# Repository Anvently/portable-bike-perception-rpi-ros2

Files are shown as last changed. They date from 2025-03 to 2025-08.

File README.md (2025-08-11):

# Cyclo-safe : a multi-sensor bike perception module (Camera, Dual 360° Lidar, GPS, Raspberry Pi, ROS2)

> The aim of the CycloSafe project is to improve cyclist safety by rigorously quantifying the risks they face, with a particular focus on those occurring when being overtaken by a motor vehicle.
> 
> To do this, we have equipped a bicycle with LIDARs (Light Detection and Ranging), a camera and a GNSS antenna.

This repository contains :
- the firmware intended to run on a **Raspberry Pi** to operate all the sensors and **take measurements**
- Various tools to **export**, **visualize**, and **analyze** the collected data
- Files required for **3D printing the case**
- File needed to manufacture the **dedicated PCB**.  
It was developed as part of an experimental data acquisition system for an academic research study on cyclist safety.

https://github.com/user-attachments/assets/d5b68dda-f3fe-4f50-86e3-c243446fb8e7

## Structure

> [**core/**](core/README.md): Directory intended to be installed on the Raspberry Pi. Contains:
> 	- ROS installation script
> 	- CycloSafe environment setup script
> 	- systemd services setup script
> 	- source code for the different ROS nodes

> [**design/**](design/README.md): Contains files related to the machining of the case and the dedicated PCB.

> [**scripts/**](scripts/README.md): Contains scripts useful for retrieving and exporting data.

> [**viewer/**](viewer/README.md): Directory intended to be installed on the host machine. Contains a set of tools for visualizing and analyzing the data.
> - [**ROS2.md**](viewer/ROS2.md): Documentation related to ROS2 and its use in the project.

> [**network.md**](network.md): Instructions for network configuration on both the host and the Raspberry Pi, enabling interaction between the two machines.

## About the Cyclo-safe project

This project is part of the broader **CycloSafe** research initiative conducted at the **Institut national de l’information géographique et forestière (IGN)**, which aims **to quantify the risks faced by cyclists when being overtaken by motor vehicles**.

This repository is dedicated **exclusively to the design and implementation of the acquisition module** used to collect measurement data for the study, along with a set of **tools for processing, visualizing, and analyzing** the recorded data.

It does **not** present or discuss the **results** of the study itself, and should not be directly associated with its conclusions or interpretations.

For more information on the full **CycloSafe** study, see:  
Emmanuel Cledat, Dirk Lauinger, Aymeric Dutremble, Maeve Blarel, Damien Louis Peller, Tristan Geslain, Alexandre Esteoulle, Elisabeth Giroux, Gabin Bourlon, Nicolas Pirard, Eric Ta — ***Cyclo-Safe: Quantitative study of the risks to which cyclists are exposed during their daily commute***.

## License

This project is licensed under the **CeCILL-B v1** license, a free software license fully compliant with French law, **based on the BSD 2-Clause license** and the principles of open source.

**Scope of the license** — The following materials are covered by the CeCILL-B license:
- Firmware code based on ROS2
- All project installation scripts and data analysis scripts
- Source code of data analysis tools, based on Qt and ROS2
- PCB design files
- 3D models and any corresponding f3d source files
- Assembly and user manuals for the module

You are **free to**:
- Use, modify, and redistribute this project under the terms of the CeCILL-B license
- Use this project for both **academic** and **commercial** purposes, without the strong copyleft constraints of GPL-like licenses
- Incorporate this code into proprietary software, as long as you respect the attribution requirements

You must:
- Include a copy of the CeCILL-B license with any redistributed version
- Retain notices of authorship and copyright
- Clearly indicate any modifications made

Author: [Nicolas Pirard (@Anvently)](https://github.com/Anvently)  
Contact: [pirard.nicolas@hotmail.fr](mailto:pirard.nicolas@hotmail.fr)  
Additional contributors: See [CONTRIBUTORS.md](./CONTRIBUTORS.md)

📄 Full license text: [CeCILL-B v1](http://www.cecill.info/licences/Licence_CeCILL-B_V1-en.html)  

📄 French version: [CeCILL-B v1](https://cecill.info/licences/Licence_CeCILL-B_V1-fr.html)  

---

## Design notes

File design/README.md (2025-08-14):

# Cyclosafe design

Ce dossier contient les fichiers relatifs à la fabrication du boitier destiné à recevoir tous les composants ainsi que les fichiers de fabrication du PCB dédié.

- [Cyclosafe design](#cyclosafe-design)
- [Liste du matériel (BOM)](#liste-du-matériel-bom)
	- [COMPOSANTS](#composants)
	- [Quincaillerie](#quincaillerie)
	- [Inserts](#inserts)
	- [Total](#total)
- [Electronique](#electronique)
	- [Montage complet](#montage-complet)
	- [PCB dédié](#pcb-dédié)
		- [Fonctions](#fonctions)
		- [Schéma](#schéma)
		- [Aperçu](#aperçu)
- [Boitier imprimé en 3D](#boitier-imprimé-en-3d)
	- [Module waveshare UPS hat](#module-waveshare-ups-hat)
		- [Spécifications](#spécifications)
		- [Aperçu](#aperçu-1)
- [Fixation au vélo](#fixation-au-vélo)
- [Module de mesure amovible](#module-de-mesure-amovible)
	- [Partie haute](#partie-haute)
	- [Partie basse](#partie-basse)

---

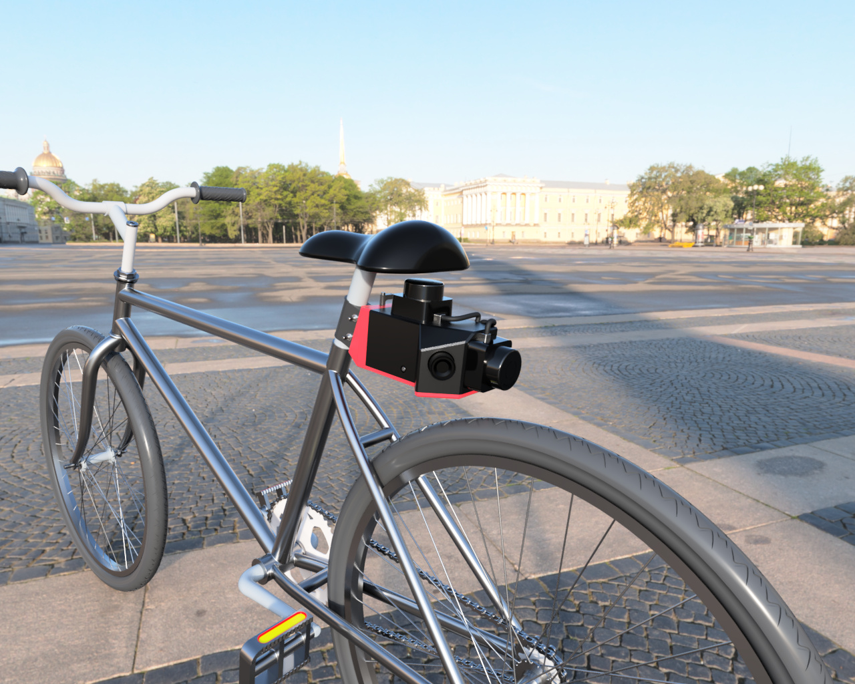
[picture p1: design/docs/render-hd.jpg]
preview-velo-avec-module


https://github.com/user-attachments/assets/05b4201d-2b15-44bb-a8c5-ab20a0cb3d47

# Liste du matériel (BOM)

## COMPOSANTS

| Quantité | Nom de la pièce | Fonction | Masse (g) | Type | Origine | Coût estimé |
|---|---|---|---|---|---|---|
| 1 | Raspberry Pi 4 Model B | Firmware | 75.00 | PCB | Achat | 65.00 |
| 1 | UPS-HAT | Batterie | 120.00 | PCB | Achat | 22.00 |
| 1 | PCB custom | Électronique | 30.00 | PCB | Fabrication par un tiers | 8.75 |
| 1 | Raspberry Pi HQ Camera M12 mount | Capteur | 30.40 | Capteur | Achat | 52.00 |
| 1 | Objectif grand angle M12 | Capteur | 100 | Accessoire | Achat | 25.00 |
| 2 | Slamtec RPLiDAR C1 | Capteur | 110.00 | Capteur | Achat | 84.00 |
| 1 | Assemblage F | Fixation | 90.00 | Structure | Impression | 2.00 |
| 1 | Collier | Fixation | 37.00 | Structure | Impression | 0.5 |
| 1 | L76x GPS Module | Capteur | 5.00 | PCB | Achat | 15.00 |
| 1 | Boîtier bas | Structure | 130.00 | Structure | Impression | 1.89 |
| 1 | Boîtier haut | Structure | 101.00 | Structure | Impression | 2.23 |
| 1 | Carte SD | Firmware | 2.00 | Accessoire | Achat | 25.00 |
| 2 | Accu 18650 - 3400mAh | Batterie | 46.00 | Accessoire | Achat | 18.50 |
| 1 | Couvercle carte SD | Structure | 3.30 | Structure | Impression | 0.07 |
| 1 | Ficelle pour pin de verrouillage (diamètre < 2mm) | Fixation | 1.00 | Accessoire | Achat | 0.05 |
| 1 | Pin de verrouillage | Fixation | 1.65 | Structure | Impression | 0.05 |
| 1 | Câble molex picoblade 510210800 8-pin double-M 20cm | Connection gps-pcb | 2.00 | Accessoire | Achat | 0.50 |

## Quincaillerie

| Quantité | Nom de la pièce | Fonction | Masse (g) | Type | Origine | Coût estimé |
|---|---|---|---|---|---|--|
| 1 | Vis à tête hexagonale M2.5x6 | Trappe carte SD | 0.487 | Quincaillerie | Achat | 0.05
| 4 | Entretoise M/F M2.5x12 | Entretoise Raspberry | 1.999 | Quincaillerie | Achat | 0.50
| 4 | Entretoise M/F M2.5x18 | Entretoise HAT | 2.393 | Quincaillerie | Achat | 0.50
| 8 | Vis à tête hexagonale M2.5x12 | Lidars | 0.702 | Quincaillerie | Achat | 0.05
| 2 | Vis à tête hexagonale M2x8 | GPS | 0.341 | Quincaillerie | Achat | 0.05
| 3 | Vis à tête hexagonale M3x6 | Boîtiers | 0.796 | Quincaillerie | Achat | 0.05
| 8 | Vis à tête hexagonale M2.5x10 | UPS HAT & caméra | 0.630 | Quincaillerie | Achat | 0.05
| 1 | Vis à tête hexagonale M3x0.5x40 | Axe centrale du pin de blocage | 2.569 | Quincaillerie | Achat | 0.10
| 2 | Vis à tête hexagonale M4x0.7x40 | Collier | 4.776 | Quincaillerie | Achat | 0.10

## Inserts

| Quantité | Nom de la pièce | Fonction | Masse (g) | Type | Origine | Coût estimé
|---|---|---|---|---|---|--|
| 2 | Insert M4x8x6 | Collier | 2.00 | Quincaillerie | Achat | 0.08
| 1 | Insert M3x4x4.5 | Emboîtement supérieur | 1.00 | Quincaillerie | Achat | 0.05
| 2 | Insert M3x3x4.5 | Emboîtement latéral | 1.00 | Quincaillerie | Achat | 0.04
| 4 | Insert M2.5x4x3.5 | Raspberry | 1.00 | Quincaillerie | Achat | 0.04
| 2 | Insert M2x5x3.5 | GPS | 1.00 | Quincaillerie | Achat | 0.04
| 5 | Insert M2.5x5x3.5 | Couvercle SD + caméra | 1.00 | Quincaillerie | Achat | 0.04

## Total

| Quantité | Nom de la pièce | Fonction | Masse (g) | Type | Origine |Coût estimé
|---|---|---|---|---|---|--|
|Poids|||1102.25||
|Coût||||||431.17€

# Electronique

Le coeur du boitier comporte un assemblage de 3 circuits imprimés emboités les uns par desus les autres :
- un rapbeerry Pi 4B sur lequel vient se brancher la caméra
- un PCB personnalisé sur lequel vient se brancher les capteurs (2 LiDARS + un module GNSS)
- un module UPS (*Uninterruptible Power Supply*) alimentés par deux accus 18650 permettant de fournir le courant nécessaire (jusqu'à 3A), de protéger le circuit et de gérer la recharge

## Montage complet

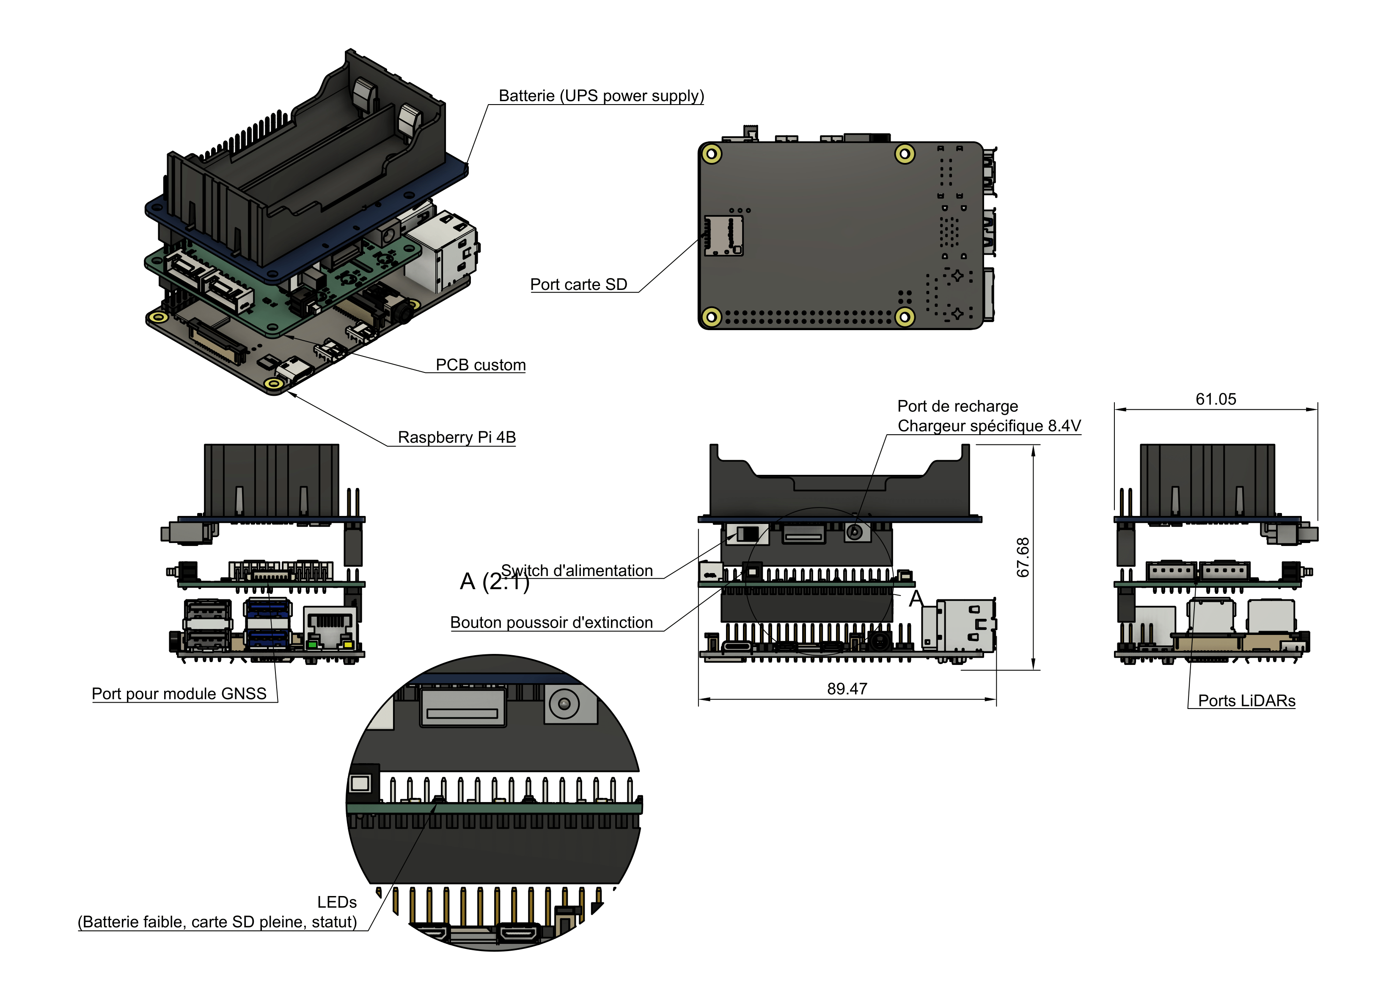
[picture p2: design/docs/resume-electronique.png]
assemblage-hat


## PCB dédié

 ### Fonctions
- permet de connecter les capteurs aux différentes interfaces UARTs du raspberry :
  - UART1 : LiDAR 1 (supérieur)
  - UART2 : LiDAR 2 (arrière)
  - UART5 : module GNSS
- intègre 3 LEDs pour avertir l'utilisateur des situations suivantes :
  - batterie faible (< 20 %) : voyant rouge allumé
  - carte sd pleine : voyant bleu allumé
  - démarrage/arrêt en cours : voyant jaune allumé sans clignotement
  - mesure en cours : voyant jaune clignotant
- intègre un bouton poussoir permettant de déclencher l'arrêt des mesures et d'éteindre en douceur le raspberry

### Schéma

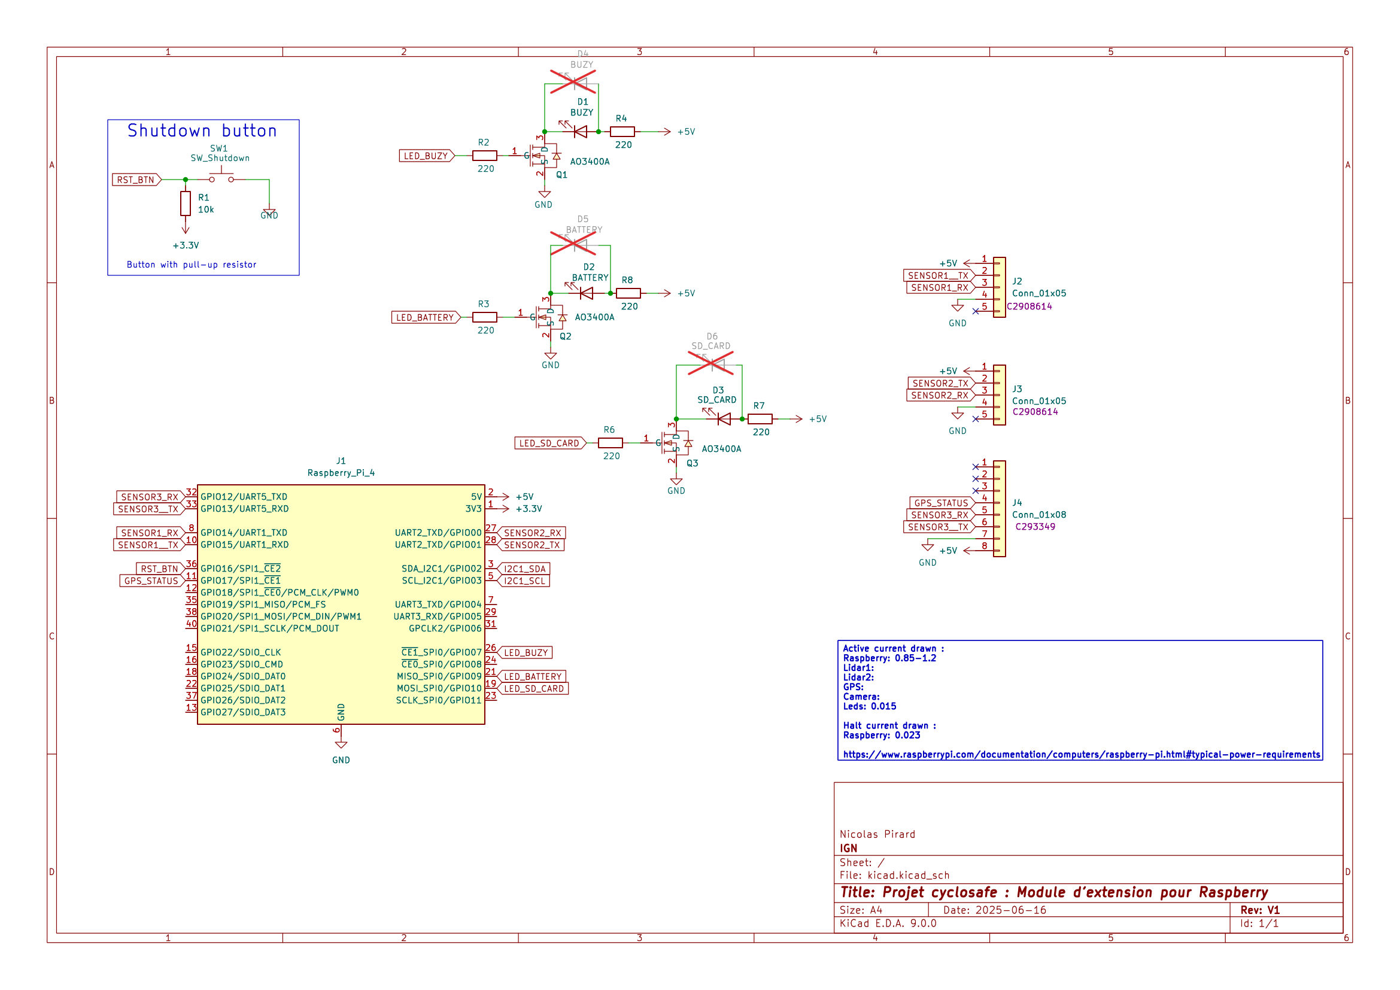
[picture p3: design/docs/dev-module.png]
schéma-circuit


### Aperçu

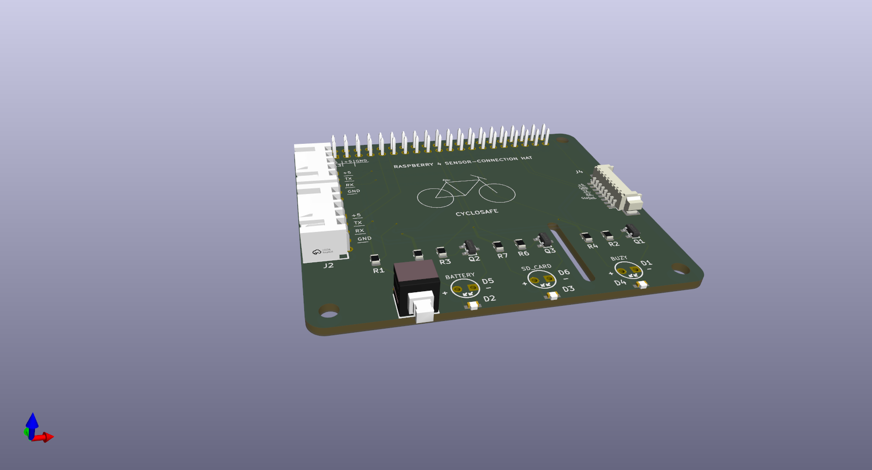
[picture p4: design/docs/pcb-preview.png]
preview-du-pcb


# Boitier imprimé en 3D

Le dossier [`kicad/`](kicad/) contient le projet Kicad 9.0 d'un PCB sur lequel viennent se brancher les différents capteurs et composants actifs (LEDs et bouton d'extinction).

Il prend la forme d'un hat pour raspberry et se connecte via le header de 40 pins.

## Module waveshare UPS hat

Il s'agit d'une alimentation non interruptible commercialisée par Waveshare.

### Spécifications

- alimenté par 2 accus 18650
- permet une utilisation constante du raspberry via batterie ou pendant la recharge sur secteur
- protection contre les court-circuits, polarité inversée, surcharge/décharge des batterie
- jusqu'à 2.5A en 5V
- monitoring de la tension des batteries (permettant de calculer le pourcentage restant) et de la consommation instantanée

### Aperçu

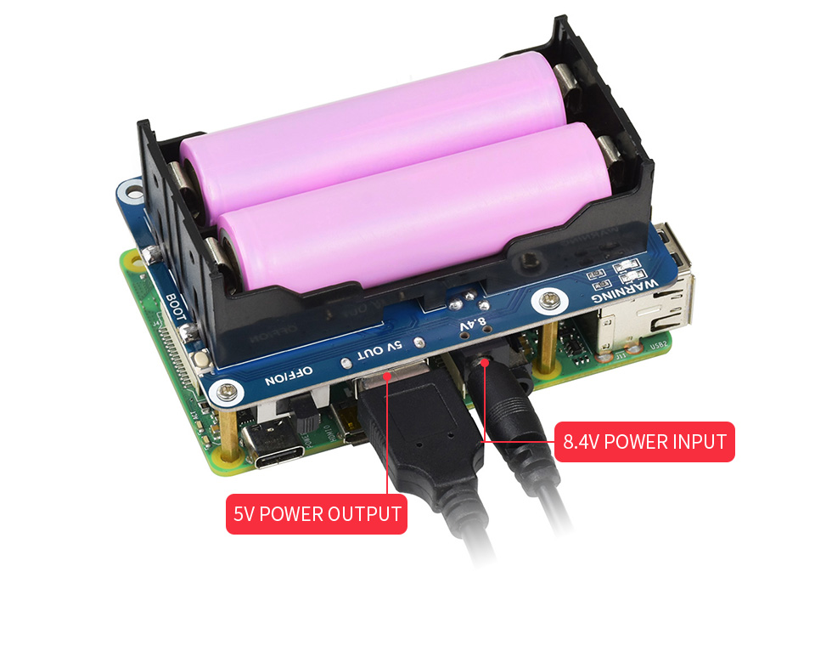
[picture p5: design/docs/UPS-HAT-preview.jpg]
Waveshare-ups-hat-preview


# Fixation au vélo

Cette partie là demeure sur la tige selle.

Un collier facilement déformable est placé autour de la tige selle et vient verrouiller l'assemblage femelle avec deux vis M4.

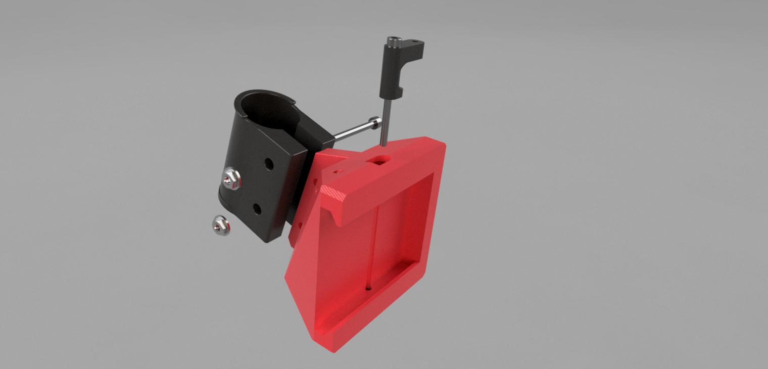
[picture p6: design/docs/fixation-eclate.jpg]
preview-fixation


Le design du  collier est basé sur  par [**<ins>un modèle réalisé par Metamere</ins>**](https://www.printables.com/model/125810-bens-better-dropper-post-seat-bag-adapters-264-22-)  trouvé sur *printables.com* et distribué sous licence Creative Commons.

Il a été allongé, épaissi et simplifié par rapport au modèle original.

Le sytème de fixation est inspiré de celui du projet Open Source [**<ins>Open bike sensor</ins>**](https://github.com/openbikesensor/OpenBikeSensor3dPrintableCase), en particulier le système de glissière entre le support fixe demeurant sur la tige selle et le boitier principal.

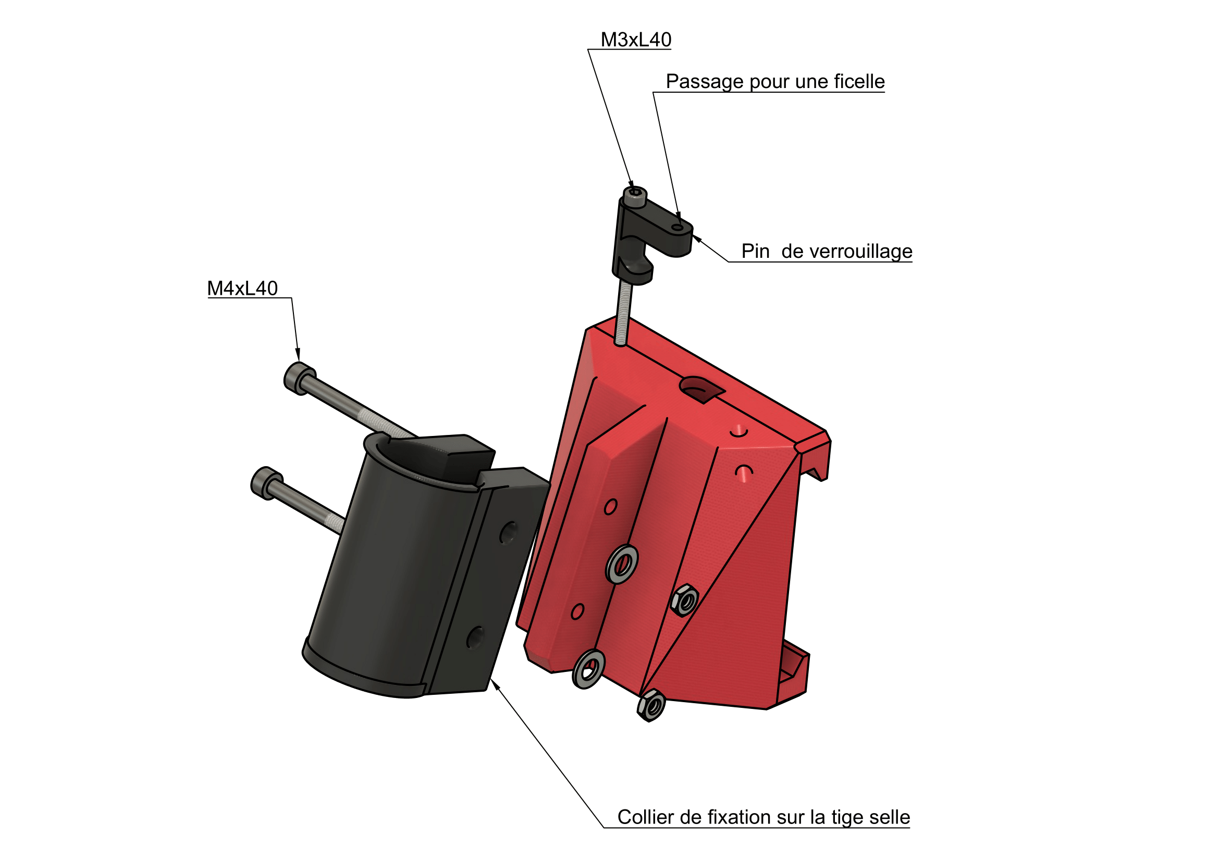
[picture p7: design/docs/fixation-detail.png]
schema-assemblage-tige-selle


# Module de mesure amovible

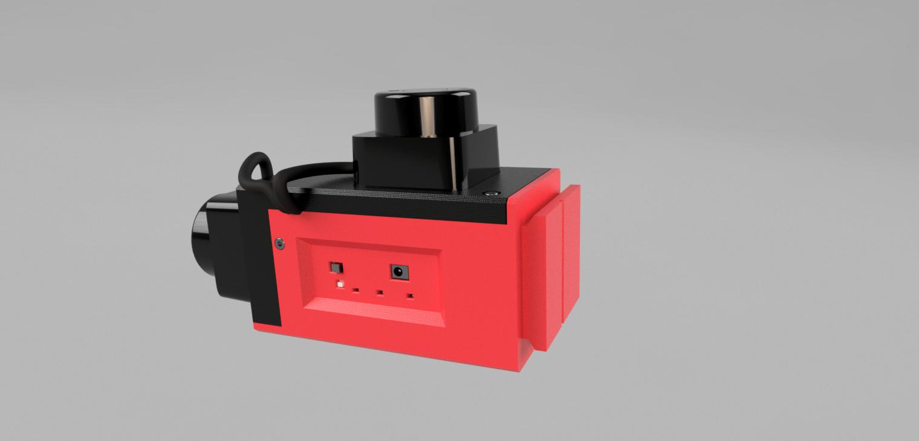
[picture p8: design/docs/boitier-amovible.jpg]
preview-boitier


Il vient se glisseer dans l'assemblage femelle fixé sur la tige selle.

Le pin de verrouillage de la fixation s'insère dans un des trous prévus à cet effet et peut tourner sur lui-même afin de maintenir l'assemblage en place (un de chaque côté selon la place disponible sous ou au dessus du boitier).

Il se compose d'une partie basse et d'une partie haute qui viennent se clipser ensemble. 3 vis M3 permettent de verrouiller l'assemblage des deux boitiers.

## Partie haute

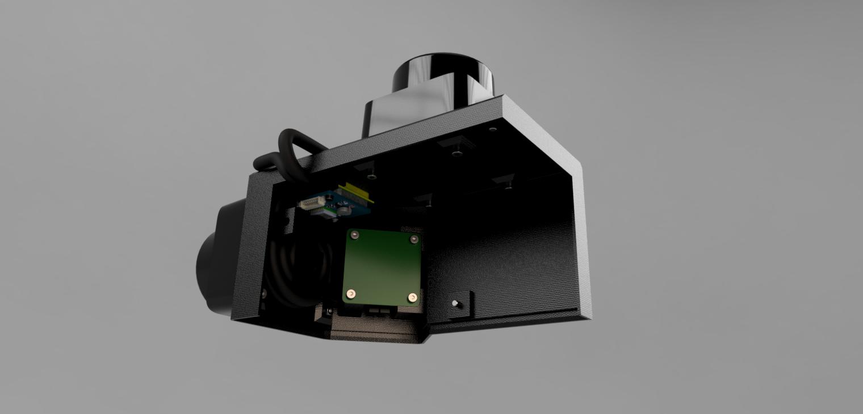
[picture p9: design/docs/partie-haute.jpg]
Partie haute

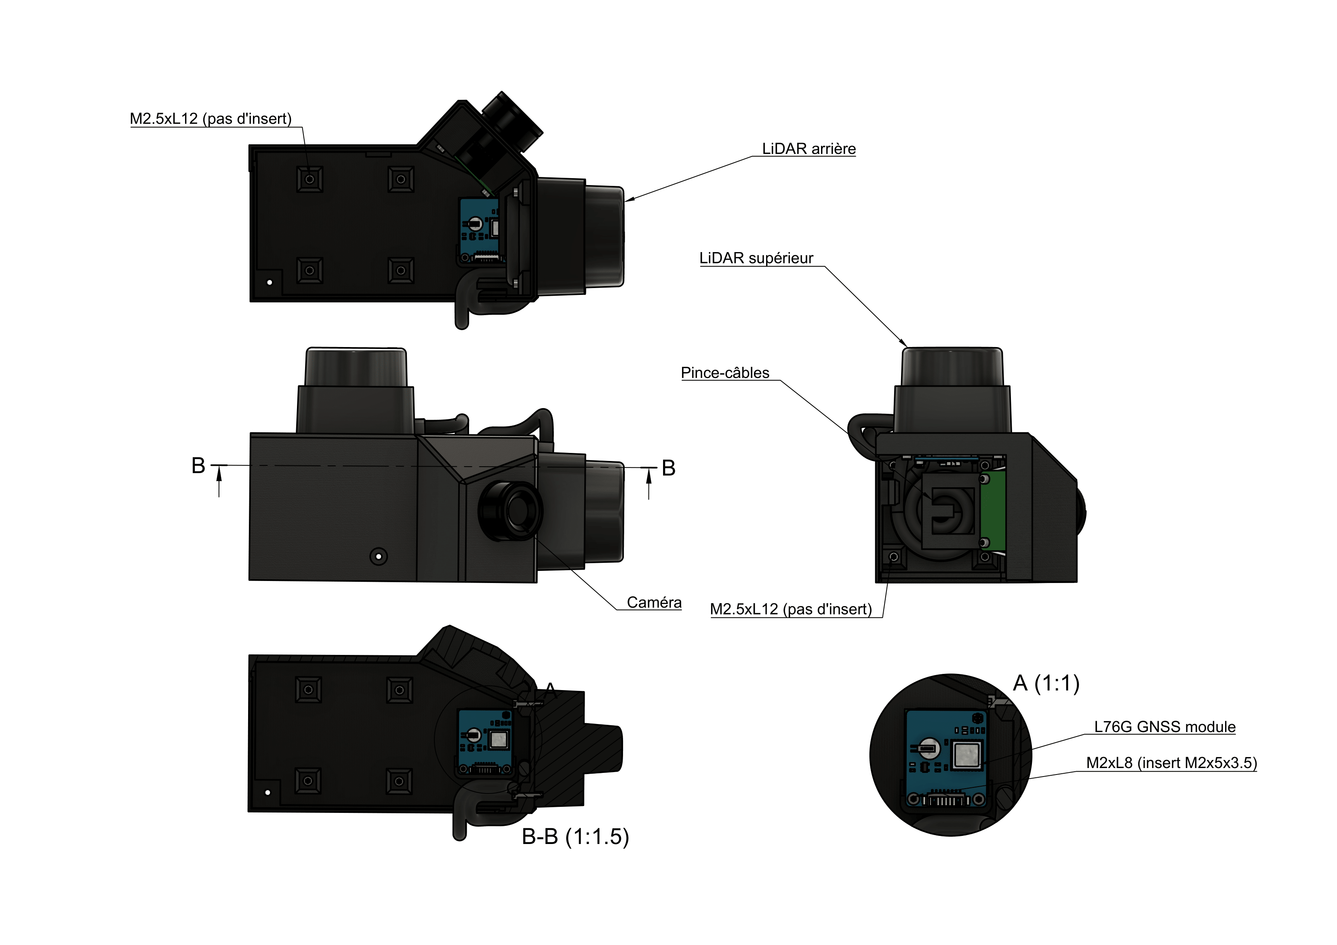
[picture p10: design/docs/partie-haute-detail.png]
schéma partie haute


## Partie basse

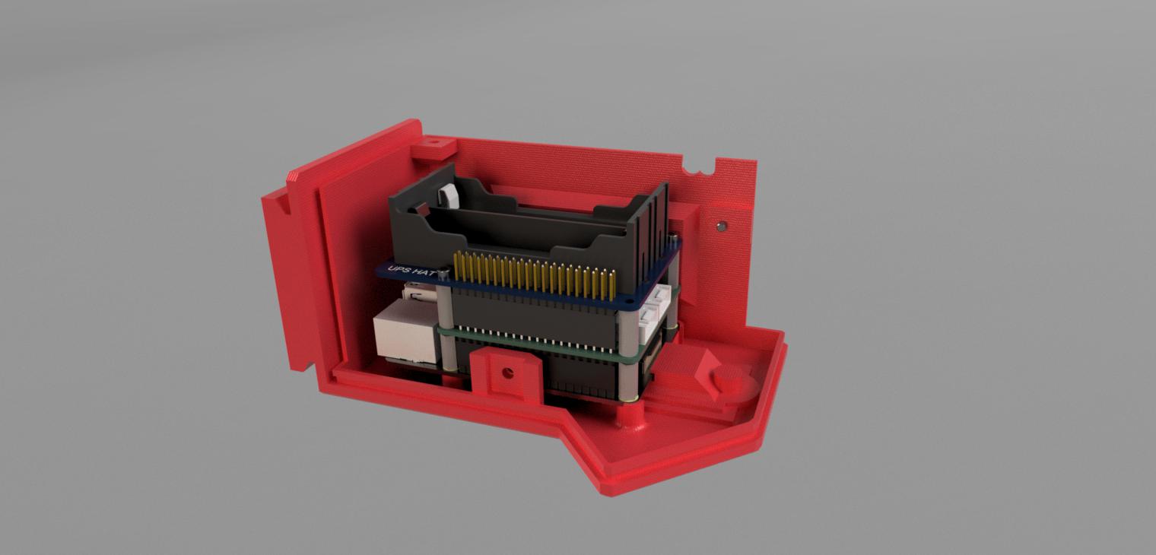
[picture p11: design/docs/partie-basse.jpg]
Partie basse

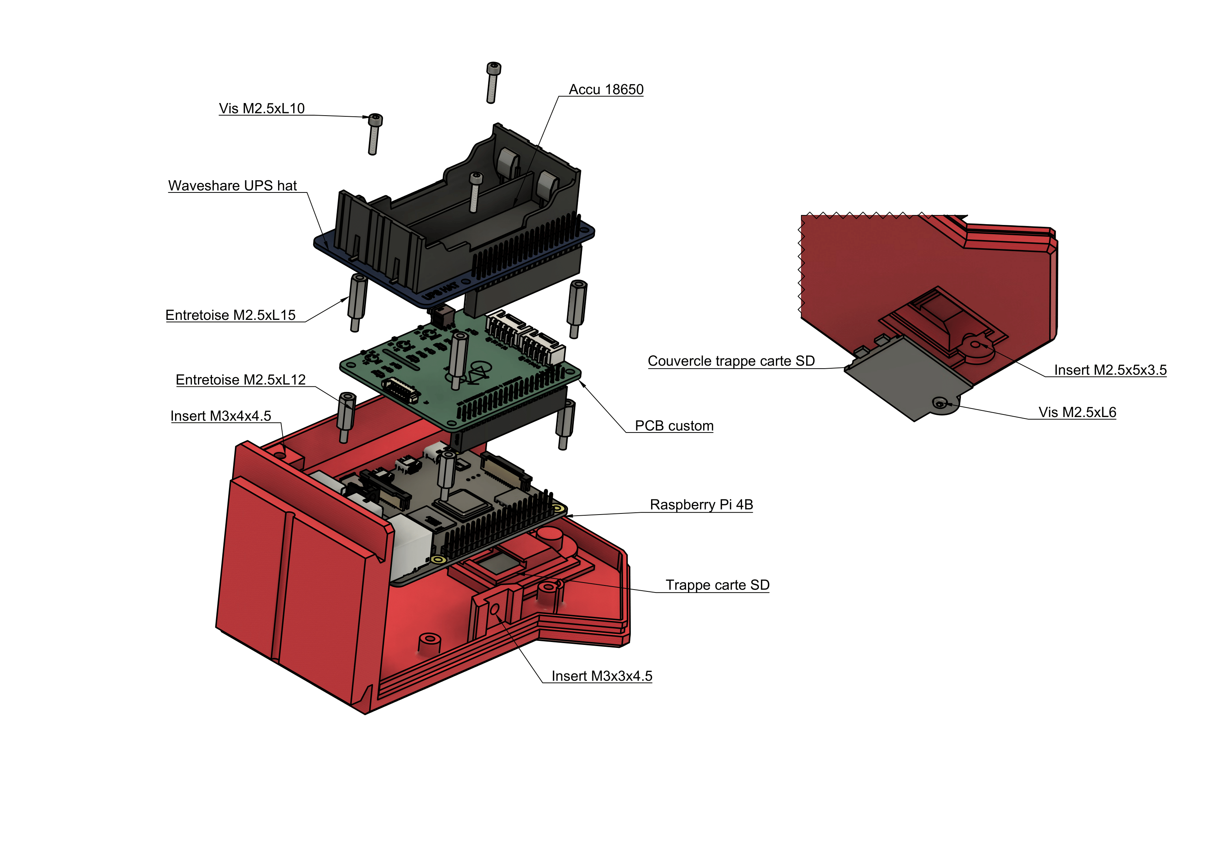
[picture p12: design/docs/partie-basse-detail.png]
partie-basse-detail


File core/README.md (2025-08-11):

# Cyclosafe core 

Ce repo contient tous les packages et utilitaires nécessaires à la prise des mesures. Cela correspond à l'ensemble des noeuds et des scripts qui doivent tourner sur le raspberry.

- [Cyclosafe core](#cyclosafe-core)
	- [Flasher la carte SD](#flasher-la-carte-sd)
	- [Installation (sans l'image du firmware)](#installation-sans-limage-du-firmware)
	- [Usage](#usage)
		- [Sourcer l'environnement](#sourcer-lenvironnement)
		- [Sourcer l'environnement à l'ouverture d'un nouveau terminal](#sourcer-lenvironnement-à-louverture-dun-nouveau-terminal)
		- [Pour compiler l'ensemble des packages](#pour-compiler-lensemble-des-packages)
		- [Démarrer la prise de mesure](#démarrer-la-prise-de-mesure)
		- [Activer/désactiver la prise de mesures avec enregistrement au démarrage du raspberry](#activerdésactiver-la-prise-de-mesures-avec-enregistrement-au-démarrage-du-raspberry)
	- [Documentation](#documentation)
		- [Détails sur les packages et les différents noeuds](#détails-sur-les-packages-et-les-différents-noeuds)
		- [Introduction à ROS2 et glossaire de ses différents concepts](#introduction-à-ros2-et-glossaire-de-ses-différents-concepts)
		- [Détails sur l'installation](#détails-sur-linstallation)
		- [Scripts](#scripts)
		- [Services systemd](#services-systemd)
		- [Documentation ROS 2](#documentation-ros-2)
	- [Installation hors-ligne](#installation-hors-ligne)
		- [Configurer le sous-réseau](#configurer-le-sous-réseau)

## Flasher la carte SD

> Suppose que vous vous êtes procuré l'image `cyclosafe_firmware.img.xz`.

Une fois la carte SD branché dans le PC, exécutez la commande suivante (remplacer `/dev/sdX` par le nom de la carte SD détectée par l'OS (généralement `/dev/sda`)):

~~~
xz -dc cyclosafe_firmware.img.xz | sudo dd of=/dev/sdX bs=4M status=progress && sync && sudo eject /dev/sdX
~~~

- `xz -dc cyclosafe_firmware.img.xz` : décompresse l'image
- `| sudo dd of=/dev/sdX bs=4M` : redirige l'image décompressée vers la carte SD. 
- `&& sync` : vérifie que tout a bien été écrit sur le disque
- `&& sudo eject /dev/sdX` : ejecte la carte SD qui peut désormais être arrachée.

Au premier démarrage de la carte sur un raspberry, la taille de la partition sera étendu automatiquement en fonction de l'espace disponible sur la carte SD et les mesures démarreront aussitôt.

## Installation (sans l'image du firmware)

> Suppose un accès internet sur le raspberry.
> Si le raspberry n'a pas accès à internet, privilégiez [**une installation hors ligne**](#installation-hors-ligne).

> Si vous avez flashé une carte SD avec le firmware de cyclosafe, vous pouvez ignorer cette section car tout y est déjà installé.
> 
> Sinon veillez à flasher une distribution **64 bits de Raspberry OS** (il est recommandé d'utiliser la version **lite** sans interface graphique).
>
> Il est recommandé de nommer l'utilisateur par défaut `cycliste`, par cohérence avec les exemples donnés dans la documentation.

~~~
git clone https://github.com/Anvently/Cyclosafe-firmware ~/cyclosafe
cd ~/cyclosafe/core
~~~

Installation complète
~~~
./setup/install.sh
~~~

Pour configurer les services seulement
~~~
./setup/systemd/setup_services.sh
~~~

## Usage

### Sourcer l'environnement
~~~
source ./setup/.bashrc
~~~

### Sourcer l'environnement à l'ouverture d'un nouveau terminal

~~~
$(cat ./bashrc) >> ~/.bashrc
~~~

### Pour compiler l'ensemble des packages

~~~
source ./setup/.bashrc
cy_core_build
~~~

### Démarrer la prise de mesure

~~~
ros2 launch cyclosafe cyclosafe.launch.py record:=false # (sans enregistrement)
ros2 launch cyclosafe cyclosafe.launch.py record:=true # (avec enregistrement)
~~~

### Activer/désactiver la prise de mesures avec enregistrement au démarrage du raspberry

~~~
sudo systemctl enable cyclosafed.service # Activer
sudo systemctl disable cyclosafed.service # Désactiver
~~~

## Documentation

### Détails sur les packages et les différents noeuds

[**cyclosafe.md**](cyclosafe.md)

### Introduction à ROS2 et glossaire de ses différents concepts

[**ROS2.md**](../viewer/ROS2.md)

### Détails sur l'installation

[**setup/README**](setup/README.md)

### Scripts

[**scripts/README**](scripts/README.md)

### Services systemd

[**setup/systemd/README**](setup/systemd/README.md)

### Documentation ROS 2

**Documentation officielle** :

https://docs.ros.org/en/jazzy/Tutorials.html

La suite de tutoriel basés sur **turtlesim** est une bonne façon d'appréhender les différents concepts de ROS : https://docs.ros.org/en/jazzy/Tutorials/Beginner-CLI-Tools.html

**Excellente source de tutoriels et compléments*** : 

https://roboticsbackend.com/category/ros2/

## Installation hors-ligne

Si vous avez déjà accès au raspberry en ssh ou si le dossier core est déjà sur le raspberry, vous pouvez ignorer cette section et procéder à l'installation du [**core/**](./) sur le raspberry.

Autrement il est possible de procéder à une installation complètement vierge depuis l'hôte vers le raspberry.

### Configurer le sous-réseau

La première étape est de permettre la connexion ssh vers raspberry.

Pour cela suivez les [**instructions de configuration réseau**](../network.md), pour configurer les profils réseaux de l'hôte du raspberry (pour une installation complète il est aussi nécessaire que le raspberry ait accès à Internet).

Une fois le réseau configuré, vous pouvez simplement copier le dossier `core` vers le raspberry à l'aide de la commande suivante (remplacer `user` par l'utilisateur choisi lors de l'installation de raspberry OS) :

Depuis l'hôte :
~~~
scp -r ./core cyclist@192.168.2.2:/home/user/cyclosafe/core
~~~

Connectez-vous ensuite en ssh :

~~~
ssh cycliste@192.168.2.2
~~~

Vous avez désormais accès au raspberry.

Vous pouvez quitter la fenêtre ssh avec CTRL-D ou en fermant le terminal.

Pour poursuivre l'installation :

~~~
cd /home/$USER/cyclosafe/core
cat README.md
~~~

[**Voir les instructions**](#usage)

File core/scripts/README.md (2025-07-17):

# Core scripts

Contient les scripts destinés à tourner sur le raspberry.

Le chemin vers ces scripts doit être indiqué par la variable d'environnement **SCRIPTS_PATH**.

## gpio.py

Script ayant plusieurs fonctions :

- monitoring du bouton d'extinction : Retourne 255 (-1) lors de l'appui du bouton
- contrôle des leds : clignotement des led
- monitoring de la batterie : mesure la tension toutes les 10s. Retourne 254 (-2) si la tension est inférieure à la tension minimale.
- monitoring de l'espace de stockage restant : un espace insuffisant déclenche le voyant de stockage plein mais ne provoque pas l'arrêt de raspberry

### Valeurs par défaut (paramètrables dans gpio.py)

- **BTN_RST_GPIO=16** : gpio pin auquel est connecté le bouton d'arrêt.
- **LED_BATTERY_GPIO=9** : gpio pin de la led batterie faible
- **LED_BUZY_GPIO=7** : gpio pin de la led d'état
- **LED_SD_CARD_GPIO=10** : gpio pin de la led stockage plein
- **BUTTON_SHUTDOWN=255** : valeur de retour (alias code d'erreur) pour un appui sur le bouton. **NE PAS MODIFIER (à moins de corriger le script gpio.sh en conséquence)**
- **BUTTON_SHUTDOWN=254** : valeur de retour (alias code d'erreur) pour une batterie faible (voltage trop faible). **NE PAS MODIFIER (à moins de corriger le script gpio.sh en conséquence)**
- **NBR_CELLS=2** : nombre d'accus dans la batterie
- **CHARGE_VOLTAGE=4.2** : tension de charge d'un accu, cette valeur * le nombre d'accus définit la tension maximale de la batterie (lorsqu'elle est à 100%)
- **MIN_VOLTAGE=3** : tension minimale d'un accu.

**Ex:** Avec nbr_cells=2 et min_voltage=3, la tension de seuil à partir de laquelle le raspberry est éteint est de 2*3=6V

## gpio.sh

Script lancé au démarrage par [**gpiod.service**](../setup/systemd/README#gpiodservice).

Service ayant plusieurs fonctions :

- log des heures de démarrage et d'extinction du raspberry dans *****$CYCLOSAFE_LOGS**/cyclosafe.log*** + cause de l'extinction (batterie ou bouton)
- lance le script python (**gpio.py**)
- teste la valeur de retour du script et déclenche l'arrêt du raspbbery ssi le code d'erreur correspond à un appui sur le bouton ou à un voltage trop faible sur la batterie.
- déclenche l'arrêt du raspberry via ***sudo systemctl stop cyclosafe.service***. Respecte le délai configuré (`$SHUTDOWN_DELAY`), vérifie que le service a bien été arrêté (log de warning le cas échéant) et passe le raspberry en mode halt (extinction du bus d'alimentation, du bus USB, et consommation minimale de 23mA environ).

### Variables d'environnement liées

> **SHUTDOWN_DELAY** : ajuste le temps du sleep  entre la commande d'arrêt du service cyclosafed.service et l'extinction du raspberry. La valeur du sleep étant définie à **SHUTDOWN_DELAY + 1**.

> **CYCLOSAFE_LOGS** : définit le répertoire où on_off.log est enregistré

## battery_monitor.py

Implémente un driver python de la puce INA219 permettant de prendre des mesures de la tension de batterie et de consommation instantanée. Utilisé par **gpio.py**.

Basé sur : https://github.com/DFRobotdl/INA219-Python
Modifs:
- ajout d'une fonction get_battery_pourcent

Peut-être lancé seul pour afficher différentes informations sur la batterie et sur la puissance instantanée : ***python3 ./battery_monitor.py***

## gps_time.sh

Script lancé au démarrage par [**gps_time.service**](../setup/systemd/README#gps_timeservice).

Mets à jour l'heure et la date du système à partir des frames NMEA envoyées par un GPS connecté en serial.

Si le GPS n'a pas de pile ou si celle-ci est défectueuse, l'heure envoyée par le GPS ne sera pas correcte tant qu'il n'aura pas pu fixer la position. Pour pallier à cela, une date est considérée comme "valide" si elle est comprise entre le **17/07/2025** et le **17/07/2055**.

### Variables d'environnement liées

> **CYCLOSAFE_LOGS** : le script log ses tentatives dans ***$CYCLOSAFE_LOGS/gps_time_sync.log***

> **GPS_SERIAL_PORT** : port serial auquel est connecté le GPS.

## launch_wrapper.sh

Script lancé au démarrage par [**cyclosafed.service**](../setup/systemd/README#cyclosafedservice).

Service ayant plusieurs fonctions :

- sourcer l'environnement ROS puis lancer la [**launch  description principale**](../src/cyclosafe/README.md#launch-description)
  - si l'espace restant sur la carte SD est inférieur à `LOW_STORAGE_TRESHOLD`, les données mesurées ne seront pas enregistrées.
- monitoring de la launch description de la [**launch  description principale**] : si un des noeuds ne se lance pas correctement ou s'arrête en cours d'exécution, l'ensemble des noeuds sont relancés.
- log du démarrage/arrêt des mesures dans ***$CYCLOSAFE_LOGS/cyclosafe.log***

### Variables d'environnement liées

> **LOW_STORAGE_TRESHOLD** : espace de stockage (en MO) disponible en dessous duquel s'allume le voyant de stockage plein.

> **CYCLOSAFE_LOGS** : définit le répertoire où on_off.log est enregistré

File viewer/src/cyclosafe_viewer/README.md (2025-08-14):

# cyclosafe_viewer

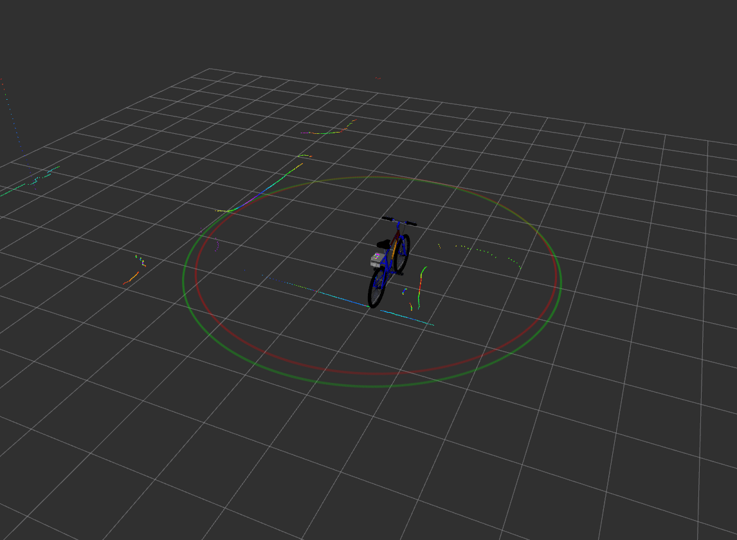
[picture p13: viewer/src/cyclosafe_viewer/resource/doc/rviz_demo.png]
rviz_visualisation_demo


Package python implémentant plusieurs choses

- la launch description [**viewer.launch.py**](#) permettant de lancer simultanément tous les outils de visualisation à partir de données en directes ou d'un [`rosbag`](../../ROS2.md#bag-ou-rosbag) à revisionner.
- des noeuds ROS destinés à tourner pendant la visualisation des données :
  - [**gps_converter.py**](#) : noeud permettant la conversion de `cyclosafe_interfaces/msg/NavSatInfo` en `sensor_msgs/msg/NavSatFix`.
  - [**range_circle_transform.py**](#) : génère des cercles à partir de `geometry_msgs/msg/Point` pour représenter les `sensor_msgs/msg/Range` publiées.
- une description [`URDF`](../../ROS2.md#urdf---unified-robot-description-format) incluant les modèles 3D du vélo et des capteurs et permettant de définir les transformations à effectuer entre les différentes [`frames`](../../ROS2.md#frame---repère).

# viewer.launch.py

## Usage

Pour visualiser un bag :

~~~
ros2 launch cyclosafe_viewer viewer.launch.py bag:=~/data/import/20250522-093910/out/_0.mcap
~~~

Pour visualier les données en directe :

~~~
ros2 launch cyclosafe_viewer viewer.launch.py
~~~
Suppose que le raspberry est allumé et connecté via un cable ethernet.

> Aucune configuration réseau particulière n'est nécessaire. ROS2 publie par défaut ses messages sur le réseau.

## Fonctionnement

Cette launch description peut-être considérée comme le pendant pour la visualisation de la launch description [**cyclosafe.launch.py**](../../../core/src/cyclosafe/README.md#launch-description).

Voir la documentation associée aux launch descriptions sur ROS2 :

https://docs.ros.org/en/foxy/Tutorials/Intermediate/Launch/Creating-Launch-Files.html

Ou : https://roboticsbackend.com/ros2-launch-file-example/

Cette launch description :
- ouvre une fenêtre `Rviz`
- lit la configuration [**config.py**](launch/config.py) (ou celle donnée par le paramètre `config`) pour en extraire `sensors_list`. C'est une liste de [**Sensor**](../../../core/src/cyclosafe_config/README.md#classe-sensor) déclarant les propriétés de chacun des capteurs à représenter
- lance un noeud [**range_circle_transform**](#) pour représenter les distances envoyées par les sonars ou les lidars de la config. La couleur des [**Sensor**](../../../core/src/cyclosafe_config/README.md#classe-sensor) définit dans [**config.py**](launch/config.py) sont transmises au noeud.
- pour chaque [**Sensor**](../../../core/src/cyclosafe_config/README.md#classe-sensor) de la config qui nécessite une transformation : lance un [`static_transform_publisher`](../../ROS2.md#tf2)
- lance un [`static_transform_publisher`](../../ROS2.md#tf2) pour effectuer une transformation de la frame racine URDF `bicycle_link` vers la frame `world`
- lance un [`static_transform_publisher`](../../ROS2.md#tf2) pour effectuer une transformation de la frame `world` vers la frame `world_on_x` afin de permettre la visualisation la scène dans une vue orthogonale sur l'axe X (la seule vue orthogonale disponible sur Rviz étant sur l'axe Z).
- lance un [`robot_state_publisher`](../../ROS2.md#urdf---unified-robot-description-format) à partir de la description URDF pour générer l'arbre de transformation pour les différentes capteurs et modèles 3D.

Et en fonction des paramètres :

- si le paramètre `bag` est renseigné : lance une fenêtre `cyclosafe_player`
- si le paramètre `bag` n'est pas renseigné : ouvre une fenêtre `rqt_image_view` pour visualiser les images en direct
- si le paramètre `map` est activé : lance [**rviz_satellite**](../rviz_satellite/README.md), [**gps_converter.py**](#) pour convertir les messages gps dans le format attendu par rviz_satellite et un [`static_transform_publisher`](../../ROS2.md#tf2) pour transformer la frame world vers la frame map.

## Paramètres

> **config** : str
> - défaut: **""**
> - précise un chemin vers une config personnalisée à lancer
> - par défaut, utilise le fichier **config.py** situé dans le même dossier que la launch description.

> **bag** : str
> - défaut: **""**
> - précise le chemin vers un rosbag à partir duquel les données seront jouables via une fenêtre de `cyclosafe_player`.
>
> 	Accepte les bag au format **.mcap** ou compressé au format **.mcap.zstd** (le bag sera décompressé à l'ouverture).

> **map** : boolean
> - défaut: **"false"**
> - si `true`, un noeud [**rviz_satellite**](../rviz_satellite/README.md) sera lancé et une tuile d'une vue satellite *openstreeview* sera mappée à partir des positions GPS publiées.

> **invert_lidar** : boolean
> - défaut: **"false"**
> - si `true`, intervertit les transformations appliquées sur les frames des lidars (`robot_state_publisher` utilisera le fichier `urdf.model.inverted.xml`)

## Spécificités

La structure de [**viewer.launch.py**](launch/viewer.launch.py) n'est pas tout à fait standard dans la mesure où :
- Elle repose lourdement sur la déclaration préalable d'une liste globale de [**Sensor**](../cyclosafe_config/README.md#classe-sensor) importée depuis un fichier extérieur ([**config.py**](launch/config.py)).
  
  L'avantage est de centraliser tout ce qui peut varier d'un test à l'autre sur un seul fichier. On peut par exemple avoir un fichier **config1.py** et **config2.py** qui correspond à un certain prototype avec des capteurs spécifiques ou des paramètres différents.
  
  Si on veut ensuite visualiser les données prises par la **config1** et celle par la **config2**, on peut le faire simplement en précisant à **cyclosafe_viewer** la config adéquate.

- Elle utilise une **fonction opaque** pour résoudre la description au runtime.

  En effet l'essentiel de la description dépend des paramètres donnés ou du contenu du fichier [**config.py**](launch/config.py). Or une launch description correspondant en quelque sorte à une recette de lancement qui n'est pas paramètrable directement.

  L'utilisation de **OpaqueFunction()** permet de déclarer une fonction qui sera executé avec le contexte du runtime avant de de renvoyer la description définitive.

### Résumé des étapes de lancement

1. **Execution de la fonction opaque launch_setup()** avec le contexte (cad. les arguments transmis avec la commande **ros2 launch cyclosafe_viewer viewer.launch.py [...args])**
2. **Résolution des arguments**
3. **Ajout des différents noeuds selon les options activées** (voir [**fonctionnement**](#fonctionnement))
4. La description finale est renvoyée pour être lancée

# Noeuds

## gps_converter.py

Les outils cartographiques comme [**rviz_satellite**](../rviz_satellite/README.md) ou [**mapviz**](../mapviz/README.md) attendent de recevoir des `sensor_msgs/msg/NavSatFix`

Les messages publiés par le [**noeud gps**](../../../core/src/cyclosafe/README.md#gpspy) étant de type `cyclosafe_interfaces/msg/NavSatInfo`, il est donc nécessaire de les convertir.

Peut également permettre de générer un fichier gpx à la sortie, mais cette fonction a été supplantée par le script [**gpx_exporter**](../../../scripts/README.md#gpx_exporterpy), plus efficace et adapté dans la meesure ou gps_converter.py écrit les traces au fur et à mesure de la lecture dans un fichier.

### Usage

~~~
ros2 run cyclosafe_viewer gps_converter --ros-args -p topic_src:=/gps -p topic:=/nav_fix
~~~

Reçoit les messages publiés sur le topic `/gps`, les convertit en `sensor_msgs/msg/NavSatFix` et les publie sur le topic `/nav_fix`.

### Paramètres

> **topic_src** : str
> - défaut: **"/gps"**
> - topic sur lequel des `cyclosafe_interfaces/msg/NavSatInfo` sont publiés auquel souscrire

> **topic** : str
> - défaut: **"/nav_fix"**
> - topic sur lequel publier des `sensor_msgs/msg/NavSatFix` 

> **gpx_enabled** : boolean
> - défaut: **False**
> - Active/désactive l'enregistrement en direct des traces gpx dans un fichier

> **gpx_file_path** : str
> - défaut: **""**
> - détermine le chemin de sortie pour la trace gpx si l'option d'enregistrement est activée

> **gpx_track_name** : str
> - défaut: **"ROS2 GPS Track"**
> - Détermine comment nommer la trace dans le fichier GPX.

# Modèle URDF

Format XML standardisé pour décrire la structure physique d'un robot, incluant ses liens (links), articulations (joints), propriétés visuelles et de collision.

**viewer.launch.py** utilise un modèle URDF pour positionner dans l'espace les modèles 3D du vélo et des capteurs, et pour définir les transformations à effectuer pour replacer les données dans l'espace.

Fonctionne avec le [package](#package) `robot_state_publisher` qui prend en entrée une description [URDF](#urdf---unified-robot-description-format) et génère automatiquement l'arbre de transformation [`tf2`](#tf2) associé.

## Arbre de transformation des frames
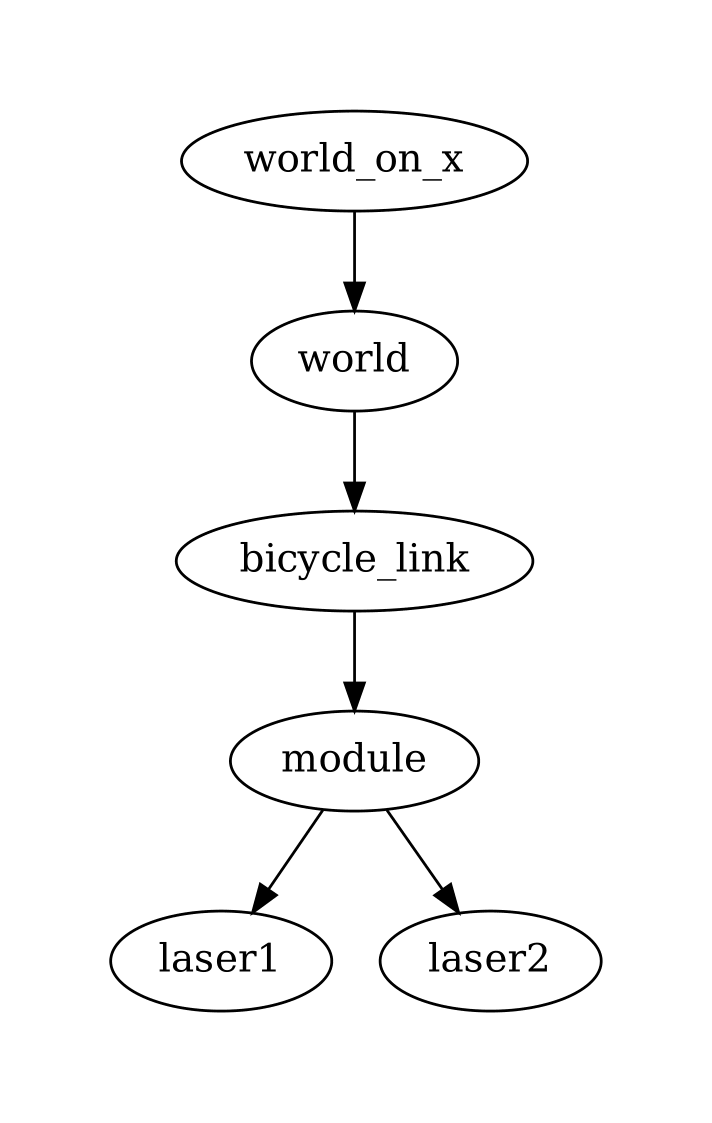
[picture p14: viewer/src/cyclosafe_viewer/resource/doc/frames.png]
tf2-tree-graph
 

La frame racine du modèle URDF est le `bicycle_link`.

Toutes les transformations vers les frames enfants à partir de `bicycle_link` sont gérées par `robot_state_publisher`.

Les transformations de `bicycle_link` vers `world` et `world_link` sont gérées par un `static_transform_publisher`.

Les dernières frames enfants (**ex**: `lidar1_tof/range` ou `laser1`) sont les frames dans lesquelles les données sont publiées par les noeuds-capteurs.

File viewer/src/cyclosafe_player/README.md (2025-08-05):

# cyclosafe_player

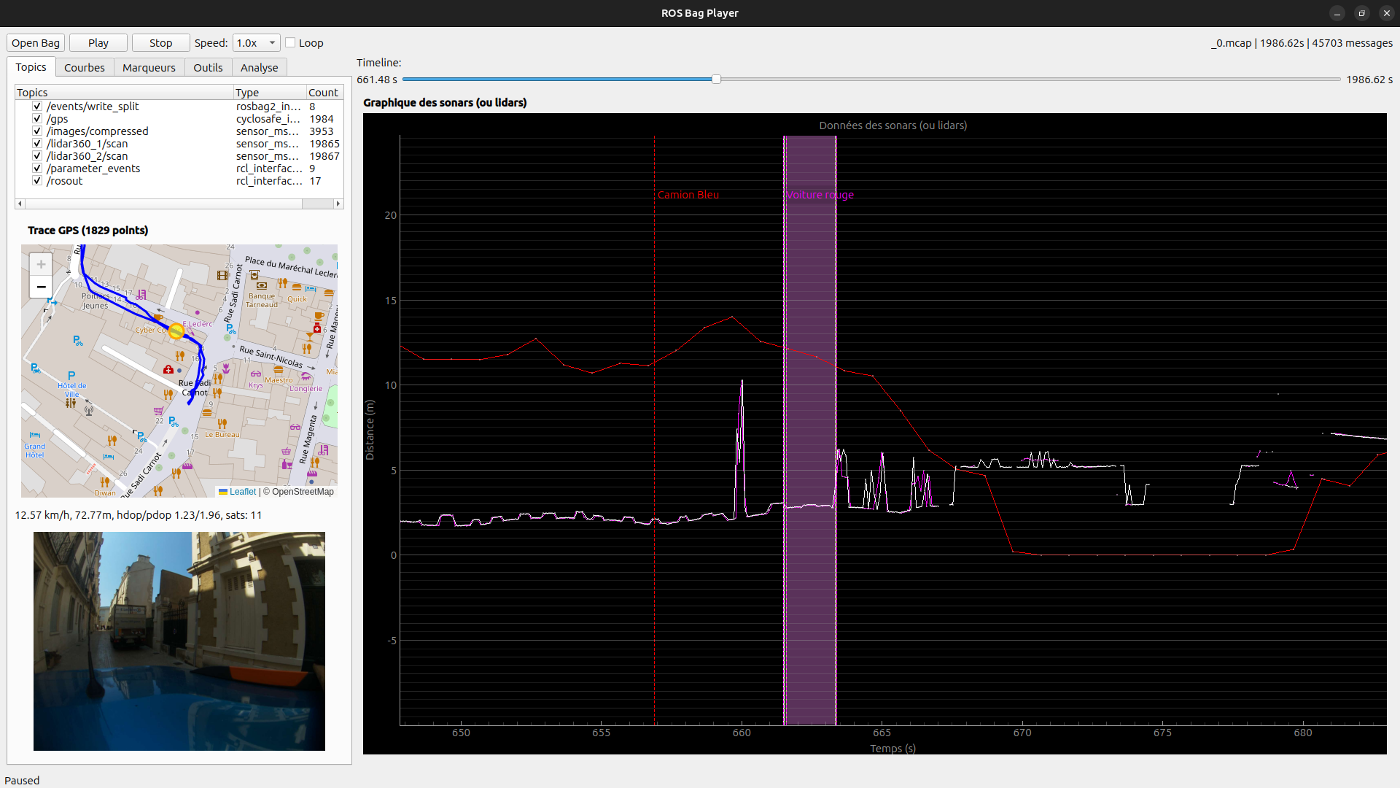
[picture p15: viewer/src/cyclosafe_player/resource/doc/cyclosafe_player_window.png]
player window demo


- [cyclosafe\_player](#cyclosafe_player)
	- [Fonctionnalités](#fonctionnalités)
- [Usage](#usage)
	- [Raccourcis claviers](#raccourcis-claviers)
- [Fonctionnement](#fonctionnement)
	- [Remarques](#remarques)
	- [Ouverture des rosbag](#ouverture-des-rosbag)
	- [Lecture et publication des données](#lecture-et-publication-des-données)
	- [Courbes](#courbes)
	- [Courbes pour les LiDARS](#courbes-pour-les-lidars)
	- [Marqueurs](#marqueurs)
		- [Dépassement et croisement](#dépassement-et-croisement)
		- [Pics de détection](#pics-de-détection)
	- [Détection des pics](#détection-des-pics)
		- [Visualisation des pics](#visualisation-des-pics)
	- [Import/export en CSV](#importexport-en-csv)
		- [Import depuis un CSV](#import-depuis-un-csv)
		- [Export vers un CSV](#export-vers-un-csv)
		- [Format](#format)
	- [Onglet analyses](#onglet-analyses)
	- [Pourquoi ne pas avoir utilisé `ros2 bag play` ou `rqt_bag` ?](#pourquoi-ne-pas-avoir-utilisé-ros2-bag-play-ou-rqt_bag-)
		- [`ros2 bag play`](#ros2-bag-play)
		- [`rqt_bag`](#rqt_bag)

## Fonctionnalités

Ce package python implémente une interface basée sur `Qt` permettant :
- d'ouvrir et de lire des [`rosbag`](../../ROS2.md#bag-ou-rosbag) avec `rosbag2_py`
- de contrôler la vitesse de lecture des données et d'avancer ou reculer dans le temps
- de visualiser les messages `sensor_msgs/msg/range` sur un graphique avec `pyqtgraph`
- de visualiser la moyenne des points d'un `sensor_msgs/msg/LaserScan` détectés dans un cône paramètrable
- fournit un outil pour annoter des **dépassements/croisements** (ou tout autre type d'évènement) dans les enregistrements via un système de **marqueurs** par **catégorie**.
  
  Ces marqueurs sont exportables/importables au format **json**.
- fournit un algorithme (très rudimentaire) de détection des "pics" sensés correspondre aux dépassements par un véhicule.
  
  Ces pics sont mis en évidence au fur et à mesure de la lecture.
- permet l'export ou l'import des données de type `sensor_msgs/msg/range` en **CSV** avec un format personnalisable.
- affiche en direct les images publiées sur `std_msgs/msg/CompressedImage`

# Usage

~~~
ros2 run cyclosafe_player player ~/data/import/20250522-091523/out/_0.mcap
~~~

> **Remarque** : Contrairement aux noeuds ROS classiques, `player` ne prend pas l'argument **ros-args** mais seulement un seul et unique argument `bag`.
>
> Ce bag peut-être compressé au format **.zstd**, auquel cas il sera décompressé de façon transparente à son ouverture.

## Raccourcis claviers

- → Avancer d'1s
- ← Reculer d'1s
- ↑ Augmenter la vitesse de lecture
- ↓ Diminuer la vitessee de lecture
- Espace : pause/reprendre

# Fonctionnement

## Remarques

Cet outil a été l'objet d'une multitude de modifications à mesure que les besoins ont évolué.

Il est très utile à l'analyse mais son architecture n'a pas été bien pensée dès le début, les outils étant trop imbriqués les uns dans les autres.

Ce document a pour but de présenter les différentes fonctionnalités et fera peu état des choix d'implémentations.

Ayant été développée au moment de nombreux tests basés sur les sonars, la section du code concernant l'analyse des pics mentionne **"sonar"** plutôt que **"range_sensor"**. Dans les faits les analyses effectuées s'appliquent également aux lidars, ou à tout noeud-capteur  publiant des messages de type `sensor_msgs/msg/Range`.

## Ouverture des rosbag

Le bag à ouvrir doit être au format **.mcap**.

S'il est compressé, il sera décompressé à l'ouverture de façon transparente dans le dossier `/tmp`.

A son ouverture, l'ensemble des topics qu'il contient sont récupérés et affichés dans l'onglet `Topics`.

Chaque topic coché sera republié en temps réel sur un topic du même nom.

A l'ouverture, si le bag contient des topics `sensor_msgs/msg/Range`, l'ensemble de ces messages vont être lus afin d'identifier les pics.

Les pics sont enregistrés dans des marqueurs d'une catégorie dédiée `/sensor/topic_name_peaks`.

L'algorithme peut-être relancé avec des paramètres personnalisés dans l'onglet `Outils`.

## Lecture et publication des données

Lorsque la lecture est activée, un nouveau temps virtuel (fonction de la vitesse de lecture) est calculé à un interval de 50ms. Tous les messages se trouvant sur le bag entre le dernier temps et le nouveau temps sont désérialisés et publiés.

La barre de temps peut-être ajustée manuellement avec la souris, ou les raccourcis claviers peuvet être utilisés pour se déplacer.

> Le délai de 50ms (ajustable) peut paraître élevé mais n'est pas réellement perceptible sur Rviz.
> 
> Pour la visualisation sur le graphique, les points sont placés en utilisant leur timestamp réel, donc il n'y a de perte de résolution.
> 
> En revanche, si par la suite des analyses sont faites à partir des messages publiés par `cyclosafe_player` et non lus directement dans le bag, ce délai devra être ajusté pour rendre compte d'une meilleure résolution temporelle. Cependant il est nettement préférable de lire les données directement dans le bag.

## Courbes

Via l'onglet `Courbes` peuvent afficher/masquer les courbes des distances publiées par les sonars et/ou les lidars.

Ces courbes peuvent être interrompues si le capteurs envoie des `NaN`, correspondant à une absence de mesure ou à une mesure incertaine.

Le facteur d'échelle de l'axe X et Y peut-être modifié en maintenant le clic droit de la souris enfoncé.

## Courbes pour les LiDARS

Etant donné que le prototype final n'inclue pas de sonars mais 2 lidars à 360° publiant des `sensor_msgs/msg/LaserScan`, il a été ajouté une fonction `emulateRange()` (dans [GraphWiget.py](./cyclosafe_player/src/GraphWidget.py)) permettant d'isoler certains points du LaserScan et de calculer pour ces points une distance moyenne permettant "d'émuler" le comportement d'un sonar orienté dans une certaine direction. 

Cela permet de mettre à profit les différents outils de `cyclosafe_player` sur les données envoyées par les lidars.

La plage de points à utiliser pour cette moyenne est définissable par topic au début du fichier [GraphWiget.py](./cyclosafe_player/src/GraphWidget.py):
~~~
# Update these values to configure which lidar points (all point between min and max radian) are
# averaged to simulate a Range sensor.
laser_scan_angles = {
	"/lidar360_1/scan" : {'min': -1.6, 'max': -1.55},
	"/lidar360_2/scan" : {'min': 1.55, 'max': 1.60},
}
~~~

## Marqueurs

Les marqueurs permettent d'annoter la timeline pour mettre en évidence des évènements particuliers.

Les marqueurs appartiennent à une **catégorie** à laquelle est associée une couleur.

A chaque marqueur est associé au moins :
- un timestamp unique : moment de l'évènement
- une description

Deux marqueurs d'une même catégorie ne peuvent avoir un timestamp strictement identique.

Les marqueurs sont exportables (et importables) au format **json**. A l'ouverture d'un bag, si le dossier contenant le bag (généralement `out/`) contient également un fichier `marker_export.json`, celui-ci sera automatiquement chargé. Il est donc conseillé d'enregistrer l'export dans le même dossier que le bag.

Il existe 3 catégories de marqueurs spéciales ayant des propriétés en plus :

### Dépassement et croisement

Catégories de marqueurs existantes par défaut et ayant des propriétés supplémentaires :
- distance de dépassement
- couleur du véhicule
- type de véhicule (voiture, camion, moto, vélo, ...)
- forme du nuage de points sur rviz (choix multiple qualitatif)

Ces marqueurs peuvent-être utilisés en compléments de l'outil d'[**import/export CSV**](#importexport-en-csv), afin d'identifier et quantifier pour chaque croisement/dépassement la présence (ou l'absence) de pics de détection sur les différents capteurs.

### Pics de détection

Produits par l'[**algorithme de détection des pics**](#détection-des-pics). Permettents de mettre en évidence et de repérer les différents pics.

Contient des propriétés supplémentaires sur la nature du pic :
- sa durée
- sa distance moyenne
- l'écart-type de la distance
- la distance min
- la distance max
- le nombre d'échantillons (de points/mesures) qu'il contient

## Détection des pics

Algorithme très rudimentaire permettant de détecter les moments où les distances publiées sur un topic de type `sensor_msgs/msg/Range` passent en dessous d'un certain seuil.

L'algorithme prend les paramètres suivants :

> `treshold_drop` : float
> - **Défaut** : 3.0
> - **Unit** : m
> - seuil en dessous duquel une distance est considérée comme un pic valide

> `min_duration_sec` : float
> - **Défaut** : 0.3
> - **Unit** : s
> - durée minimal d'un pic pour qu'il soit valide (c'est à dire la durée pendant laquelle `distance < treshold_drop`)

> `recovery_tolerance` : float
> - **Défaut** : 0.3
> - **Unit** : s
> - durée pendant laquelle la distance peut brièvement repasser au dessus de la valeur seuil pendant un pic, sans que celui-ci soit considéré comme interrompu. Destiné à limiter l'influence du bruit sur un pic.

L'algorithme est lancé automatiquement avec les paramètres par défaut à l'ouverture d'un bag.

Il peut être relancé avec des paramètres personnalisés dans l'onglet `Outils`.

Des marqueurs sont créés pour chaque pic détecté dans une catégorie dédiée.

### Visualisation des pics

Par défaut, les pics sont automatiquement mis en évidence au fur et à mesure de la lecture, afin de tout de suite identifier les vrais positifs lors d'un dépassement. 

Cette option est désactivable par topic dans l'onglet `Analyses`.

## Import/export en CSV

Outil permettant l'export ou l'import des données au format CSV, et la mise en corrélation des croisements/dépassements avec les pics détectés.

### Import depuis un CSV

Dans le cadre d'un import, le but est surtout de générer automatiquement les marqueurs dépassements/croisements à partir de timestamp et des informations liées au véhicule dans un CSV.

### Export vers un CSV

Chaque croisement et dépassement est considéré comme un évènement d'intérêt et exporter sous forme ligne.

Pour chaque croisement/dépassement (pour chaque ligne) sont identifiées et ajoutées des informations sur la présence/absence de pics pour chacun des topics `sensor_msgs/msg/Range`.

Les données à exporter et leur format sont personnalisables.

> **Remarque** : En l'état le nom des catégories de marqueurs à exporter est figé à `sonarN_peaks`. Pour l'utiliser avec des lidars il faudrait revoir la façon dont ces catégories sont créées.

### Format

Le champ format définit la structure et les champs du CSV à importer ou exporter.

<ins>**Exemple**</ins> :

`0$bag=bag,
1$time=temps,
3$vehicle=type de véhicule,
4$color=couleur,
5$type=direction,
7$shape=forme,
8$distance=distance,
28$sonar1.mean=sonar1 mean distance,
29$sonar1.std_dev=sonar1 std dev,
30$sonar1.min=sonar1 min,
31$sonar1.sample_count=sonar1 sample count,
32$sonar1.duration=sonar1 duration,
33$sonar1.delta=sonar1 delta`
- `0` : facultatif, précise l'indice de la colonne correspondante. Peut-être omis, auquel cas l'index est défini au précédent index + 1.
- `$bag` : donnée à laquelle correspond la colonne. Les types valides sont :
  - `$bag` : nom du bag
  - `$time` : timestamp de l'évènement (relatif au début de l'enregistrement)
  - `$vehicle` : type de de véhicule (voiture, moto, bus, etc...)
  - `$color` : couleur du véhicule
  - `$type` : direction de l'évènement ("Dépassement" ou "Croisement")
  - `$shape` : forme du nuages de points sur le lidar 360°
  - `$distance` : distance de dépassement
  - `$[sensor_name].mean` : si présence d'un pic, distance moyenne du pic
  - `$[sensor_name].std_dev` : si présence d'un pic, écart-type du pic
  - `$[sensor_name].min` : si présence d'un pic, distance minimale du pic
  - `$[sensor_name].max` : si présence d'un pic, distance maximale du pic
  - `$[sensor_name].duration` : si présence d'un pic, durée du pic
  - `$[sensor_name].sample_count` : si présence d'un pic, nombre d'échantillons (de mesures) que contient le pic.
  - `$[sensor_name].delta` : si présence d'un pic, différence entre la distance de l'évènement avec la distance moyenne mesurée par le pic.
- `=bag` : facultatif, entête de la colonne dans le fichier de sortie. Si omise, sera égale au nom de la donnée correspondante.
- `,` : séparateur entre deux colonnes
- Le format est insensible aux sauts de ligne et aux espaces.

Deux champs (colonnes) sont séparés par une virgule (`,`).

## Onglet analyses

Permet d'activer/désactiver la mise en évidence des pics pour chacun des topics `sensor_msgs/msg/Range`.

Affiche également des détails sur les pics présents à l'instant T de la lecture.

## Pourquoi ne pas avoir utilisé `ros2 bag play` ou `rqt_bag` ?

**ROS2** fournit déjà deux outils permettant de lire des rosbag :

### `ros2 bag play`

Il s'agit d'un outil sur terminal permettant de lire des rosbag tout en contrôlant la vitesse de lecture.

Etant sur terminal, il est peu interactif.

Par ailleurs il ne permet pas de revenir en ou de naviguer d'un moment à l'autre dans le bag.

### `rqt_bag`

Interface graphique permettant de lire des **rosbag** et de visualiser les images le long d'une timeline.

Malheureusement le package ne semble pas avoir été mis à jour pour fonctionner correctement avec `Jazzy` et génère de nombreusees erreurs liées à des `QoS` (Quality of Service) incompatibles.

Egalement il ne gère pas bien l'affichage des images compressées.

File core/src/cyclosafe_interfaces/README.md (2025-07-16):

# cyclosafe_interfaces

Définit les interfaces ROS 2 propres au projet Cyclosafe, à savoir :
- ***cyclosafe_interfaces/msg/NavSatinfo***
- ***cyclosafe_interfaces/srv/SaveImages***

# msg/NavSatInfo

Reprend le contenu de `sensor_msgs/msg/NavSatFix` en y intégrant des données supplémentaires comme l'altitude, la vitesse, le nombre de satellites utilisées et la dop (hdop et vdop).

~~~
$ ros2 interface show cyclosafe_interfaces/msg/NavSatInfo
~~~
<ins>**Résultat</ins>** :
~~~
# Navigation Satellite fix for any Global Navigation Satellite System
#
# Specified using the WGS 84 reference ellipsoid

# header.stamp specifies the ROS time for this measurement (the
#        corresponding satellite time may be reported using the
#        sensor_msgs/TimeReference message).
#
# header.frame_id is the frame of reference reported by the satellite
#        receiver, usually the location of the antenna.  This is a
#        Euclidean frame relative to the vehicle, not a reference
#        ellipsoid.
std_msgs/Header header
	builtin_interfaces/Time stamp
		int32 sec
		uint32 nanosec
	string frame_id

# Satellite fix status information.
sensor_msgs/NavSatStatus status
	#
	int8 STATUS_UNKNOWN = -2        #
	int8 STATUS_NO_FIX =  -1        #
	int8 STATUS_FIX =      0        #
	int8 STATUS_SBAS_FIX = 1        #
	int8 STATUS_GBAS_FIX = 2        #
	int8 status -2 #
	uint16 SERVICE_UNKNOWN = 0  #
	uint16 SERVICE_GPS =     1
	uint16 SERVICE_GLONASS = 2
	uint16 SERVICE_COMPASS = 4      #
	uint16 SERVICE_GALILEO = 8
	uint16 service

# Latitude [decimal degrees]. Positive is north of equator; negative is south.
float64 latitude

# Longitude [decimal degrees]. Positive is east of prime meridian; negative is west.
float64 longitude

# Altitude [m]. Positive is above the WGS 84 ellipsoid
# (quiet NaN if no altitude is available).
float64 altitude

# Horizontal dilution of precision
float32 hdop

# Position dilution of precision
float32 pdop

# Ground speed in kphrs
float32 ground_speed

# Number of active satellites
int32 actives_sat
~~~

# srv/SaveImages

Service permettant l'interaction entre un précédent noeud hub (devenu obsolete avec l'utilisation de ROS bag) et le [**noeud caméra**](../cyclosafe/README.md#acamera). Demande au noeud caméra d'enregistrer les images prises sur les X dernières millisecondes (`time`) au `path` .demandé

 ~~~
 $ ros2 interface show cyclosafe_interfaces/srv/SaveImages
 ~~~~

<ins>**Résultat</ins>** :

 ~~~
 uint32 time # milliseconds
string path # folder where to save images
---

uint8 SUCCESS = 0 # time constraint were respected
uint8 PARTIAL_SUCCESS = 1 # time constraint partially respected (some images were missing)
uint8 FAILURE = 2 # an error occured or invalid argument

uint8 result
~~~

Voir le [**noeud caméra**](../cyclosafe/README.md#acamera) pour un exemple d'utilisation.

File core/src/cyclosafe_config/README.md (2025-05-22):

# cyclosafe_config

Package python dont la seule fonction est d'exporter les classes `Sensor` et `SensorTypeEnum`, utiles à l'intégration d'un node dans une launch description, en permettant d'uniformiser la déclaration des paramètres à travers plusieurs launch description.

Ces classes sont également utilisées par l'environnement [**viewer/**](../../../viewer/README.md), raison pour laquelle elles sont isolées dans un package.

## Classe Sensor

Classe helper qui a pour but d'uniformiser la déclaration d'un capteur (et de ses différentes propriétés) à travers différentes launch descriptions (principalement celle du package cyclosafe et celle du viewer).

Essentiellement elle permet de wrapper l'instanciation d'un **Node()** dans les launch description en automatisant la résolution des ports et des couleurs associées aux capteurs pour leur future visualisation dans Rviz.

Cette classe étant aussi utilisée par [**viewer/**](../../../viewer/README.md), elle permet de faire correspondre à une certaine config d'enregistrement la visualisation qui lui est associée.

Voir [**config.py**](../cyclosafe/launch/config.py) pour un exemple d'utilisation.

Les paramètres sont donnés sous forme de *kwargs* lors de l'instanciation.

## Paramètres

> **package** : string
> - nom du package auquel appartient le noeud
> - **requis**

> **executable** : string
> - nom de l'executablee du noeud
> - **requis**

> **namespace** : string
> - namespace utilisé par le noeud
> - **requis**, peut être vide

> **port** : string
> - nom du package auquel appartient le noeud
> - **requis**, peut être **None** ou vide
> - Si **None**: **port_hint** sera utilisé pour essayer de résoudre le port définitif

> **type** : SensorTypeEnum
> - type de capteur
> - **requis**
> - Valeurs possibles : 
> 	- SensorTypeEnum.RangeSensor (=0)
> 	- SensorTypeEnum.Lidar360Sensor (=1)
> 	- SensorTypeEnum.GPSSensor (=2)
> 	- SensorTypeEnum.CameraSensor (=3)

> **enable** : bool
> - défaut: **True**
> - permet de prendre en compte ou non le capteur dans la config

> **parameters** : [dict[str, Any]]
> - défaut: **""**
> - contient une list d'un seul dictionnaire de paramètres qui seront transmis à ROS.
> - si le **port** est dynamiquement résolu grâce à **port_hint**, les paramètres ayant pour nom **port**, **serial_port** ou **port_name** seront mis à jour.
> - défaut: **[]**

> **description** : str
> - purement indicatif

> **transform** : [str]
> - défaut: **None**
> - lorsque défini, correspond à la liste des arguments qui seront transmis à l'execution d'un **static_transform** lors de la visualisation
> **Obsolete** : préférer l'utilisation d'un modèle URDF pour la visualisation.
> - <ins>**Exemple**</ins> :
> 	- ["--x", "5.0", "--y", "0.0", "--z", "0.0", "--roll", "-1.57", "--pitch", "1.57", "--yaw", "0", "--frame-id", "world", "--child-frame-id", "my_sensor_frame"],
> 	- Transpose la frame (*référentiel*) du capteur dans la frame world

> **description** : str
> - défaut: **""**
> - purement indicatif

> **topic** : str
> - défaut: **"range"**
> - topic sur lequel seront publiés les données
> - surtout utilisé par les outils de visualisation afin d'identifier les capteurs dans les rosbag

> **color** : str | std_msgs.msg.ColorRGBA
> - défaut : **None**
> - si **"auto"**, la couleur est automatiquement attribuée en fonction de l'ordre de déclaration du capteur
> - accepte les objets ColorRGBA ou des valeurs littérales comme **red, green, magenta, ...**
> - sera utilisé pour colorier certaines données dans les outils de visualisation.

> **port_hint** : str
> - défaut: **None**
> - A utiliser en conjonction avec **port = None**
> - Contient une partie de l'id vendeur d'une interface sériale (trouvable dans */dev/serial/by-id/...*) à partir duquel le port final va tenter d'être résolu.
> - <ins>**Exemple**</ins> :
> 	- le pattern **"if00-port0"** peut renvoyer **/dev/serial/by-id/e40dc7ec375aee118e528bdc8ffcc75d-if00-port0**
> 	- il s'agit symlink qui point vers **../../ttyUSB1**
> 	- le port définitif sera donc : **/dev/serial/by-id/../../ttyUSB1**

> **delay** : float
> - défaut: **None**
> - **unité** : secondes
> - indique un délai au lancement du noeud
> - peut-être utiliser pour inciter les noeuds à se lancer dans un certain ordre
> - **Attention** : il n'y aucune garantie que cet ordre sera respecté

> **log_level** : str
> - défaut: **"info""**
> - permet d'indiquer pour un noeud un niveau de log potentiellement différent du reste de la config 
> - prend la priorité sur l'argument **log_level** de la launch description

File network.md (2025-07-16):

# Configuration réseau pour ssh et ip-forwarding

Afin de faciliter les opérations, que ce soit pour exporter les données ou modifier l'environnement sur le raspberry, il est fortement recommandé d'accéder au raspberry via ssh.

Ce document donne des instructions sur :
- les commandes et outils permettant d'interagir avec le raspberry en ssh (une fois les configurations effectuées)
- les paramètres réseaux à configurer sur le raspberry et sur l'hôte pour permettre une connection ssh
- les paramètres réseaux à configurer sur l'hôte pour activer l'ip-forwarding sur l'hôte et permettre au raspberry d'utiliser l'accès internet de celui-ci.

## Scripts de configuration automatique

### Sur le raspberry :

~~~
~/cyclosafe/core/setup/ip_config.sh
~~~

### Sur l'hôte

[Voir les instructions dédiées à l'hôte](#mise-en-place-sur-lhôte)

## Sommaire
- [Configuration réseau pour ssh et ip-forwarding](#configuration-réseau-pour-ssh-et-ip-forwarding)
  - [Scripts de configuration automatique](#scripts-de-configuration-automatique)
    - [Sur le raspberry :](#sur-le-raspberry-)
    - [Sur l'hôte](#sur-lhôte)
  - [Sommaire](#sommaire)
  - [Structure réseau](#structure-réseau)
  - [Utilisation](#utilisation)
    - [Se connecter en ssh](#se-connecter-en-ssh)
    - [Copier des fichiers depuis l'hôte vers le raspberry](#copier-des-fichiers-depuis-lhôte-vers-le-raspberry)
    - [Copier des fichiers depuis le raspberry vers l'hôte](#copier-des-fichiers-depuis-le-raspberry-vers-lhôte)
    - [Outils utiles](#outils-utiles)
  - [Mise en place sur le raspberry](#mise-en-place-sur-le-raspberry)
    - [Configurer le profil sur le raspberry](#configurer-le-profil-sur-le-raspberry)
    - [Activer le serveur ssh](#activer-le-serveur-ssh)
  - [Mise en place sur l'hôte](#mise-en-place-sur-lhôte)
    - [Profil réseau](#profil-réseau)
    - [ip-forwarding (sur l'hôte)](#ip-forwarding-sur-lhôte)
      - [Pour activer l'ip forwarding](#pour-activer-lip-forwarding)
      - [L'accès internet de l'hôte et la connexion au raspberry sont sur le même interface.](#laccès-internet-de-lhôte-et-la-connexion-au-raspberry-sont-sur-le-même-interface)
      - [L'accès internet de l'hôte est obtenu via une autre interface (**ex**: wifi) que celle sur laquelle est connectée le raspberry.](#laccès-internet-de-lhôte-est-obtenu-via-une-autre-interface-ex-wifi-que-celle-sur-laquelle-est-connectée-le-raspberry)
    - [Activer le serveur ssh sur l'hôte](#activer-le-serveur-ssh-sur-lhôte)

## Structure réseau

Le sous-réseau qui va être configuré a pour addresse `192.168.2.1/24`, c'est à dire est l'ensemble des adresses commencant par `192.168.2.XXX`.

L'adresse du sous-réseau est un choix arbitraire, destiné à éviter les conflits avec les adresses du réseau local, qui sont traditionnellement `192.168.1.1/24`.

Dans ce sous-réseau, il y a deux appareils :
- l'hôte qui a pour adresse `192.168.2.1` et qui fait office de routeur vers internet (puisqu'il a la première addresse du sous-réseau)
- le raspberry qui a pour addresse `192.168.2.2`

## Utilisation

Suppose que la configuration réseau est déjà active **[sur le raspberry](#mise-en-place-sur-le-raspberry) ET [sur l'hôte](#mise-en-place-sur-lhôte)**.

### Se connecter en ssh

~~~
ssh user@192.168.2.2
~~~

`user` est le nom d'utilisateur choisi lors de l'installation du raspberry.

### Copier des fichiers depuis l'hôte vers le raspberry

~~~
scp file_to_copy cycliste@192.168.2.2:/home/cycliste/out_path_on_raspberry

# Pour copier un dossier
scp -r folder_to_copy/ cycliste@192.168.2.2:/home/cycliste/out_path_on_raspberry
~~~

### Copier des fichiers depuis le raspberry vers l'hôte

~~~
scp cycliste@192.168.2.2:/home/cycliste/file_to_copy out_path_on_host

# Pour copier un dossier
scp -r cycliste@192.168.2.2:/home/cycliste/folder_to_copy out_path_on_host
~~~

### Outils utiles

<ins>**Extension VSCode Remote-SSH**</ins> :

L'extension Remote-SSH sur VS-Code permet d'ouvrir un répertoire et éditer sur l'hôte un dossier situé sur le guest. Très utile pour effectuer et tester des modifications en direct sur le raspberry sans avoir à `git commit` tous les changements.

<ins>**nmap**</ins> :

En cas de doute sur l'ip du raspberry ou de conflit avec d'autre addresses, le réseau local peut-être scanné avec la commande `nmap` pour déterminer l'adresse des appareils s'y trouvant.

Exemple :

~~~
sudo nmap -sn 192.168.2.1/24
~~~

Détecte toutes les adresses commencant par `192.168.2.XXX` sur le réseau.

## Mise en place sur le raspberry

### Configurer le profil sur le raspberry

1. Mettre en place le profil réseau
   ~~~
   sudo nmcli connection add Internet-DHCP ifname eth0 ipv4.method manual ipv4.addresses 192.168.2.2/24 ipv4.gateway 192.168.2.1 ipv4.dns "8.8.8.8,8.8.4.4"
   ~~~
2. Activer le profil réseau
   ~~~
   sudo nmcli con up Internet-DHCP
   ~~~

### Activer le serveur ssh

1. Vérifier dans raspi-config que le ssh est activé :
   1. Executer la commande `sudo raspi-config`
   2. Interface Options->SSH Enable/disable ....
   3. Fermer raspi-config
2. Activer le serveur ssh dans les services systemd
   1. Executer la commande `sudo systemctl enable ssh` : le serveur sera désormais lancé au démarrage du raspberry
   2. Démarrer le serveur ssh (sans avoir à redémarrer) : `sudo systemctl start ssh`
   3. Vérifier le statut du service : `sudo systemctl status ssh`

## Mise en place sur l'hôte

### Profil réseau

1. Identifier le nom de l'interface ethernet à laquelle sera branché le raspberry.
   ~~~
   ifconfig
   ~~~
   L'interface en question ressemble généralement à `eth0`, `eno1`, `enp0s3` ou similaire.

   <ins>**Note**</ins> : Si le port ethernet de l'hôte est déjà utilisé pour l'accès internet, vous pouvez connecter le raspberry au switch par lequel celui-ci est connecté au réseau internet. L'interface à identifier reste la même.
2. Mettre en place le profil réseau en substituant par le nom de l'interface identifiée
   ~~~
   sudo nmcli connection add "Static-raspi" ifname INTERFACE_NAME ipv4.method manual ipv4.addresses 192.168.2.1/24
   ~~~
3. Activer le profil réseau
   ~~~
   sudo nmcli con up Static-raspi
   ~~~

A partir de là, il est possible de brancher le raspberry en ethernet et de s'y connecter en ssh.

### ip-forwarding (sur l'hôte)

L'ip-forwarding permet à l'hôte de comporter comme un routeur et de faire les requêtes du raspberry vers internet en son nom.

Le prérequis est que le raspberry ait comme gateway ipv4 l'adresse de l'hôte (ce qui est normalement le cas si la procédure de configuration a été suivie).

#### Pour activer l'ip forwarding
   ~~~
   sudo sysctl -w net.ipv4.ip_forward=1
   ~~~
   Pour rendre le changement permanent :
   ~~~
   sudo nano /etc/sysctl.conf
   ~~~
   Et ajouter cette ligne :
   ~~~
   net.ipv4.ip_forward=1
   ~~~

<ins>**A partir de là, deux scénarios possibles</ins> :**

#### L'accès internet de l'hôte et la connexion au raspberry sont sur le même interface.

<ins>**Ex</ins>** : internet est obtenu sur l'hôte via internet et le raspberry est connecté sur le même réseau local via un switch.

Le raspberry devrait avoir accès à internet.

#### L'accès internet de l'hôte est obtenu via une autre interface (**ex**: wifi) que celle sur laquelle est connectée le raspberry.

Dans ce cas il est nécessaire de configurer les ip-tables afin de rediriger le traffic entre les deux interfaces.
1. Identifier le nom de l'interface wifi sur laquelle est obtenue internet.
   ~~~
   ifconfig
   ~~~
   L'interface en question ressemble généralement à `wlan0`, `wlp2s0` ou similaire.
   
   Une fois l'interface identifiée, vous pouvez enregistrer le nom des différentes interfaces dans des variables.
   ~~~
   ETHERNET_INTERFACE=enx34298f731b2e
   WIFI_INTERFACE=wlp2s0
   ~~~
2. Configurer le NAT et l'ip-forwarding avec iptables :
   ~~~
   sudo iptables -t nat -A POSTROUTING -o $WIFI_INTERFACE -j MASQUERADE
   sudo iptables -A FORWARD -i $ETHERNET_INTERFACE -o $WIFI_INTERFACE -j ACCEPT
   sudo iptables -A FORWARD -i $WIFI_INTERFACE -o $ETHERNET_INTERFACE -m state --state RELATED,ESTABLISHED -j ACCEPT
   ~~~
3. Pour rendre ces changements persistents, vous pouvez installer `iptables-persistent`.
   ~~~
   sudo apt install iptables-persistent
   ~~~
   Cela suppose un accès internet, mais à ce stade vous devriez y avoir accès.

   Pendant l'installation, il vous sera demandé si vous sera proposé d'enregistrer les règles actuelles.

   Les règles seront enregistrées dans `/etc/iptables/rules.v4`
   > Pour restaurer les règles, vous pouvez executer les commandes suivantes :
   > ~~~
   > # Supprimer les règles de NAT
   >sudo iptables -t nat -D POSTROUTING -o wlp2s0 -j MASQUERADE
   >
   ># Supprimer les règles de forwarding
   >sudo iptables -D FORWARD -i enx34298f731b2e -o wlp2s0 -j ACCEPT
   >sudo iptables -D FORWARD -i wlp2s0 -o enx34298f731b2e -m state --state RELATED ESTABLISHED -j ACCEPT
   > 
   > # Sauvegarder les changements
   > sudo iptables-save | sudo tee /etc/iptables/rules.v4
   > ~~~

### Activer le serveur ssh sur l'hôte

Cet étape n'est pas indispensable.

L'idée est de permettre au raspberry d'effectuer des requêtes ssh (ou scp) vers l'hôte.

Par exemple cela peut être utile pour indiquer comme remote git l'adresse du repo sur l'hôte (exemple `ssh://host-user@192.168.2.1:/home/host-user/cyclosafe_repo`).

Dans cette configuration là, l'hôte n'a qu'à ```git commit``` les changements et ils peuvent récupéré sur le raspberry via ```git pull```.

1. Installer le serveur ssh :
   1. Executer la commande `sudo apt install openssh-server`
2. Activer le serveur ssh dans les services systemd
   1. Executer la commande `sudo systemctl enable ssh` : le serveur sera désormais lancé au démarrage du raspberry
   2. Démarrer le serveur ssh (sans avoir à redémarrer) : `sudo systemctl start ssh`
   3. Vérifier le statut du service : `sudo systemctl status ssh`

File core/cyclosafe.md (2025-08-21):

# Résumé

A chaque capteur est associé un noeud ROS qui implémente éventuellement un driver et publie les mesures sur des topics dédiés.

Chaque noeud peut-être lancé indépendemment ou l'ensemble des noeuds sont lancés ensembles via la launch description [**cyclosafe.launch.py**](src/cyclosafe/README.md#launch-description)

- [Résumé](#résumé)
- [Schémas](#schémas)
	- [Schéma simplifié](#schéma-simplifié)
	- [Modèle UML complet](#modèle-uml-complet)
- [Structure](#structure)
	- [cyclosafe](#cyclosafe)
	- [cyclosafe\_config](#cyclosafe_config)
	- [cyclosafe\_interfaces](#cyclosafe_interfaces)
	- [cyclosafe\_lidar](#cyclosafe_lidar)
	- [rplidar\_ros2](#rplidar_ros2)

# Schémas

## Schéma simplifié

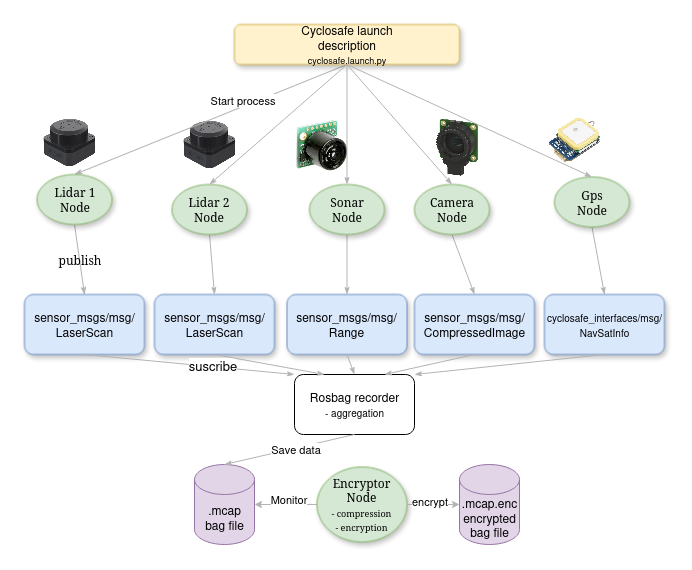
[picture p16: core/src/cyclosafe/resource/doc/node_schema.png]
simple-node-diagram


## Modèle UML complet

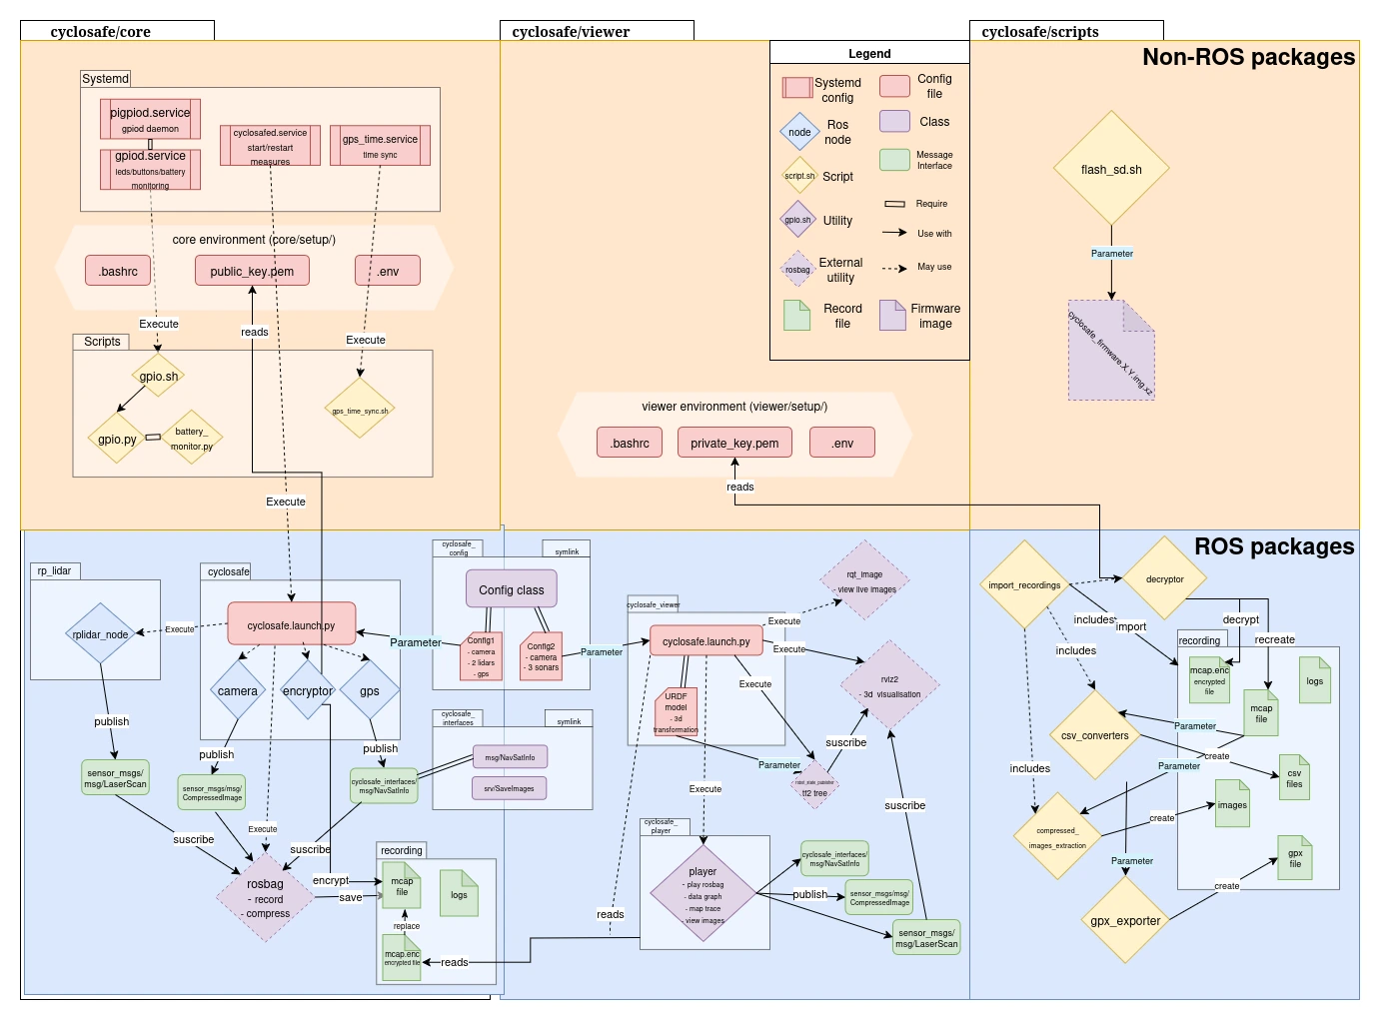
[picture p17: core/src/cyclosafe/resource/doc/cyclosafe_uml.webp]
uml diagram of cyclosafe project


# Structure

## cyclosafe

[**src/cyclosafe/README.md**](src/cyclosafe/README.md)

Noeud central du projet.

Contient :
- l'ensemble des noeuds de capteur écrits en python, à savoir :
	- [**noeud gps**](src/cyclosafe/README.md#gpspy) publiant des *cyclosafe_interfaces/msg/NavSatInfo*
	- [**noeud caméra**](src/cyclosafe/README.md#camera_pipy) publiant des *sensor_msgs/msg/CompressedImage* sur le topic ***
	- [**noeud d'encryption**](src/cyclosafe/README.md#encryptorpy) : surveille les rosbag créés dans un dossier donné, les compresse et les encrypte au fur et à mesure qu'ils sont créés.
- l'implémentation de classes utilisées par des noeuds ou d'autres packages :
	- [**ASerialSensor**](src/cyclosafe/README.md#aserialsensor) : modèle de noeud générique parsant des données envoyées via serial
	- [**ACamera**](src/cyclosafe/README.md#acamera) : modèle de noeud caméra0
- la [**launch description**](src/cyclosafe/README.md#launch-description) permettant de lancer l'ensemble des noeuds ensembles.

## cyclosafe_config

[**src/cyclosafe_config/README.md**](src/cyclosafe_config/README.md)

Package python dont la seule fonction est d'exporter les classes `Sensor` et `SensorTypeEnum`, utiles à l'intégration d'un node dans une launch description, en permettant d'uniformiser la déclaration des paramètres à travers plusieurs launch description.

Ces classes sont également utilisées par l'environnement [**viewer/**](../viewer/README.md), raison pour laquelle elles sont isolées dans un package.

## cyclosafe_interfaces

Définit les interfaces ROS 2 propres au projet, à savoir :
- ***cyclosafe_interfaces/msg/NavSatinfo*** : extension de sensor_msgs/msg/NavSatFix intégrant des données supplémentaires comme l'altitude, la vitesse, le nombre de satellites utilisées et la dop.
- ***cyclosafe_interfaces/srv/SaveImages (obsolete)*** : service permettant l'interaction entre le noeud hub (supprimé) et le noeud caméra. Demande au noeud caméra d'enregistrer les images prises sur les X dernières secondes.

[**src/cyclosafe_interfaces/README.md**](src/cyclosafe_interfaces/README.md)

## cyclosafe_lidar

[**src/cyclosafe_lidar/README.md**](src/cyclosafe_lidar/README.md)

Package cpp qui permet d'intégrer les lidars de la gamme Benewake à ROS2. Implémente un driver via l'interface sériale et un noeud pour publier les données sous forme de sensor_msgs/msg/Range.

## rplidar_ros2

[**src/rplidar_ros2/README.md**](src/rplidar_ros2/README.md)

Clone de https://github.com/CreedyNZ/rplidar_ros2

Implémente le driver du lidar rplidar-c1 et l'intègre à ROS2.

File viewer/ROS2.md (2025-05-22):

# ROS2

Le projet cyclosafe repose sur **ROS2** pour la prise et l'enregistrement des mesures.

> ***ROS (Robot Operating System)*** provides libraries and tools to help software developers create robot applications.
> 
> It provides hardware abstraction, device drivers, libraries, visualizers, message-passing, package management, and more.
> 
> ROS is licensed under an open source, BSD license.

Source: https://wiki.ros.org/ 

> Pour résumer ROS2 est une surcouche logicielle permettant de formaliser les échanges entre processeurs.
> 
> Des outils et des bibliothèques sont fournis afin de faciliter le développement d'applications robotiques.

Source : https://web.enib.fr/~kerhoas/automatique-robotique/robot-mobile-rpi-ros2/presentation-ros2/

ROS est basé sur une architecture de noeuds exécutables pouvant publier et/ou souscrire à des [topics](#topic).

- [ROS2](#ros2)
- [Pourquoi utiliser ROS 2 dans ce projet ?](#pourquoi-utiliser-ros-2-dans-ce-projet-)
  - [Représentation des données](#représentation-des-données)
  - [Visualisation des données](#visualisation-des-données)
  - [Orchestration](#orchestration)
  - [Sérialisation et enregistrement des données](#sérialisation-et-enregistrement-des-données)
  - [Paramètrisation des tests](#paramètrisation-des-tests)
  - [Modularité](#modularité)
  - [Open source](#open-source)
- [Glossaire ROS2](#glossaire-ros2)
  - [Action](#action)
  - [Bag (ou rosbag)](#bag-ou-rosbag)
  - [Build](#build)
  - [Colcon - *Colcon*](#colcon---colcon)
  - [Discovery](#discovery)
  - [Frame - *Repère*](#frame---repère)
  - [Installation](#installation)
  - [Interface](#interface)
  - [Launch description - *Ou launch file*](#launch-description---ou-launch-file)
  - [Client librairie](#client-librairie)
  - [Message](#message)
  - [Node - *Noeud*](#node---noeud)
  - [Package](#package)
  - [Parameter - *Paramètres*](#parameter---paramètres)
  - [Rclcpp - *ROS Client Library C++*](#rclcpp---ros-client-library-c)
  - [Rclpy - *ROS Client Library Python*](#rclpy---ros-client-library-python)
  - [Rosdep - *ROS Dependency*](#rosdep---ros-dependency)
  - [Rviz - *ROS Visualization*](#rviz---ros-visualization)
  - [Service](#service)
  - [tf2](#tf2)
  - [Topic](#topic)
  - [URDF - *Unified Robot Description Format*](#urdf---unified-robot-description-format)
  - [Workspace - *Environnement de travail*](#workspace---environnement-de-travail)

# Pourquoi utiliser ROS 2 dans ce projet ?

## Représentation des données

Les données manipulées par le projet inclue des données numériques et spatiales de différentes nature, cela nécessite une capacité à représenter et à visualiser ces données.

**ROS2**, notamment grace aux [interfaces](#interface) définies dans `sensor_msgs` permet la représentation :
- de nuages de points via `sensor_msgs/msg/LaserScan`
- de distances via `sensor_msgs/msg/Range`
- d'images compressées via `std_msgs/msg/CompressedImage`
- de coordonnéées GPS via `sensor_msgs/msg/NavSatFix`

Ces [messages](#message) sont compatibles et s'intègrent parfaitement aux outils de visualisation comme [`Rviz`](#rviz---ros-visualization) ou `Mapviz`.

## Visualisation des données

L'usage de capteurs, et notamment de capteurs complexe (comme les les lidars 360°), impose, en dehors de l'analyse, de pouvoir visualiser correctement les données.

Il faut également pouvoir transformer les systèmes de coordonnées vers un système global, les capteurs ayant chacun leur propre référence.

- [`Rviz`](#rviz---ros-visualization), [package](#package) installé avec ROS2 est un excellent outil pour visualiser les données dans un espace 3D.
- [`tf2`](#tf2) et [`urdf`](#urdf---unified-robot-description-format) qui s'intègrent parfaitement à [Rviz](#rviz---ros-visualization), permettent de simplifier et d'automatiser toutes les transformations nécessaires.

## Orchestration

La multitude de capteur à utiliser impose de faire tourner en simultanné plusieurs programmes prenant des mesures. ROS2 permet :
   - **via les [launch description](#launch-description---ou-launch-file)** : gestion du lancement de plusieurs [noeuds](#node---noeud) simultannés avec une possibilité de définir et mutualiser des [paramètres](#parameter---paramètres)
   - via les [**topics**](#topic) et les [**services**](#service) : communication entre plusieurs [noeuds](#node---noeud), permettant une potentielle analyse en directe à partir de données mesurées par des capteurs différents

## Sérialisation et enregistrement des données

Il est nécessaire de sérialiser et d'enregistrer dans un dossier les données prises. Il est donc essentiel d'optimiser l'espace de stockage que celle-ci occuperont :

   - ROS2 fournit avec les [`rosbag`](#bag-ou-rosbag) un outil extremement pour sérialiser et compresser les données sans perte.
  
## Paramètrisation des tests

Le besoin de prototyper et tester rapidement différentes configurations et différents capteurs impose des lancements paramètriques :
   - ROS2 implémente un système de [paramètres](#parameter---paramètres) pouvant être transmis de multiples façons différentes, et notamment modifier au runtime
   - Ce système de [paramètre](#parameter---paramètres) s'intègre parfaitement avec les [**launch description**](#launch-description---ou-launch-file)
  
## Modularité

Les différents [noeud](#node---noeud) et scripts étant codés dans des langages différents (c++, python, bash) et en partie fournis par les fabricants, il est nécessaire de les assembler ensemble et de résoudre un certain nombre de dépendances.

- La structure en [package](#package) de ROS pallie très bien à cette contrainte
- [**rosdep**](#rosdep---ros-dependency) permet de résoudre les dépendances
- [**colcon**](#colcon---colcon) permet d'automatiser et de déléguer le [build](#build) et l'[installation](#installation) des différents [packages](#package)

## Open source

Les outils fournis par ROS sont en développement constant et très bien documenté.

De nombreuses APIs ([rclpy](#rclpy---ros-client-library-python), [rclcpp](#rclcpp---ros-client-library-c), rosbag2_py) sont disponibles pour créer et déployer des outils personnalisés.

[`cyclosafe_player`](src/cyclosafe_player/README.md) utilise notamment `rosbag2_py` pour manipuler la lecture de [rosbag](#bag-ou-rosbag).

Par ailleurs les fabricants de capteurs fournissent généralement des **SDK** (Software Kit Development) pour **ROS2** permettant d'intégrer leur capteur au système ROS.

# Glossaire ROS2

## Action

Non utilisé par Cyclosafe.

Système de communication synchrone entre deux noeuds apparenté au [**service**](#service), permettant une **réponse** à une **requête**, à la différence qu'il permet en plus de fournir un **feedback** en temps réel sur l'avancement de la **requête**.

## Bag (ou rosbag)
Fichier ou ensemble de fichiers contenant l'enregistrement de [**messages**](#message) publiés sur un ou plusieurs [**topics**](#topic). Un [**bag**](#bag-ou-rosbag) peut être rejoué ultérieurement de façon à simuler et à reproduire l'ensemble des [messages](#message) qui ont été publiés au moment de l'enregistrement.

## Build
Processus de compilation et de transformation du code source des [**packages**](#package) en exécutables et bibliothèques utilisables. Cette étape est réalisée par [**colcon**](#colcon---colcon) dans le répertoire `build/` du [**workspace**](#workspace---environnement-de-travail).

## Colcon - *Colcon*
Outil permettant de [build](#build) et d'[installer](#installation) un ou l'ensemble des [**packages**](#package) sur le [**workspace**](#workspace---environnement-de-travail). Il gère les dépendances entre [packages](#package) et automatise le processus de compilation.

## Discovery
Processus automatique par lequel un [noeud](#node---noeud) prend connaissance d'un autre et détermine la façon d'échanger avec lui. Ce mécanisme permet aux [noeuds](#node---noeud) de se connecter dynamiquement sans configuration manuelle préalable.

## Frame - *Repère*

Système de coordonnées 3D de référence (ou repère) dans lequel sont publiés des [messages](#message) contenant des données spatiales. Les [messages](#message) publiés par les [noeuds](#node---noeud) ont une propriété `frame` indiquant à quel [frame](#frame---repère) ils sont référencés.

**Ex**: les [messages](#message) publiés sur la [frame](#frame---repère) `lidar1_frame` contiennent des données spatiales référencées par rapport au `lidar1`.

Les [frames](#frame---repère) et les transformations de l'une à l'autre sont gérées par [`tf2`](#tf2), qui maintient un arbre de transformations entre les différents repères.

## Installation
Processus qui suit le [**build**](#build) et qui consiste à placer les exécutables, bibliothèques et les ressources partagées dans le répertoire `install/` du [**workspace**](#workspace---environnement-de-travail), les rendant ainsi utilisables par l'utilisateur.

## Interface
Métaclasse pouvant définir de nouveaux types de [messages](#message), [services](#service) et actions utilisables dans différents langages de programmation (via les librairies [rclcpp](#rclcpp---ros-client-library-c) et [rclpy](#rclpy---ros-client-library-python)).

## Launch description - *Ou launch file*

Fichier dans lequel est décrit une configuration de lancement simultanné de plusieurs [noeuds](#node---noeud) ROS (ou autres executables).

## Client librairie
Librairie spécifique à un langage de programmation permettant à un [noeud](#node---noeud) de communiquer avec un autre [noeud](#node---noeud) utilisant un autre langage de programmation. Les deux principales étant [**rclpy**](#rclpy---ros-client-library-python) (Python) et [**rclcpp**](#rclcpp---ros-client-library-c) (C++).

## Message
Type de donnée spécifique à ROS échangée entre plusieurs [noeuds](#node---noeud) via un [**topic**](#topic). Les [messages](#message) définissent la structure des données transmises et peuvent contenir des types primitifs ou des structures complexes.

## Node - *Noeud*
Entité utilisant ROS pour communiquer avec d'autres [noeuds](#node---noeud). Un [noeud](#node---noeud) est un processus qui peut publier et/ou souscrire à des [**topics**](#topic), offrir ou utiliser des [services](#service), et participer au système de communication ROS.

## Package
Module de base de ROS2. Un [package](#package) peut contenir des [noeuds](#node---noeud), des [interfaces](#interface) personnalisées, des ressources, des fichiers de configuration, des scripts, des librairires, du code source, etc...

On distingue :
- les **core [package](#package)**, qui constituent les outils du système **ROS2** (trouvables dans `/opt/ros/jazzy/` et sourcés par `/opt/ros/jazzy/setup.bash`).
  - **Ex** : [rviz](#rviz---ros-visualization), [tf2](#tf2), sensor_msgs, [rclcpp](#rclcpp---ros-client-library-c), ...
- les [**packages**](#package) **utilisateurs**, contenus dans le répertoire [`src/`](./src/) du [workspace](#workspace---environnement-de-travail) et qui correspondent aux [packages](#package) installés par l'utilisateur. 

## Parameter - *Paramètres*
Variables de configuration des [noeuds](#node---noeud) pouvant être transmis de multiples façons différentes (via terminal ou des [launch description](#launch-description---ou-launch-file)), et notamment modifiées au runtime (via des [services](#service)).

## Rclcpp - *ROS Client Library C++*
[**Librairie client**](#librairie-clien) pour le langage C++ permettant de développer des [noeuds](#node---noeud) ROS. Elle fournit les API nécessaires pour créer des [noeuds](#node---noeud), publier/souscrire à des [topics](#topic), et utiliser les [services](#service) ROS.

## Rclpy - *ROS Client Library Python*
[**Librairie client**](#librairie-clien) pour le langage Python permettant de développer des [noeuds](#node---noeud) ROS. Elle offre une [interface](#interface) Python pour toutes les fonctionnalités de base de ROS2.

## Rosdep - *ROS Dependency*
Outil permettant de résoudre et d'automatiser l'installation des dépendances des [**packages**](#package). Il analyse les fichiers de configuration des [packages](#package) et installe automatiquement les dépendances système requises.

## Rviz - *ROS Visualization*
Outil de visualisation 3D pour ROS permettant d'afficher des données de capteurs, des modèles de robots, des cartes, des trajectoires et d'autres informations spatiales.

C'est sur cet outil que repose la visualisation des données dans l'espace via **viewer.launch.py**.

## Service

Système de communication synchrone entre deux [noeuds](#node---noeud), offrant la possibilité de réponse à une demande.

<ins>**Ex**</ins> : le [**noeud**](#node---noeud) **caméra** de **cyclosafe_core** offre un [service](#service) ```cyclosafe_interfaces/srv/SaveImages``` permettant de demander l'enregistrement dans des fichiers des dernières images prises.

## tf2

Système de transformation de coordonnées entre les différentes [`frames`](#frame---repère).

Le [package](#package) `tf2_ros` permet notamment de diagnostiquer l'ensemble des [frames](#frame---repère) et de publier des transformations statiques via `static_transform_publisher` (c'est à dire une transformation constante d'une [frame](#frame---repère) parente vers une [frame](#frame---repère) enfant).

## Topic
Thème sur lequel sont publiés des [**messages**](#message) et auquel un [**noeud**](#node---noeud) peut souscrire. Les [topics](#topic) permettent une communication asynchrone de type publish/subscribe entre les [noeuds](#node---noeud).

## URDF - *Unified Robot Description Format*
Format XML standardisé pour décrire la structure physique d'un robot, incluant ses liens (links), articulations (joints), propriétés visuelles et de collision.

**viewer.launch.py** utilise un modèle [URDF](#urdf---unified-robot-description-format) pour positionner dans l'espace les modèles 3D du vélo et des capteurs, et pour définir les transformations à effectuer pour replacer les données dans l'espace.

Fonctionne avec le [package](#package) `robot_state_publisher` qui prend en entrée une description [URDF](#urdf---unified-robot-description-format) et génère automatiquement l'arbre de transformation [`tf2`](#tf2) associé.

## Workspace - *Environnement de travail*
L'environnement de travail contenant l'ensemble du code source des [**packages**](#package) et les répertoires dans lesquels ils sont [build](#build) et [installés](#installation).

Il est nécessaire de sourcer le [**workspace**](#workspace---environnement-de-travail) afin d'utiliser les [packages](#package) qui y sont installés.

On distingue :
- le [**workspace**](#workspace---environnement-de-travail) principal où ROS2 et l'ensemble des [**packages**](#package) core sont installés (ex: `/opt/ros/jazzy` pour Jazzy)
- le [**workspace**](#workspace---environnement-de-travail) utilisateur dans lequel on peut installer ses propres [packages](#package) (ex: `~/cyclosafe/viewer`).

Le [**workspace**](#workspace---environnement-de-travail) utilisateur contient généralement 4 dossiers :
- **src/** : contient le code source des [packages](#package) à installer
- **build/** : répertoire dans lequel les [packages](#package) sont [buildés](#build) par [**colcon**](#colcon---colcon)
- **install/** : répertoire dans lequel les [packages](#package) sont [installés](#installation) par [**colcon**](#colcon---colcon) et où se trouvent les éventuelles ressources partagées
- **log/** : contient toutes les logs concernant le [build](#build) et l'[installation](#installation)

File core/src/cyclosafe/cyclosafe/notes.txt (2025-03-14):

Pour simuler des ports virtuels :
sudo socat  -d -d PTY,link=/dev/ttyV0,raw,echo=0,b115200 PTY,link=/dev/ttyV1,raw,echo=0,b115200
sudo chmod 666 /dev/ttyV*
Lancer un noeud écoutant sur un des ports, ex:

ros2 run cyclosafe sensor --ros-args -p port:='/dev/ttyV0' -p baud:=115200
cat > /dev/ttyV1

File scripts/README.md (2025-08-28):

Contient des scripts et utilitaires destinés à faciliter la récupération des données.

- [sd\_flash.sh](#sd_flashsh)
  - [Usage](#usage)
  - [Personnaliser l'environnement et les paramètres de mesure](#personnaliser-lenvironnement-et-les-paramètres-de-mesure)
- [import\_recordings.py](#import_recordingspy)
  - [Dépendance](#dépendance)
  - [Usage](#usage-1)
  - [Exemple](#exemple)
    - [Exporter en lisant directement la carte SD](#exporter-en-lisant-directement-la-carte-sd)
    - [Exporter en SSH](#exporter-en-ssh)
    - [Pour convertir/réparer seulement les données (avec des données déjà importées)](#pour-convertirréparer-seulement-les-données-avec-des-données-déjà-importées)
  - [Paramètres](#paramètres)
  - [Procédure normale](#procédure-normale)
  - [Paramètres](#paramètres-1)
- [gpx\_exporter.py](#gpx_exporterpy)
  - [Usage](#usage-2)
  - [Exemple](#exemple-1)
  - [Paramètres](#paramètres-2)
- [bag\_converter.py](#bag_converterpy)
  - [Usage](#usage-3)
  - [Exemple](#exemple-2)
  - [Paramètres](#paramètres-3)
- [decryptor.py](#decryptorpy)
  - [Usage](#usage-4)
  - [Exemple](#exemple-3)
  - [Paramètres](#paramètres-4)
- [Diagramme UML du projet (section cyclosafe/scripts)](#diagramme-uml-du-projet-section-cyclosafescripts)

# sd_flash.sh

Script interactif automatisant le flash du firmware cyclosafe vers une carte SD.
- Décompresse l'image tout en la flashant
- Calcul de la taille restante disponible sur la carte SD et estime le nombre d'heure d'enregistrement correspondant
- Ejecte la carte SD

## Usage

~~~
# Remplacer /dev/sdX par le device auquel correspond la carte SD
sudo ./sd_flash.sh ./cyclosafe_firmware.img.xz /dev/sdX
~~~

## Personnaliser l'environnement et les paramètres de mesure

Une fois la carte SD flashée et montée (généralement `/media/$HOME/rootfs`), le fichier `/media/$HOME/rootfs/home/cycliste/cyclosafe/core/setup/.env` peut être modifié pour configuré [les différentes variables d'environnement](../core/setup/README.md#env).

Les [paramètres des noeuds ROS](../core/src/cyclosafe/README.md#cyclosafe-package) tels que la fréquence de la caméra et sa résolution peuvent être configurés dans `/media/$HOME/rootfs/home/cycliste/cyclosafe/core/src/cyclosafe/launch/config.py`.

# import_recordings.py

Utilitaire permettant :
- d'exporter l'ensemble des enregistrement d'un raspberry via ssh
- de décompresser les bags et de les convertir en fichiers uniques
- de réparer les éventuels enregistrements corrompus

Il est nécessaire de préciser l'une des deux options d'import (**-u** en ssh ou **-c** pour une copie).

## Dépendance

Ce script a besoin pour fonctionner d'être lancé dans un environnement ou ROS2 est installé et sourcé.
Il est donc fortement recommandé de suivre les instructions d'installation [de ROS2 et de l'environnement cyclosafe](../viewer/README.md#installation).

## Usage

~~~
$ ./import_recordings.py --help
usage: import_recordings.py [-h] [-u HOSTNAME] [-c COPY] [-s SKIP_IMPORT] [-o OUTPUT] [-x]

Import, decompress and merge rosbag files from a remote host to single bag file. Attemmpt to repair corrupted bags.

options:
  -h, --help            show this help message and exit
  -u HOSTNAME, --hostname HOSTNAME
                        Hostname for SSH connection (user@host-ip)
  -c COPY, --copy COPY  Path to a local source directory (e.g., mounted SD card) to copy from
  -s SKIP_IMPORT, --skip_import SKIP_IMPORT
                        Skip import step and use specified local path for conversion
  -o OUTPUT, --output OUTPUT
                        Output directory for imported bags
  -x, --clean           Delete bag/ directories locally after successful import and conversion

~~~

## Exemple

### Exporter en lisant directement la carte SD

~~~
./import_recordings.py -x -c /dev/media/sda1/home/cycliste/data/ -o ~/data/test/
~~~

- `-x` : nettoie les fichiers de transition après la fin de chaque conversion afin de minimiser l'espace occupé sur l'hôte
- `-c /dev/media/sda1/home/cycliste/data/` : importer les bags depuis le chemin donné sur la carte SD.
- `-o ~/data/test/` : exporte les enregistrements vers le dossier de sortie `~/data/test/` 

### Exporter en SSH

~~~
./import_recordings.py -x -u cycliste@192.168.2.2 -o ~/data/test/
~~~

- `-x` : nettoie les fichiers de transition après la fin de chaque conversion afin de minimiser l'espace occupé sur l'hôte
- `-u cycliste@192.168.2.2` : importer les bags depuis un raspberry connecté sur le réseau avec comme profil utilisateur `cycliste` et ayant pour ip `192.168.2.2`. Le mot de passe utilisateur sera demandé (`galileo`)
- `-o ~/data/test/` : exporte les enregistrements vers le dossier de sortie `~/data/test/` 

**Résultat** :
~~~
           INFO     Output directory: /home/cycliste/data/test                 
Enter SSH password: 
           INFO     Retrieving record list from cycliste@192.168.2.2...         
           INFO     Found 9 record directories.                                
           INFO     [1/9] Importing 20250515-125430 to /home/user/data/test...
           INFO     Running: sshpass -p XXXX scp -r                        
                    cycliste@192.168.2.2:/home/cycliste/data/20250515-125430                                            
                    /home/user/data/test/        
...
INFO     [2/8] Converting bags in 20250515-125326...                       
           WARNING  /home/cycliste/data/user/20250515-125326 is missing a metadata.yaml
Attempting to repair /home/cycliste/data/user/20250515-125326/bag
           INFO     Running: unzstd
                    /home/cycliste/data/user/20250515-125326/bag/bag_0.mcap.zstd
           INFO     Successfully uncompressed bag
           INFO     Running: ros2 bag reindex .
...
           INFO     All operations completed successfully! 
~~~

### Pour convertir/réparer seulement les données (avec des données déjà importées)

Suppose que les données ont déjà été importées sur l'hôte (manuellement) mais que la conversion/décompression n'a pas été faite.

~~~
./import_recordings.py -s ~/data/test/
~~~

- `-s ~/data/test/` : spécifie le chemin où sont stockées les enregistrements.

**Résultat :**

~~~
INFO     Output directory: /home/cycliste/data/pouet                                import_recordi:246
           INFO     Found 8 record directories in /home/user/data/test
           INFO     [1/8] Converting bags in 20250516-175032...
           INFO     Converted bag already exist in /home/user/data/test/20250516-175032,
                    skipping...                                
...
           INFO     All operations completed successfully!
~~~

## Paramètres

> **-u (--hostname)**
> 	- **optionnel**
> 	- adresse ssh au format **user@ip** du raspberry à joindre
> 	- le répertoire à partir duquel importer les enregistrement sera **user@ip:/home/user/data/**

> **-c (--copy)**
> 	- **optionnel**
> 	- chemin local à partir duquel les enregistrements
> 	- **Ex:** /media/sdcard0/home/user/data

> **-o (--output-path)**
> 	- **optionnel**
> 	- **par défaut** : ~/data/import
> 	- chemin auquel importer les données sur l'host

> **-s (--skip-import)**
> 	- **optionnel**
> 	- Ignore la phase d'import
> 	- Convertit seulement les données en réparant les éventuelles corruptions

> **-c (--clean)**
> 	- **optionnel**
> 	- **par défaut** : false
> 	- Supprime le dossier bag/ des enregistrements importés afin de réduire l'espace occupés sur l'hôte

## Procédure normale

1. les enregistrements sont importés tels quel (en gardant leur strucutre) dans le dossier précisé par l'option **-o** (ou **~/data/import** si non précisé).

	Cela peut-être fait via ssh avec l'option **-u** ou par copie depuis une carte sd avec l'option **-c**.
	
	La structure d'un enregistrement importé est la suivante :
	~~~
	$ tree ~/data/
	/home/user/data/
	└── 20250515-125326 # Date de l'enregistrement
		├── bag # Dossier contenant les fichiers créés par rosbag
		│   ├── bag_0.mcap.zstd
		│   ├── bag_1.mcap.zstd
		│   └── metadata.yaml
		└── logs # Un fichier log pour chaque noeud
		    ├── ldlidar_stl_ros2_node_1008_1747313607000.log
		    ├── node_lidar_1087_1747313611560.log
		    ├── python3_1002_1747313608450.log
		    ├── python3_1004_1747313613884.log
		    ├── python3_1006_1747313608700.log
		    └── rplidar_node_1010_1747313607000.log
	~~~
2. pour chaque enregistrement, les bags morcelés en plusieurs fichiers sont réunis en un seul fichier non compressé au format **.mcap** dans un nouveau sous-dossier **out/**.

   Les bags compressés sont décompressés au passage.

   Cela est fait via la commande suivante :
   ~~~
   ros2 bag convert -i /home/user/data/20250515-125326/bag -o /home/user/data/20250515-125326/out/out_options
   ~~~

   Le fichier **out_options** dont il est question défini les paramètres de sortie de la conversion, notamment le nom de sortie du bag converti.

   Voici son contenu :
   ~~~
   output_bags:
   - uri: ./out/  # required
     storage_id: ""  # will use the default storage plugin, if unspecified
     max_bagfile_size: 0
     max_bagfile_duration: 0
     storage_preset_profile: ""
     storage_config_uri: ""
     # optional filter for msg time t [nsec since epoch]:  start_time_ns <= t <= end_time_ns
     # start_time_ns: 1744227144744197147
     # end_time_ns: 1744227145734665546
     all_topics: true # may be used as a filter
     topics: []
     topic_types: []
     all_services: true
     services: []
     all_actions: true
     actions: []
     rmw_serialization_format: ""  # defaults to using the format of the input topic
     regex: ""
     exclude_regex: ""
     exclude_topics: []
     exclude_topic_types: []
     exclude_services: []
     exclude_actions: []
     compression_mode: ""
     compression_format: ""
     compression_queue_size: 1
     compression_threads: 0
     include_hidden_topics: false
     include_unpublished_topics: false
     ~~~

3. On doit obtenir à la fin la structure suivante :
	~~~
	$ tree ~/data/
	/home/user/data/
	└── 20250515-125326 # Date de l'enregistrement
		├── bag # Dossier contenant les fichiers créés par rosbag
		│   ├── bag_0.mcap.zstd
		│   ├── bag_0.mcap
		│   ├── bag_1.mcap.zstd
		│   ├── bag_1.mcap
		│   └── metadata.yaml
		├── logs
		│   ├── ldlidar_stl_ros2_node_1008_1747314778850.log
		│   ├── node_lidar_1087_1747314783363.log
		│   ├── python3_1002_1747314780257.log
		│   ├── python3_1004_1747314785384.log
		│   ├── python3_1006_1747314780497.log
		│   └── rplidar_node_1010_1747314778850.log
		├── out # Dossier de sortie du bag converti
		│   ├── _0.mcap # Contient l'intégralité de l'enregistrement
		│   └── metadata.yaml # Information sur l'enregistrement
		└── out_options
	~~~

Techniquement, un fichier **.mcap** contient déjà une bonne partie des informations de **metadata.yaml** et peut-être utilisé indépendant du fichier metadata associé.

Par exemple, [**cyclosafe_player**](../viewer/cyclosafe_player/README.md) prend seulement un fichier **.mcap** (compressé ou non) en entrée.

Cependant de nombreux outils de ROS2 (notamment la suite **rqt**) prennent en paramètre le dossier contenant le bag et s'attendent donc à ce que ce dossier contienne également un fichier **metadata.yaml**.

## Réparation des corruptions

Lorsque le raspberry s'éteint brutalement ou que [**cyclosafed.service**](../core/setup/systemd/README.md#cyclosafedservice) n'a pas le temps de se fermer correctement, les enregistrements peuvent être corrompus. Dans ce cas il faut s'attendre à la situation suivante :

- le dernier fichier .mcap (celui en cours d'écritureau moment de l'arrêt) n'est pas compressé (.mcap au lieu .mcap.zstd)
- une corruption possible du fichier .mcap en cours d'écriture (vérifiable avec **ros2 bag info ***chemin_du_dossier_bag*****)
- une absence du fichier **metadata.yaml** qui contient les métadonnées sur le bag et qui référence l'ensemble des différents fichiers .mcap (compressés ou non).

<ins>**Exemple**</ins> :
~~~
$ tree ~/data/20250515-125326
/home/user/data/20250515-125326
├── bag # Absence du fichier metadata.yaml
│   ├── bag_0.mcap.zstd
│   └── bag_1.mcap # Le dernier bag n'est pas compressé
└── logs
    ├── ldlidar_stl_ros2_node_1008_1747313607000.log
    ├── node_lidar_1087_1747313611560.log
    ├── python3_1002_1747313608450.log
    ├── python3_1004_1747313613884.log
    ├── python3_1006_1747313608700.log
    └── rplidar_node_1010_1747313607000.log
~~~

Le script détecte les corruptions par l'absence du fichier metadata.yaml et entreprend alors de les réparer automatiquement.

La procédure est la suivante :

1. Décompresse les bags qui sont compressés
   ~~~
   unzstd ~/data/20250515-125326/bag/*.zstd
   ~~~
2. Reconstruit le fichier metadata (certains warning peuvent apparaître)
   ~~~
   ros2 bag reindex ~/data/20250515-125326/bag
   ~~~
3. A partir de de là, on peut suivre l'étape normale de la conversion

## Documentation et suppléments sur rosbag

https://github.com/ros2/rosbag2?tab=readme-ov-file#rosbag2

# gpx_exporter.py

Permet d'exporter les données GPS contenues dans un rosbag vers un format gpx.

## Usage

~~~
$ python3 ./gpx_exporter.py --help
usage: gpx_exporter.py [-h] -b BAG [-o OUTPUT_PATH] [-n NAME]

Extrait les données GPS d'un bag ROS2 et les exporte au format GPX

options:
  -h, --help            show this help message and exit
  -b BAG, --bag BAG     Chemin vers le fichier bag ROS2 (.mcap)
  -o OUTPUT_PATH, --output-path OUTPUT_PATH
                        Chemin du fichier GPX de sortie
  -n NAME, --name NAME  Nom personnalisé pour la trace GPS
~~~

## Exemple

~~~
$ python3 ./gpx_exporter.py -b ~/data/20250513-064355/out/_0.mcap
[16:49:01] INFO     Traitement terminé. 24 points GPS extraits et enregistrés dans                 gpx_exporter.py:173
                    /home/user/data/20250513-064355/out/trace.gpx   
~~~

## Paramètres

> **-b (--bag)**
> 	- **obligatoire**
> 	- chemin vers le bag à partir duquel extraire les données gps

> **-o (--output-path)**
> 	- **optionnel**
> 	- chemin de sortie pour la trace gpx
> 	- si non indiqué, elle sera enregistrée dans le même répertoire que le bag

> **-n (--name)**
> 	- **optionnel**
> 	- nom de la trace gpx (il ne s'agit pas du nom du fichier mais bien de la trace)

# bag_converter.py

Utilitaire permettant d'exporter les données d'un rosbag vers des fichiers CSV et d'extraire les images. Supporte les types de messages LaserScan, CompressedImage, Image et NavSatInfo.

## Usage

~~~
$ python3 ./bag_converter.py --help
usage: bag_converter.py [-h] [-o OUTPUT] [-v] bag_path

Export ROS bag data to CSV files and extract images

positional arguments:
  bag_path              Path to the directory containing ROS bag files

options:
  -h, --help            show this help message and exit
  -o OUTPUT, --output OUTPUT
                        Output directory (default: bag_path/export)
  -v, --verbose         Enable verbose logging
~~~

## Exemple

~~~
$ python3 ./bag_converter.py ~/data/20250515-125326/out/
Processing bag from: /home/user/data/20250515-125326/out
Found 4 topics and 2847 messages
Processing messages... ━━━━━━━━━━━━━━━━━━━━━━━━━━━━━━━━━━━━━━━━ 100% 0:00:12
Export completed
LaserScan messages: 1205
GPS messages: 87
Images exported: 1555
Errors: 0
Output directory: /home/user/data/20250515-125326/out/export
~~~

La structure de sortie générée est la suivante :
~~~
$ tree ~/data/20250515-125326/out/export/
/home/user/data/20250515-125326/out/export/
├── images/                           # Images extraites
│   ├── 20250515-125430_123.jpeg
│   ├── 20250515-125431_456.jpeg
│   └── ...
├── images_metadata.csv              # Métadonnées des images
├── lidar_scan_LaserScan.csv        # Données LiDAR
└── gps_NavSatInfo.csv              # Données GPS
~~~

## Paramètres

> **bag_path**
> 	- **obligatoire**
> 	- chemin vers le dossier contenant les fichiers bag ROS2

> **-o (--output)**
> 	- **optionnel**
> 	- **par défaut** : bag_path/export
> 	- répertoire de sortie pour les fichiers exportés

> **-v (--verbose)**
> 	- **optionnel**
> 	- **par défaut** : false
> 	- active les logs détaillés pour le débogage

Le script traite les types de messages suivants :
- **LaserScan** : exporte les données LiDAR avec les ranges, intensités et métadonnées de scan
- **NavSatInfo** : exporte les données GPS avec latitude, longitude, altitude et statut
- **CompressedImage/Image** : extrait les images et génère un fichier de métadonnées associé

Les images sont sauvegardées de manière asynchrone pour optimiser les performances, et le script gère automatiquement les différents formats d'encodage d'images.

# decryptor.py

Utilitaire de déchiffrement et décompression pour les fichiers de bags ROS chiffrés. Compatible avec le chiffrement hybride RSA+AES et la compression zstd.

## Usage

~~~
$ python3 ./decryptor.py --help
usage: decryptor.py [-h] --private-key PRIVATE_KEY [--file FILE] [--directory DIRECTORY] 
                    [--output-dir OUTPUT_DIR] [--verify] [--info] [--verbose]

ROS bag file decryptor

options:
  -h, --help            show this help message and exit
  --private-key PRIVATE_KEY
                        Path to private key
  --file FILE           Encrypted file to decrypt
  --directory DIRECTORY
                        Directory containing encrypted files
  --output-dir OUTPUT_DIR
                        Output directory for decrypted files
  --verify              Verify file integrity only
  --info                Show info of encrypted files
  --verbose, -v         Verbose mode
~~~

## Exemple

~~~
$ python3 ./decryptor.py --private-key private_key.pem --file ~/data/encrypted/bag_0.mcap.enc
2025-08-19 14:32:15,123 - INFO - Private key successfully loaded
2025-08-19 14:32:15,247 - INFO - Decrypted file saved: /home/user/data/encrypted/bag_0.mcap
Decrypted file: /home/user/data/encrypted/bag_0.mcap

$ python3 ./decryptor.py --private-key private_key.pem --directory ~/data/encrypted/ --output-dir ~/data/decrypted/
2025-08-19 14:33:02,456 - INFO - Private key successfully loaded
2025-08-19 14:33:02,789 - INFO - Decrypted file saved: /home/user/data/decrypted/bag_0.mcap
2025-08-19 14:33:03,012 - INFO - Decrypted file saved: /home/user/data/decrypted/bag_1.mcap
2025-08-19 14:33:03,234 - INFO - Decryption finished: 2/2 files
Decryption finished: 2 files processed
  - /home/user/data/decrypted/bag_0.mcap
  - /home/user/data/decrypted/bag_1.mcap
~~~

**Vérification d'intégrité :**
~~~
$ python3 ./decryptor.py --private-key private_key.pem --file bag_0.mcap.enc --verify
Verification of bag_0.mcap.enc: Valid file

$ python3 ./decryptor.py --private-key private_key.pem --directory ~/data/encrypted/ --verify
Verification of bag_0.mcap.enc: Valid file
Verification of bag_1.mcap.enc: Valid file
~~~

**Information sur les fichiers chiffrés :**
~~~
$ python3 ./decryptor.py --private-key private_key.pem --file bag_0.mcap.enc --info
Encrypted file info: bag_0.mcap.enc
  Original name: bag_0.mcap
  Encryption method: RSA-OAEP + AES-256-CBC
  Compression method: zstd
  Timestamp: 2025-08-19T14:30:12.456789
  Encrypted key size: 256 bytes
  IV size: 16 bytes
  Encrypted data size: 15728640 bytes
~~~

## Paramètres

> **--private-key**
> 	- **obligatoire**
> 	- chemin vers la clé privée RSA au format PEM pour le déchiffrement

> **--file**
> 	- **optionnel**
> 	- chemin vers un fichier .enc à déchiffrer
> 	- mutuellement exclusif avec --directory

> **--directory**
> 	- **optionnel**
> 	- répertoire contenant les fichiers .enc à déchiffrer
> 	- mutuellement exclusif avec --file

> **--output-dir**
> 	- **optionnel**
> 	- **par défaut** : même répertoire que les fichiers chiffrés
> 	- répertoire de sortie pour les fichiers déchiffrés

> **--verify**
> 	- **optionnel**
> 	- vérifie uniquement l'intégrité des fichiers chiffrés sans les déchiffrer

> **--info**
> 	- **optionnel**
> 	- affiche les métadonnées des fichiers chiffrés sans les déchiffrer

> **--verbose**
> 	- **optionnel**
> 	- **par défaut** : false
> 	- active les logs détaillés pour le débogage

Le script supporte le déchiffrement de fichiers utilisant :
- **Chiffrement hybride** : RSA-OAEP pour la clé AES + AES-256-CBC pour les données
- **Compression** : décompression automatique zstd
- **Intégrité** : vérification des métadonnées et de la structure des fichiers chiffrés

Le processus de déchiffrement supprime automatiquement les métadonnées de chiffrement et restaure le fichier original dans son format natif.

# Diagramme UML du projet (section cyclosafe/scripts)

uml diagram of cyclosafe project

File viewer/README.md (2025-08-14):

# Cyclosafe viewer

Ce dossier contient l'ensemble des packages et utilitaires permettant de visualiser les données du projet cyclosafe.

- [Cyclosafe viewer](#cyclosafe-viewer)
  - [Structure](#structure)
  - [Installation](#installation)
    - [ROS2](#ros2)
    - [Installation de ROS2](#installation-de-ros2)
  - [Usage](#usage)
    - [Sourcer le workspace](#sourcer-le-workspace)
    - [Résoudre les dépendances avec rosdep](#résoudre-les-dépendances-avec-rosdep)
    - [Build et installation des packages](#build-et-installation-des-packages)
    - [Alias fournis par le script .bashrc](#alias-fournis-par-le-script-bashrc)
      - [cy\_viewer\_build](#cy_viewer_build)
      - [cy\_viewer\_clean](#cy_viewer_clean)
    - [Visualiser les données à partir d'un bag](#visualiser-les-données-à-partir-dun-bag)
    - [Visualiser les données en direct](#visualiser-les-données-en-direct)
  - [Activer mapviz et rviz\_satellite (facultatif)](#activer-mapviz-et-rviz_satellite-facultatif)

uml diagram of cyclosafe project

## Structure

> [**./**](core/README.md) : répertoire courant, correspond aussi au workspace  utilisé par **ROS2** dans lequel les packages sont installés.
> 
> [**src/**](core/README.md) : répertoire contenant le code source des outils de visualisation et d'analyse, c'est àdire:
>   - [**cyclosafe_config**](../core/src/cyclosafe_config/README.md) : symlink vers le package python cyclosafe_config du [**core/**](../core/), nécessaire  sur l'hôte car utilisé par `cyclosafe_viewer`.
>   - [**cyclosafe_interfaces**](../core/src/cyclosafe_interfaces/README.md) : symlink vers le package python cyclosafe_interfaces du [**core/**](../core/), nécessaire  sur l'hôte car utilisé par le script [`gpx_exporter`](../scripts/README.md#gpx_exporterpy).
>   - [**cyclosafe_player**](src/cyclosafe_player/README.md) : package python permettant de jouer et de contrôler la lecture de rosbag et de visualiser graphiquement des distances
>   - [**cyclosafe_viewer**](src/cyclosafe_viewer/README.md) : package python permettant de visualiser les données sur Rviz
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

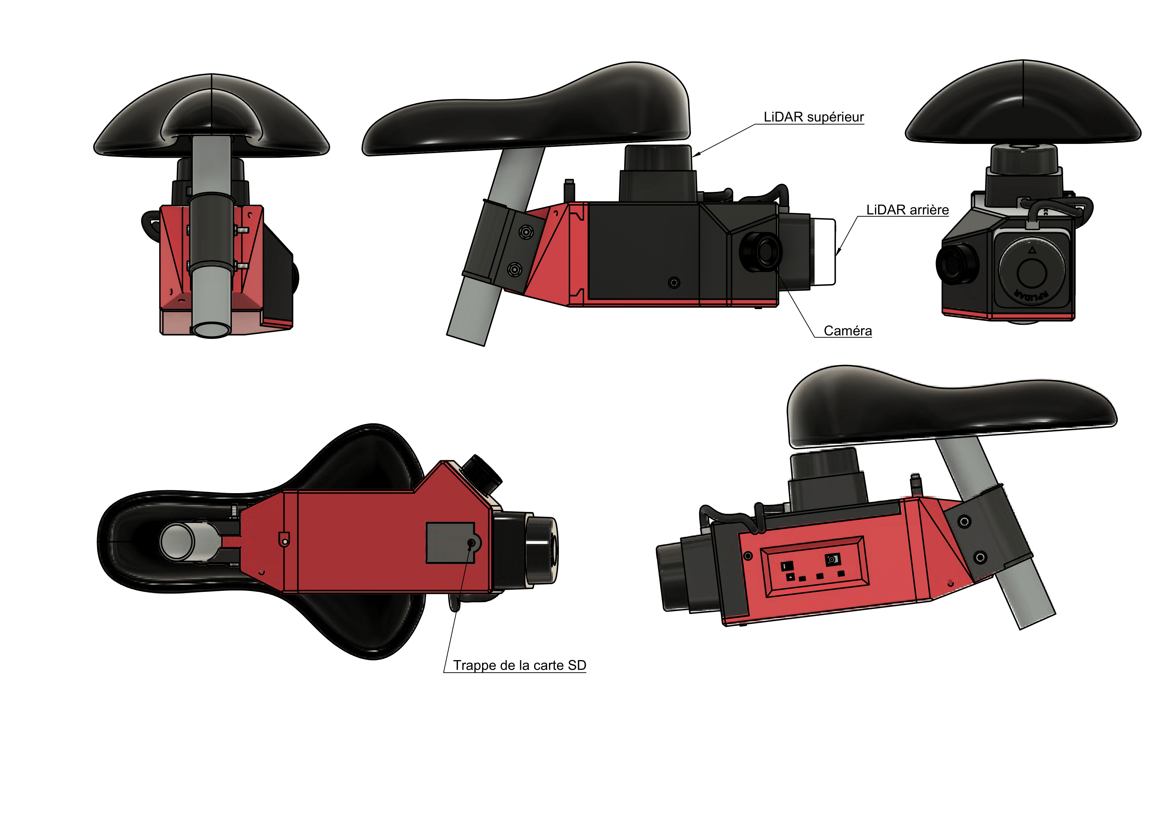
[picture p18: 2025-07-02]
design/docs/vue-globale-detail.png

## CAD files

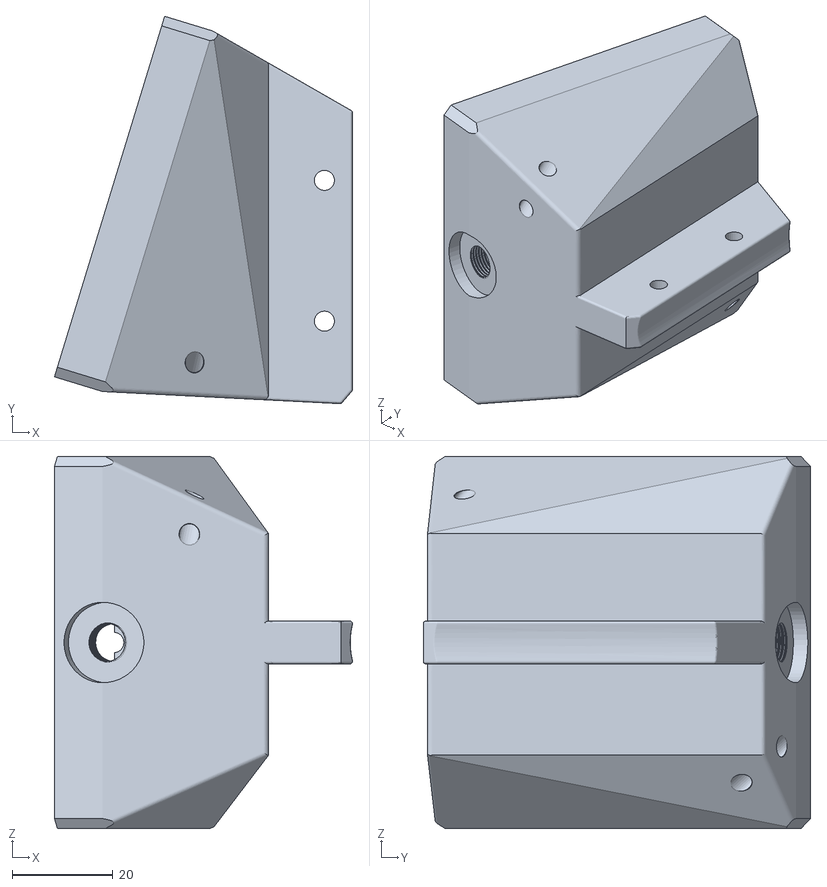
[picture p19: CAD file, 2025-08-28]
design/docs/3D-print/assemblage-femelle.stl
59.3 x 77.1 x 74.0

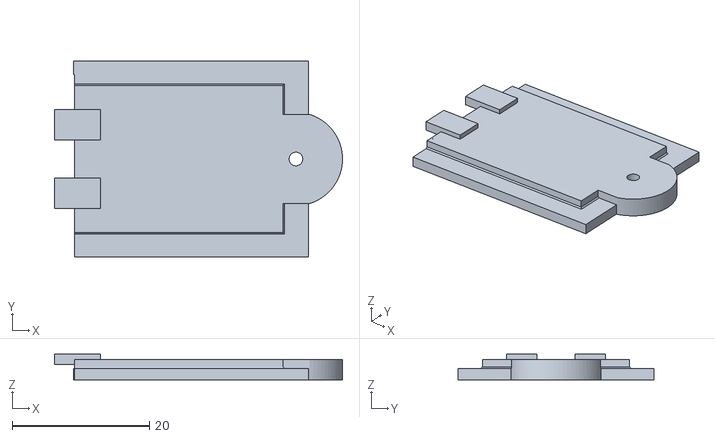
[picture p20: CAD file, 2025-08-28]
design/docs/3D-print/couvercle-sd.stl
42.0 x 28.6 x 3.75

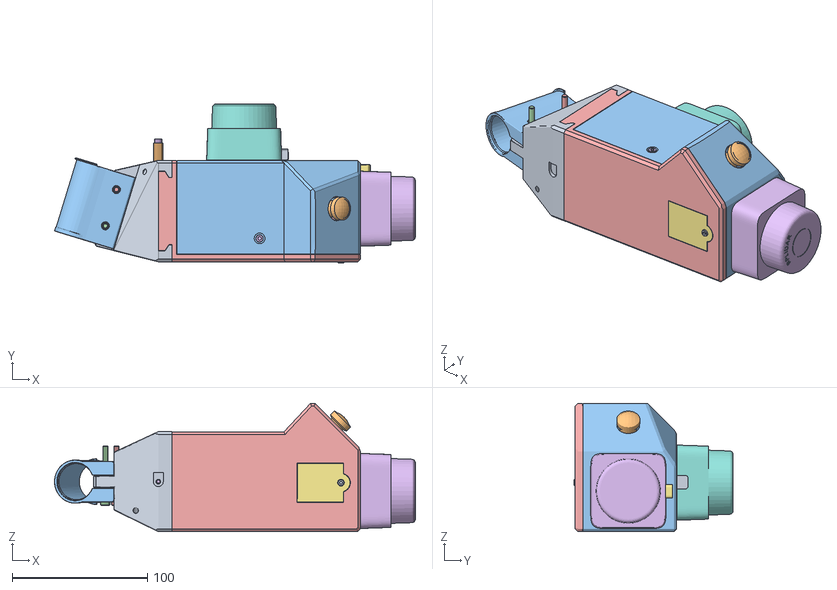
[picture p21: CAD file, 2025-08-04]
viewer/src/cyclosafe_viewer/urdf/model/module.obj
267.0 x 117.8 x 94.9
Corps1
Corps2
seatpost clamp
Corps1:1
Corps1:2
Corps1:3
Corps1:4
Corps1:5
Corps1:6
Corps1:7
Corps2:1
Corps3
Corps4
Corps5
Corps6
Corps7
Corps8
Corps9
Corps10
Corps11
Corps12
Corps13
Corps14
Corps15
Corps16
Corps17
Corps1:8
Corps1:9
boitier haut
Corps1:10
Corps2:2
Corps1:11
Corps2:3
Corps1:12
boitier haut (1)
Corps1:13
Corps1:14
Corps1:15

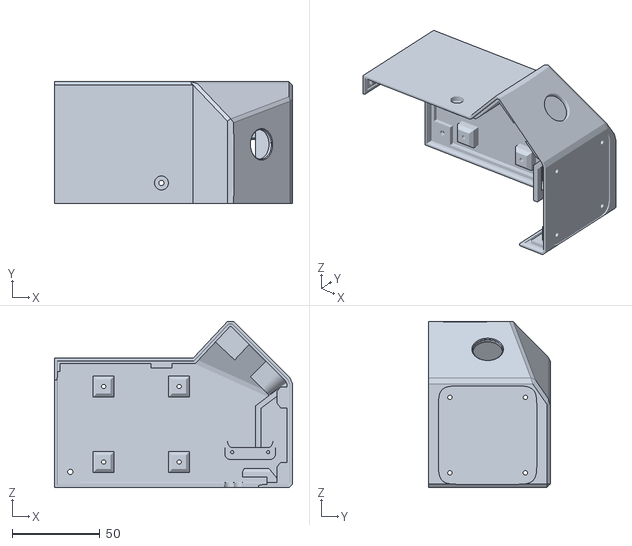
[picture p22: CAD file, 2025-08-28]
design/docs/3D-print/boitier-haut.stl
135.6 x 69.3 x 94.7

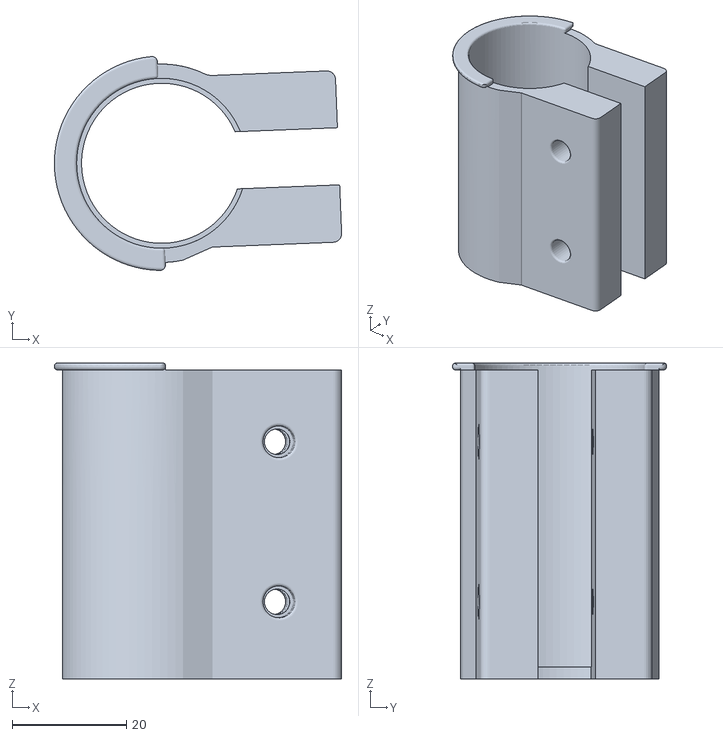
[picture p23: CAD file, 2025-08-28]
design/docs/3D-print/collier.stl
50.3 x 37.4 x 55.3

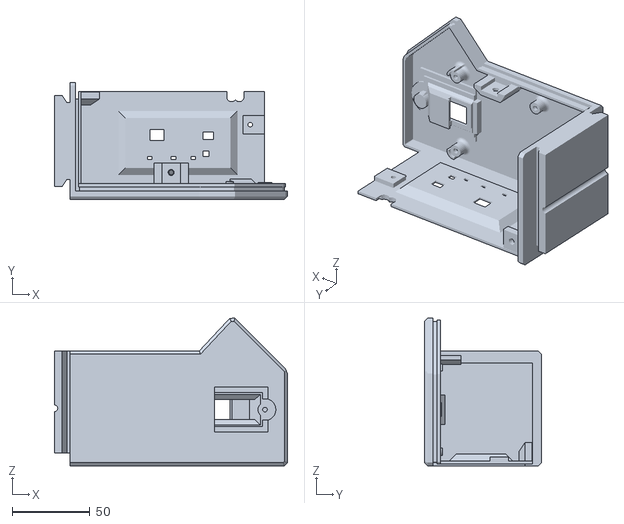
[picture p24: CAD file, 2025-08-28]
design/docs/3D-print/boitier-bas.stl
149.6 x 75.0 x 94.7

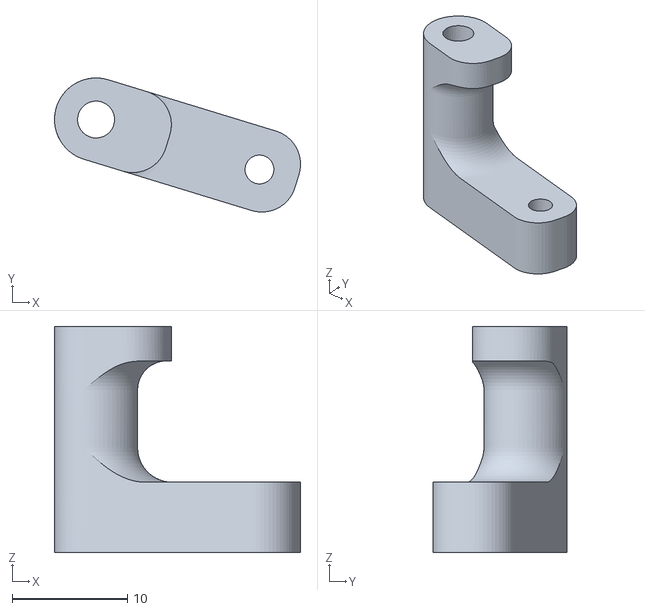
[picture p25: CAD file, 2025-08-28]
design/docs/3D-print/locking-pin.stl
21.3 x 11.6 x 19.6

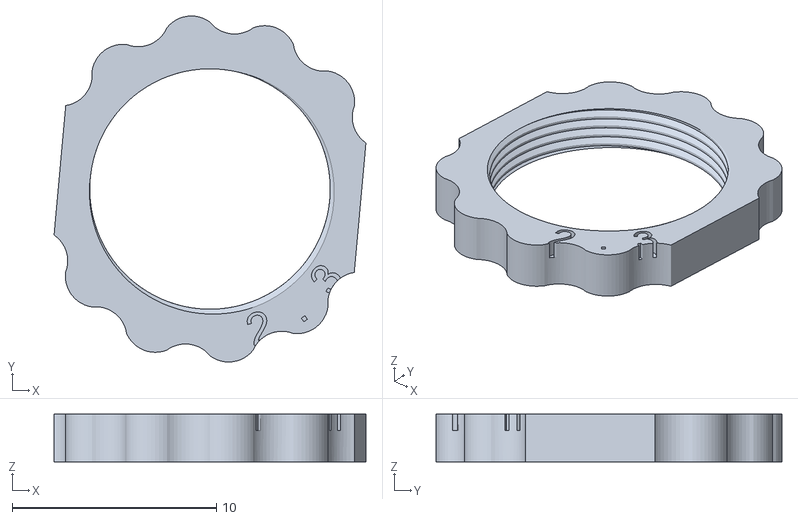
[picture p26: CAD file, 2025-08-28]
design/docs/3D-print/focus lockring_2.3.stl
15.3 x 16.9 x 2.35

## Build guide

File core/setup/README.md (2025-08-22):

# Scripts d'installation et de configuration de l'environnement

Ce dossier contient :

- les scripts d'installation de l'environnement de travail :
	- [**ros_install.sh**](#ros_installsh)
	- [**install.sh**](#installsh)
	- [**systemd/setup_services.sh**](#systemdsetup_servicessh)
	- [**ip_config.sh**](#ip_configsh)
- le fichier [**.env**](#env) définissant les variables d'environnement nécessaires au projet.
- les fichiers [**config.txt**](#configtxt) et [**cmdline.txt**](#cmdlinetxt) indiquant les modifications à faire sur la partition boot pour activer/désactiver les différentes interfaces hardware
- le fichier [**.bashrc**](#bahrc) permettant de sourcer l'environnement cyclosafe

# Usage

Dans la plupart des cas vous pouvez simplement lancer le script **install.sh**.

~~~
chmod +x ./install.sh
./install.sh
~~~

Si vous souhaitez seuelement installer ROS, lancez le script **ros_install.sh**.

~~~
./ros_install.sh
~~~

Si vous souhaitez seulement mettre en place les services systemd, lancez le script **systemd/setup_services.sh**

~~~
./systemd/setup_services.sh
~~~

## Scripts d'installation

L'objectif de ces différents scripts est de faciliter et d'automatiser l'installation de toutes les dépendances et l'environnement nécessaires.

### install.sh

Peut-être lancé à partir d'une installation vierge ou partielle.

- si besoin, modifie les fichiers /boot/firmware/config.txt et /boot/firmware/cmdline.txt afin d'activer les overlays nécessaires au projet et de désactiver l'ipv6.
- lance ros_install.sh si ROS n'est pas installé
- installe les dépendances des packages présents dans le workspace de cyclosafe
- build les packages présents dans le workspace de cyclosafe
- configure et activent les services systemd s'ils ne sont pas déjà activés

### ros_install.sh

Basé sur ce repo : https://github.com/Ar-Ray-code/rpi-bullseye-ros2

- Télécharge le paquet de ROS2-jazzy pour debian bookworm et l'installe.
- Rétrograde **empy** à la version *3.3.4* afin d'éviter une erreur de compabilité avec des dépendances de ROS.
- Installe des dépendances manquantes au paquet .deb
- Initialise et mets à jour la base de données rosdep permettant de référencer des dépendances spécifiques à ROS
- Installe un ensemble d'autres dépendances (voir le script pour les détails)

### systemd/setup_services.sh

Teste la présence de chacun des 4 services nécessaires à cyclosafe, et les configure puis les active si nécessaire.

Voir [**la page dédiée aux services**](systemd/README) pour plus d'info.

### ip_config.sh

Créer et active un profil réseau permettant de se connecter au raspberry depuis l'hôte.

Il s'agit d'un condensé de la configuration réseau à effectuer sur le raspberry.

Voir les [**instruction complètes**](../../network.md) pour plus de détails

## cmdline.txt

S'ajoute au fichier de configuration ***/boot/firmware/cmdline.txt*** (ce qui est fait automatiquement avec le script **setup.sh**).

> **ipv6.disable=1** : Désactive ipv6 pour éviter des problèmes DNS lors du téléchargement de certains paquets (notamment en passant par le réseau de l'IGN)

> ***Note*** : si jamais le service systemd gpiod.service détecte perpétuellement un appui sur le bouton au démarrage et que le raspberry devient inaccessible, il est possible de modifier ***/boot/firmware/cmdline.txt*** via un lecteur de carte sd de cette façon là afin de masquer le service au démarrage :
>
	> ipv6.disable=1 systemd.mask=gpiod.service

## config.txt

S'ajoute au fichier de configuration ***/boot/firmware/config.txt*** (ce qui est fait automatiquement avec le script **setup.sh**).

> **dtoverlay=disable-bt** : désactive le bluetooth

> **enable_uart=1** : active l'uart

> **dtoverlay=uartN** : active les interfaces uart utilisées par cyclosafe

## .bashrc

Permet de sourcer dans un terminal l'environnement de cyclosafe, c'est à dire :
- ROS2 et ses utilitaires
- les noeuds ROS2 de cyclosafe
- le fichier **.env** contenant les variables d'environnement propres à cyclosafe
- des alias utiles :
	- **cy_core_build** : compile l'ensemble des packages (en respectant le repertoire d'installation) et source automatiquement les ajouts
		> `alias cy_core_build="cd $CYCLOSAFE_WORKSPACE; colcon build --symlink-install --parallel-workers=2; source ./setup/.bashrc; cd -"`
	- **cy_core_clean** : nettoie le workspace ROS de cyclosafe en repartant sur une installation vierge
		> `alias cy_core_clean="cd $CYCLOSAFE_WORKSPACE; rm -rf build/ install/ log/; source ./setup/.bashrc; cd -;"`

**Usage**:
`source ./.bashrc`

**Pour sourcer automatiquement l'environnement à l'ouverture d'un terminal** :
`$(cat ./bashrc) >> ~/.bashrc`

## .env

Définit l'ensemble des variables d'environnement utilisées par cyclosafe.

> **CYCLOSAFE_WORKSPACE** : répertoire où se trouve les dossiers principaux de cyclosafe (cad le sous-dossier **core** du repo)

> **CYCLOSAFE_RECORD** : répertoire où sauvegarder les enregistrement de données

> **CYCLOSAFE_LOGS** : répertoire où sauvegarder les logs des différents scripts ([**gps_time.sh**](../scripts/README#gps_timesh) et [**gpio.sh**](../scripts/README#gpiosh))

> **GPS_SERIAL_PORT** : serial device sur lequel est branché le GPS. Utilisé par [**gps_time.sh**](../scripts/README#gps_timesh) pour mettre à jour l'heure et la date du système.

> **SCRIPTS_PATH** : répertoire où trouver les différents scripts lancés par les services systemd. A priori équivalent à **$CYCLOSAFE_WORKSPACE/scripts**

> **SHUTDOWN_DELAY** : temps imparti à l'arrêt du service [**cyclosafed.service**](systemd/README#cyclosafedservice) pour se terminer correctement avant d'éteindre le raspberry.

> **LOW_BATTERY_PERCENT** : pourcentage de batterie (valuer flottante de 0 à 1) en dessous duquel s'allume le boyant batterie faible 

> **LOW_STORAGE_TRESHOLD** : espace de stockage (en MO) disponible en dessous duquel s'allume le voyant de stockage plein.

> **LED_BRIGHTNESS** : valeur flottante de 0 à 1 définissant le luminosité avec laquelle les leds sont allumées

> **ENCRYPTION** : `1` pour activer l'encryptage des bags à mesure qu'ils sont créés.

> **PUBLIC_KEY_PATH** : chemin vers le fichier `.pem` contenant la clé publique à utiliser pour l'encryptage des bags.

> **EXPECTED_NODES** : définit le nombre de noeud attendu par le service systemd **cyclosafed.service**. Si celui-ci ne détecte pas consécutivement deux fois le bon nombre de noeuds, il est redemarré. Ex : avec encrypt = 1 et tous les noeuds actifs (2*lidars + 1*gps + 1*camera + 1*bag_recorder + 1*encrypt_node = 6). Si encrypt = 0, `EXPECTED_NODES` devra être abaissé à 5.

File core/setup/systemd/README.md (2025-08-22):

# Services systemd

Ce dossier contient des templates de configuration pour les différents services utilisés par cyclosafe.

**Important**: pour une installation vierge, préférez l'utilisation du script setup_services.sh qui ajuste plus finement les paramètres en fonction des varaibles d'environnement configurées. Les fichiers de configuration seront automatiquement créés et installés.

Ces services utilisent à chaque démarrage le fichier d'environnement .env du workspace de cyclosafe.

> Une fois configurés, chacun peut-être personnalisé au chemin suivant: ***/etc/systemd/system/[nom_du_service.service]***
> 
> Pour prendre en compte une modification:
> 
> sudo systemctl daemon-reload
>
> sudo systemctl restart [nom_du_service.service]

## cyclosafed.service

C'est le service responsable de lancer la launch description principale de cyclosafe. Voir [**cyclosafe.launch.py**](../../src/cyclosafe/README.md#launch-description)

S'il est activé (**sudo systemctl enable cyclosafed.service**), les mesures sont prises dès le démarrage du raspberry.

Il lance le script [`launch_wrapper.sh`](../../scripts/launch_wrapper.sh). Il s'agit d'un wrapper pour sourcer l'environnement ROS et executer la commande `ros2 launch cyclosafe cyclosafe.launch.py record:=true`.

> **Note** : ce service est dépendant du bon fonctionnement des services [**gpiod.service**](#gpiodservice) et [**gps_time.service**](#gps_timeservice).

> Si un des noeuds n'est pas correment lancé ou s'arrête, le service est relancé.

### Fermeture : SIGINT

Le signal utilisé pour la fermeture (**SIGINT**) est primordiale car il définit la façon dont la prise de mesure s'arrête.

En cas d'enregistrement des données (**record:=true**), il est essentiel que le programme rosbag puisse terminer de vider son cache et d'écrire le fichier ***metadata.yaml***.

Lors d'une fermeture brutale causée par un timeout de la procédure d'arrêt (délai ***TimeoutStopSec=6*** atteint) ou d'une coupure d'alimentation, il faut s'attendre à :
- le dernier fichier .mcap (celui en cours d'écritureau moment de l'arrêt) ne sera pas compressé (.mcap au lieu .mcap.zstd)
- une corruption possible du fichier .mcap en cours d'écriture (vérifiable avec **ros2 bag info ***chemin_du_dossier_bag*****)
- une absence du fichier **metadata.yaml** contenant les métadonnées sur le bag et référencant l'ensemble des différentes fichiers .mcap (compressés ou non). Après avoir décompresser l'ensemble des bags en .zstd, celui-ci peut-être reconstruit à l'aide de **ros2 bag reindex ***chemin_du_dossier_bag*****.

> Note: Le [**script d'import des enregistrements**](../../../scripts/README.md#réparation-des-corruptions) inclue une fonction permettant de réparer automatiquement les corruptions listées ci-dessus.

### Valeurs paramètrables

**SHUTDOWN_DELAY** : ajuste le temps imparti à l'arrêt normal du service avant de lui envoyer un **SIGTERM** ou un **SIGKILL** (causant une probable corruption de données). ***TimeoutStopSec*** étant défini à **SHUTDOWN_DELAY + 1**.

**CYCLOSAFE_RECORD** : définit le répertoire où les enregistrements sont sauvegardés

## gpiod.service

Service démarrant le script [**gpio.sh**](../../scripts/README#gpiosh).

Il est crucial que ce service démarre correctement car le script est responsable :

- du monitoring du bouton d'extinction
- du contrôle des leds
- du monitoring de la tension de la batterie
- du monitoring de l'espace restant sur la carte SD
- de l'arrêt propre de cyclosafed.service

## gps_time.service

Service démarrant le script [**gps_time.sh**](../../scripts/README#gps_timesh).

Le script est lancé une seule fois à chaque démarrage.

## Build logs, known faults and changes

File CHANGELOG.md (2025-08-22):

# Changelog

## [1.2.0] - 2025-08-19

### Added

- **ENCRYPTION**
  - encryptor node to compress and encrypt ros bag as they are created
  - encryptor node use AES algorithm, the key is encrypted with an RSA public key.
    - the only way to decrypt the AES key is to have to RSA private key
- core/.env : `$ENCRYPTION` environment variable can be defined to 1 to enable encryption
- import_recordings : added verbose option to enable `INFO` log level (default is set to WARNING)
- launch_wrapper.sh: `$EXPECTED_NODE` is now defined by an env variable.
- camera_node : added `no_compression` to disable jpeg compression when saving images
- bag_converter.py : updated script to export non-compressed images

### Modified

- cyclosafe.launch.py:
  - if `$ENCRYPTION=1` :
    - rosbag recorder is launched withtout compression
    - encryptor node is launched
  - else
    - rosbag recorder is launched with compression
    - encryptor node is not launched*
- launch_wrapper.sh :
  - adapted `$EXPECTED_NODE` calculation to handle the encryptor node
- .env: `$SHUTDOWN_DELAY` default value increased to 10s in order for the encryptor node to finish its encryptions
- scripts/csv_importer : adapted scripts to be more efficient, simplified module imports
- core/launch_wrapper.sh : number of node is now checked twice
- gpio.py : removed pigpiod dependancy and now use gpiozero
- package.json : changed python3-pigpio to python3-gpiozero
- gpio.sh : SHUTDOWN_DELAY is now a maximum timeout, and the system can stop quicker if cyclosafed.service has exited cleanly.

### Fixed

- core/gpio.sh : last warning check to log when shutdown while cyclosafed.service still active was targetting wrong service name
- issue with pigpiod :  the stop button was randomly not working

## [1.1.1] - 2025-08-14

### Added
- cyclosafe_viewer : implementd invert_lidar argument to use another urdf model where both lidar transformation are inverted , in case lidar connections are wrong
- various readme : uml modl + simplified node schematic added

### Modified
- design/ : updated BOM

## [1.1.0] - 2025-08-08
### Added
- CHANGELOG.md file
- CONTRIBUTORS.md file
- viewer/cyclosafe_player: visualize gps trace on map widget + live position + gps data curve and live output
- scripts/import_recording: env check in import_recording script
- viewer/dependancies: python3-rich to ROS env (viewer/cyclosafe_viewer/package.json)
- README: section mentionning context of the project
- README: section expliciting what material is concerned by the new CeCILL-B license
- added 3 csv script exporter files in scripts/
- added automatic csv conversion to import_recording script

### Modified
- License CeCILL updated to CeCILL-B (from GPL to BSD) in order to make the project easier to redistribute
- README: 
  - updated project description 
  - translated main page to english
  - new name for the repo to be more exhaustive
- core/gpio.py: changed shutdown button max latency from 0.5s to 0.25s
- viewer/cyclosafe_player: updated image preview
- scripts/README: added recommendation to install cyclosafe env from viewer/README
- core/README : added reference to ROS2.md

### Fix
- cyclosafe_player:
  - missing python3-pyqt5.qtwebengine dependancy in package.json
  - nan check for angle_min, angle_max and angle_increment in lidar message
- core/scripts/gpio.py : missing import pigpio (removed in a previous commit for no reason), missing import sys (non fatal) + intercept exception related to i2c to ensure the script won't crash

## [1.0.0] - 2025-08-06
### Added
- Initial version of repo associated with a compressed firmware image.

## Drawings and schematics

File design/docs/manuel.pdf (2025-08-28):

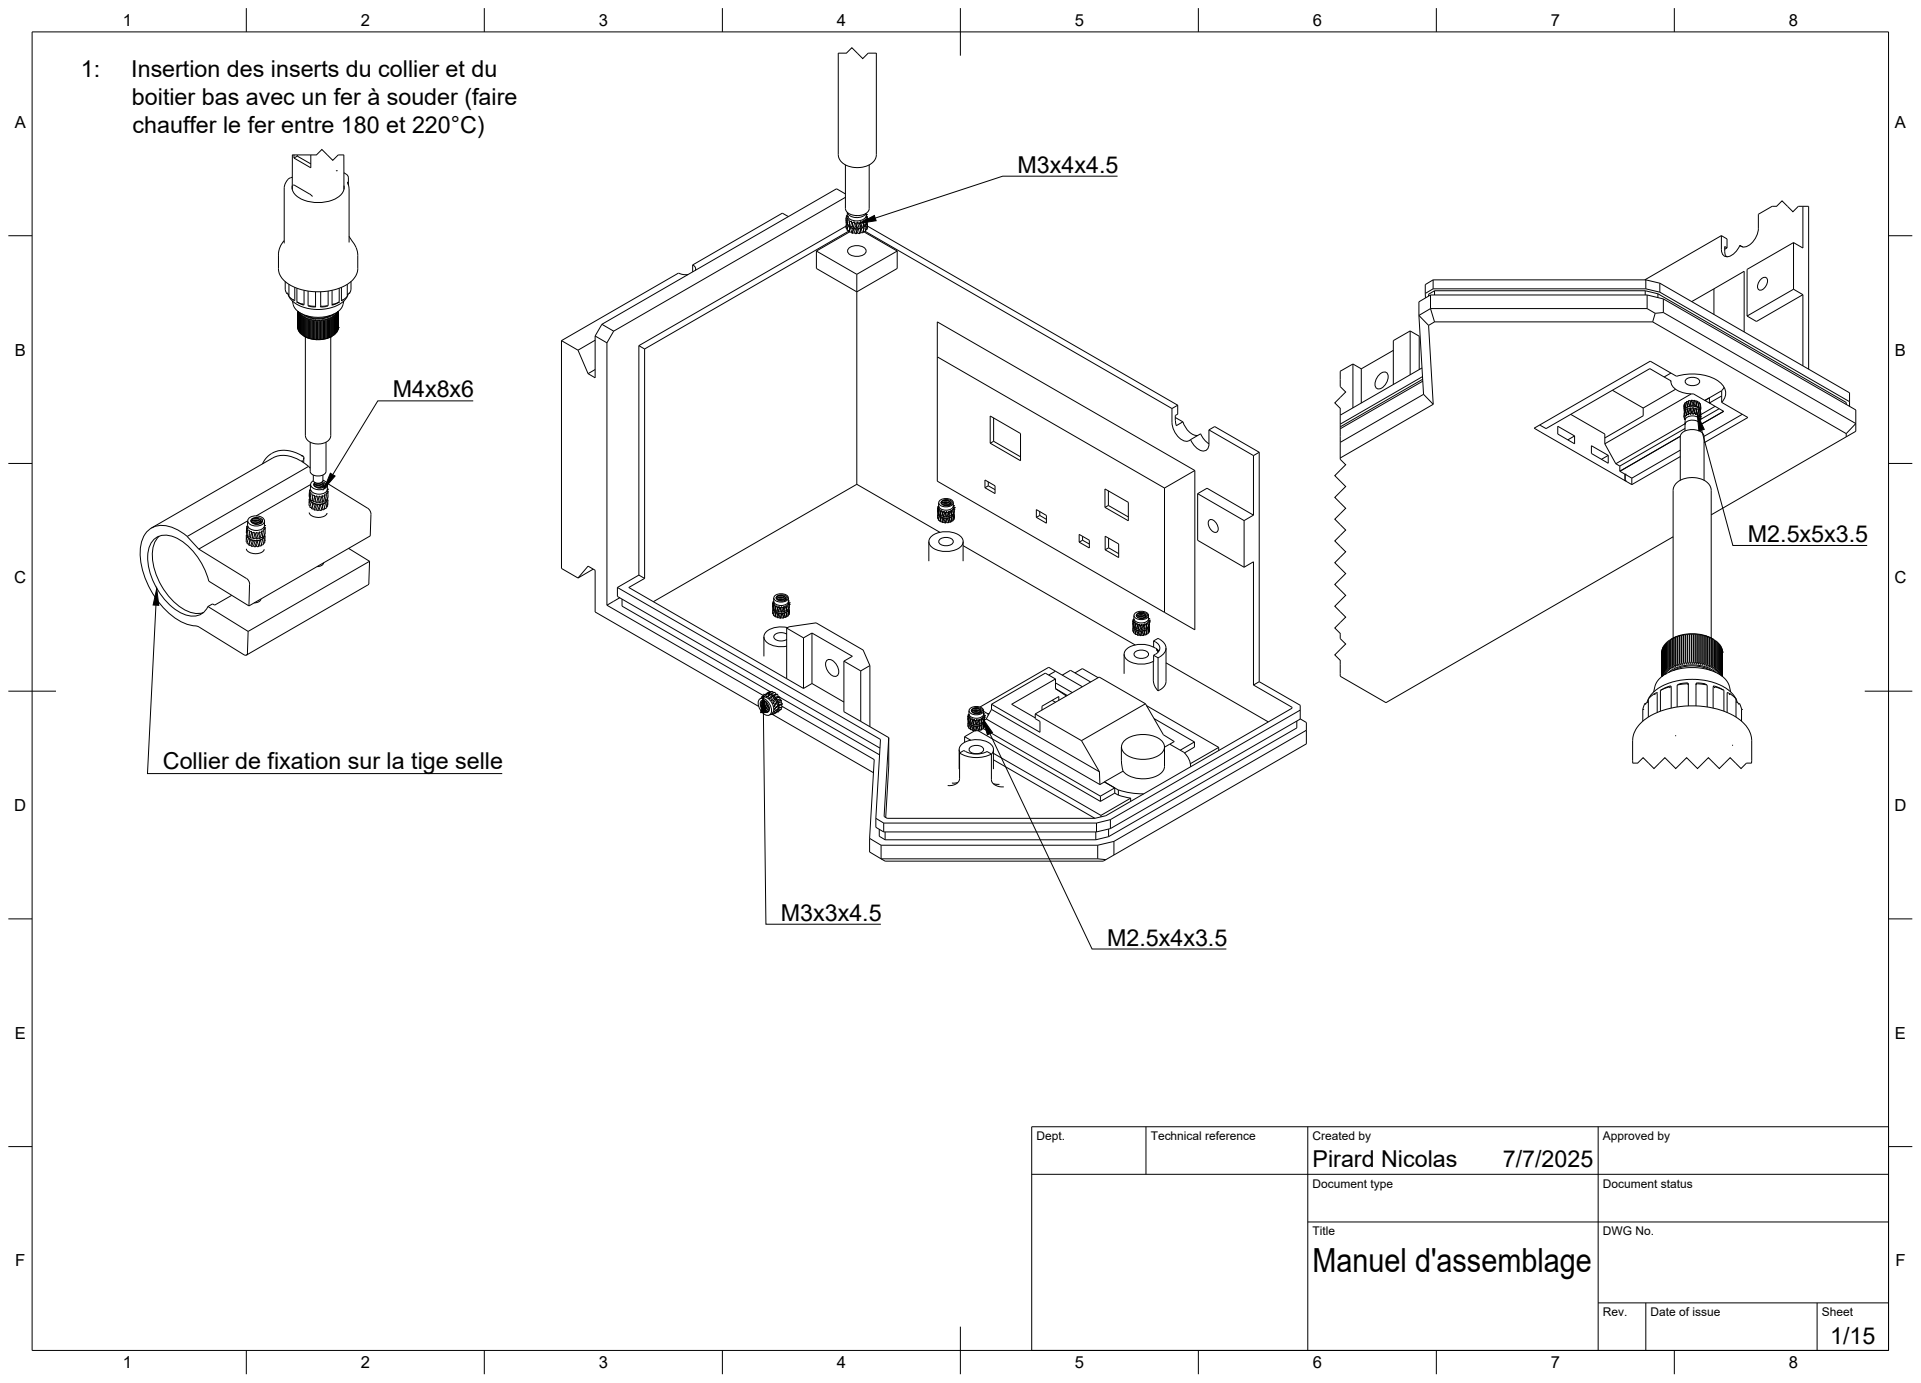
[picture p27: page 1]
Insertion des inserts du collier et du

boitier bas avec un fer à souder (faire
chauffer le fer entre 180 et 220°C)

Collier de fixation sur la tige selle

Dept. | Technical reference | Created by Pirard Nicolas 7/7/2025 | Approved by

Document type | Document status

Title Manuel d'assemblage | DWG No.

Rev. | Date of issue | Sheet

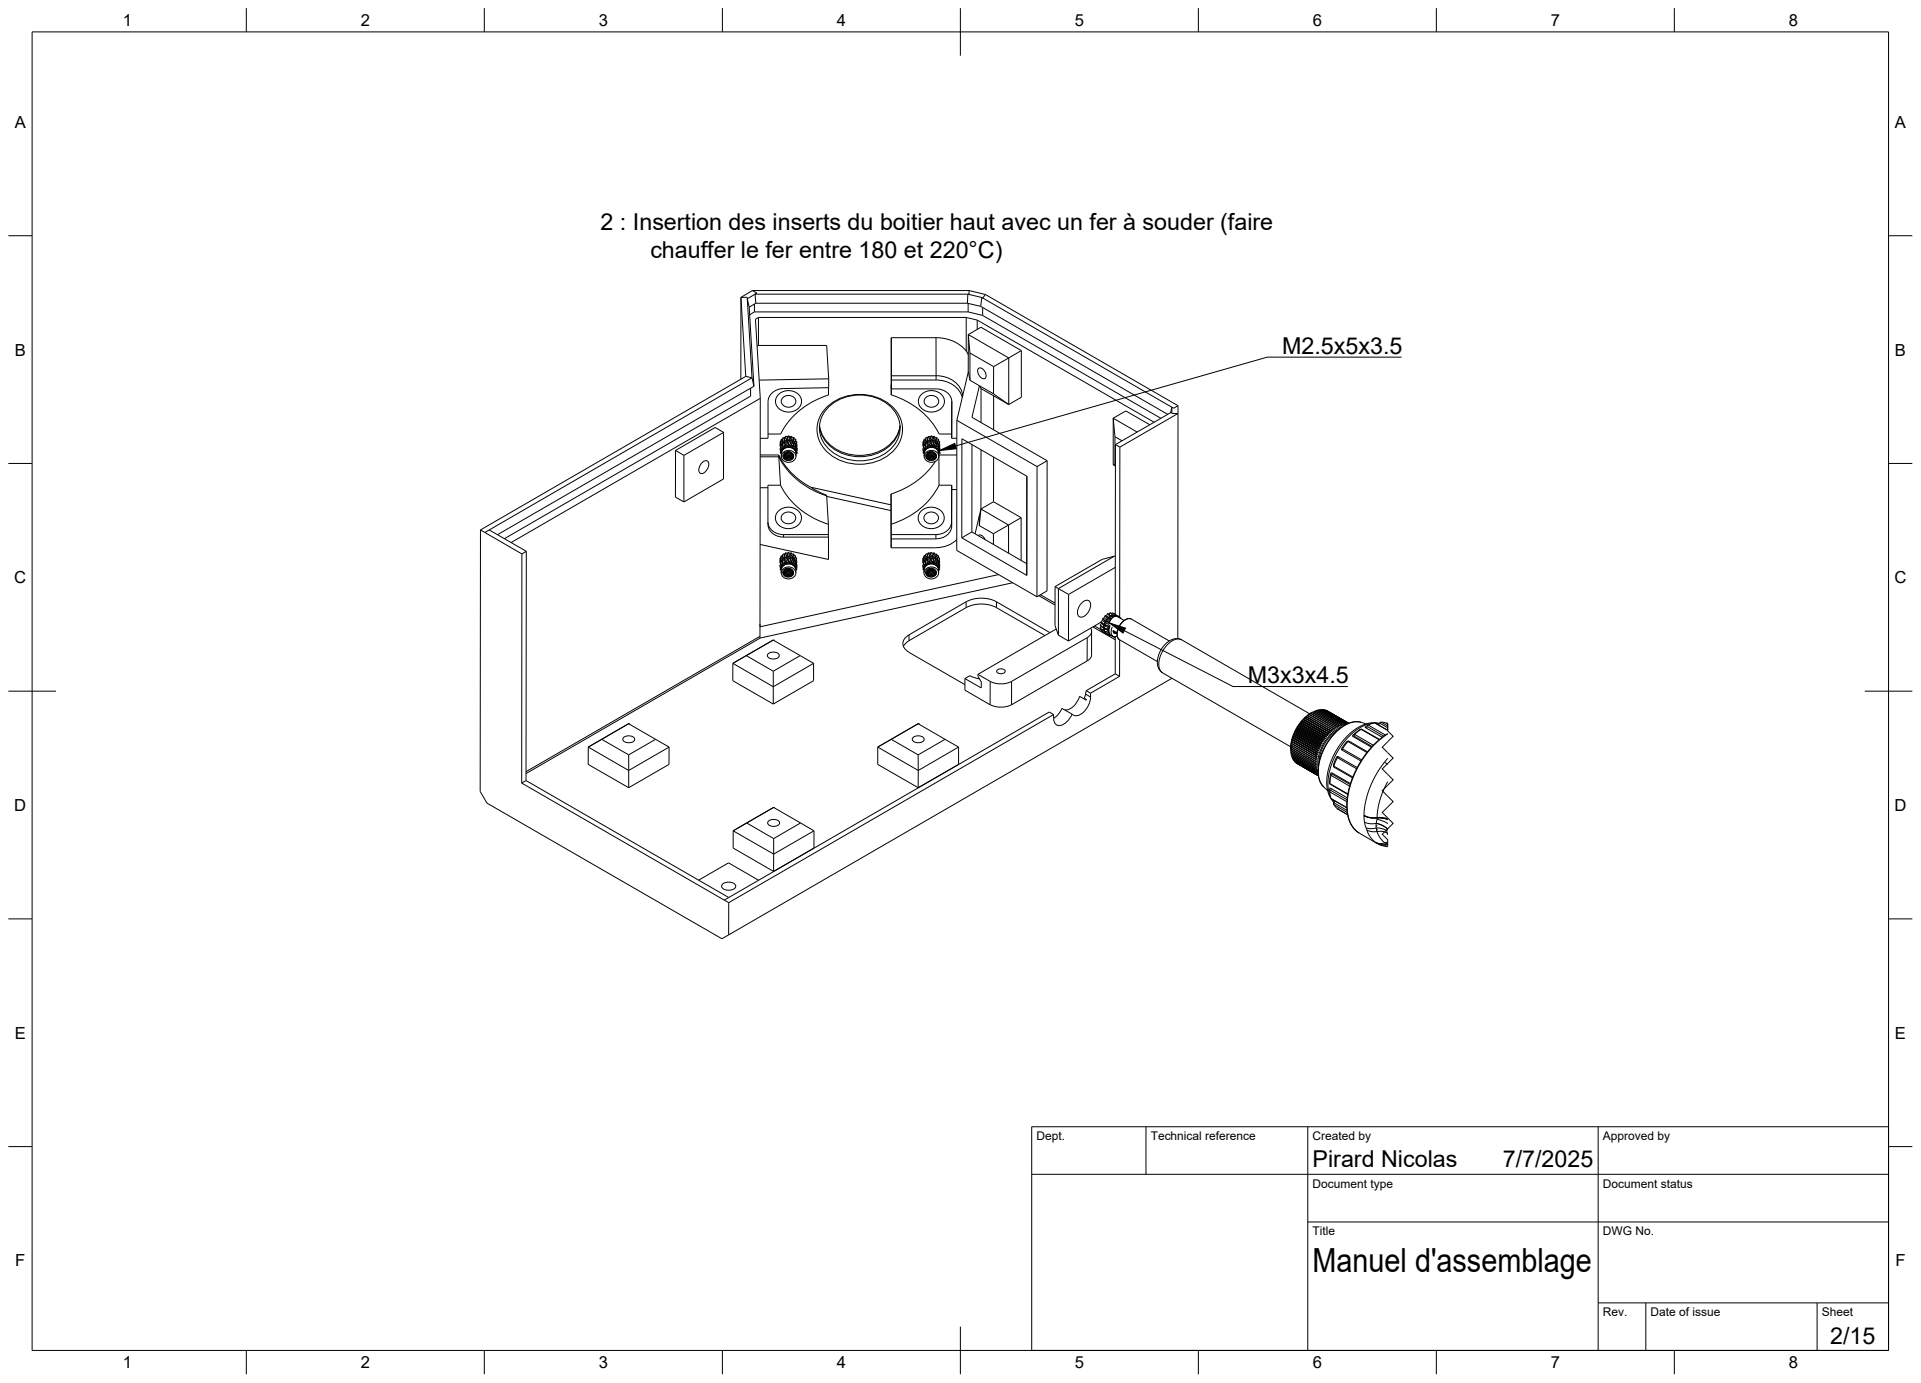
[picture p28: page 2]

2 : Insertion des inserts du boitier haut avec un fer à souder (faire
chauffer le fer entre 180 et 220°C)

Dept. | Technical reference | Created by Pirard Nicolas 7/7/2025 | Approved by

Document type | Document status

Title Manuel d'assemblage | DWG No.

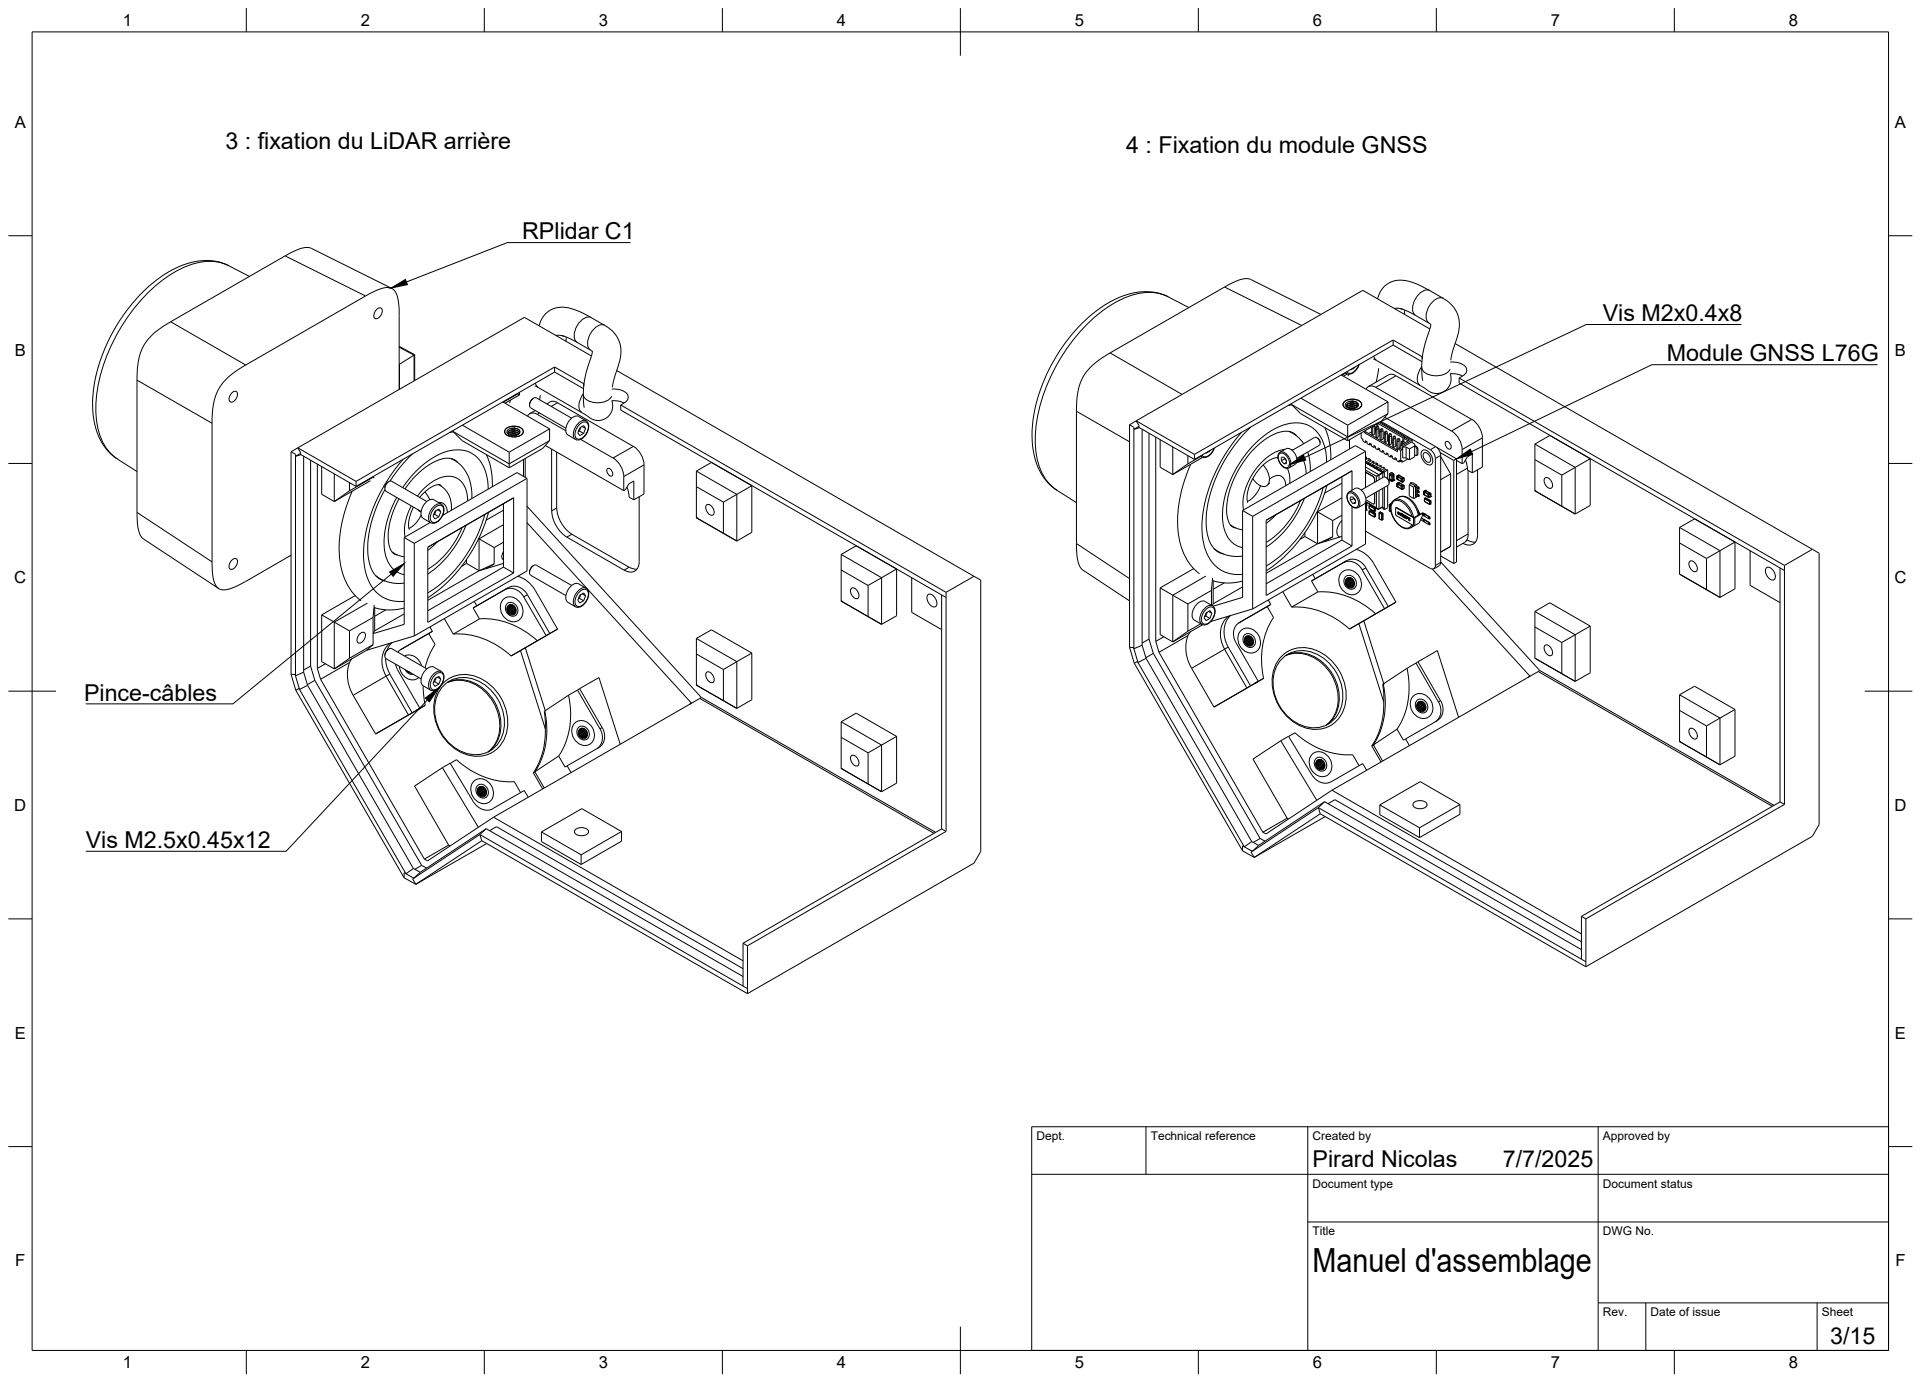
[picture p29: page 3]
RPlidar C1; Vis M2.5x0.45x12; Vis M2x0.4x8; Module GNSS L76G

3 : fixation du LiDAR arrière

4 : Fixation du module GNSS

Dept. | Technical reference | Created by Pirard Nicolas 7/7/2025 | Approved by

Document type | Document status

Title Manuel d'assemblage | DWG No.

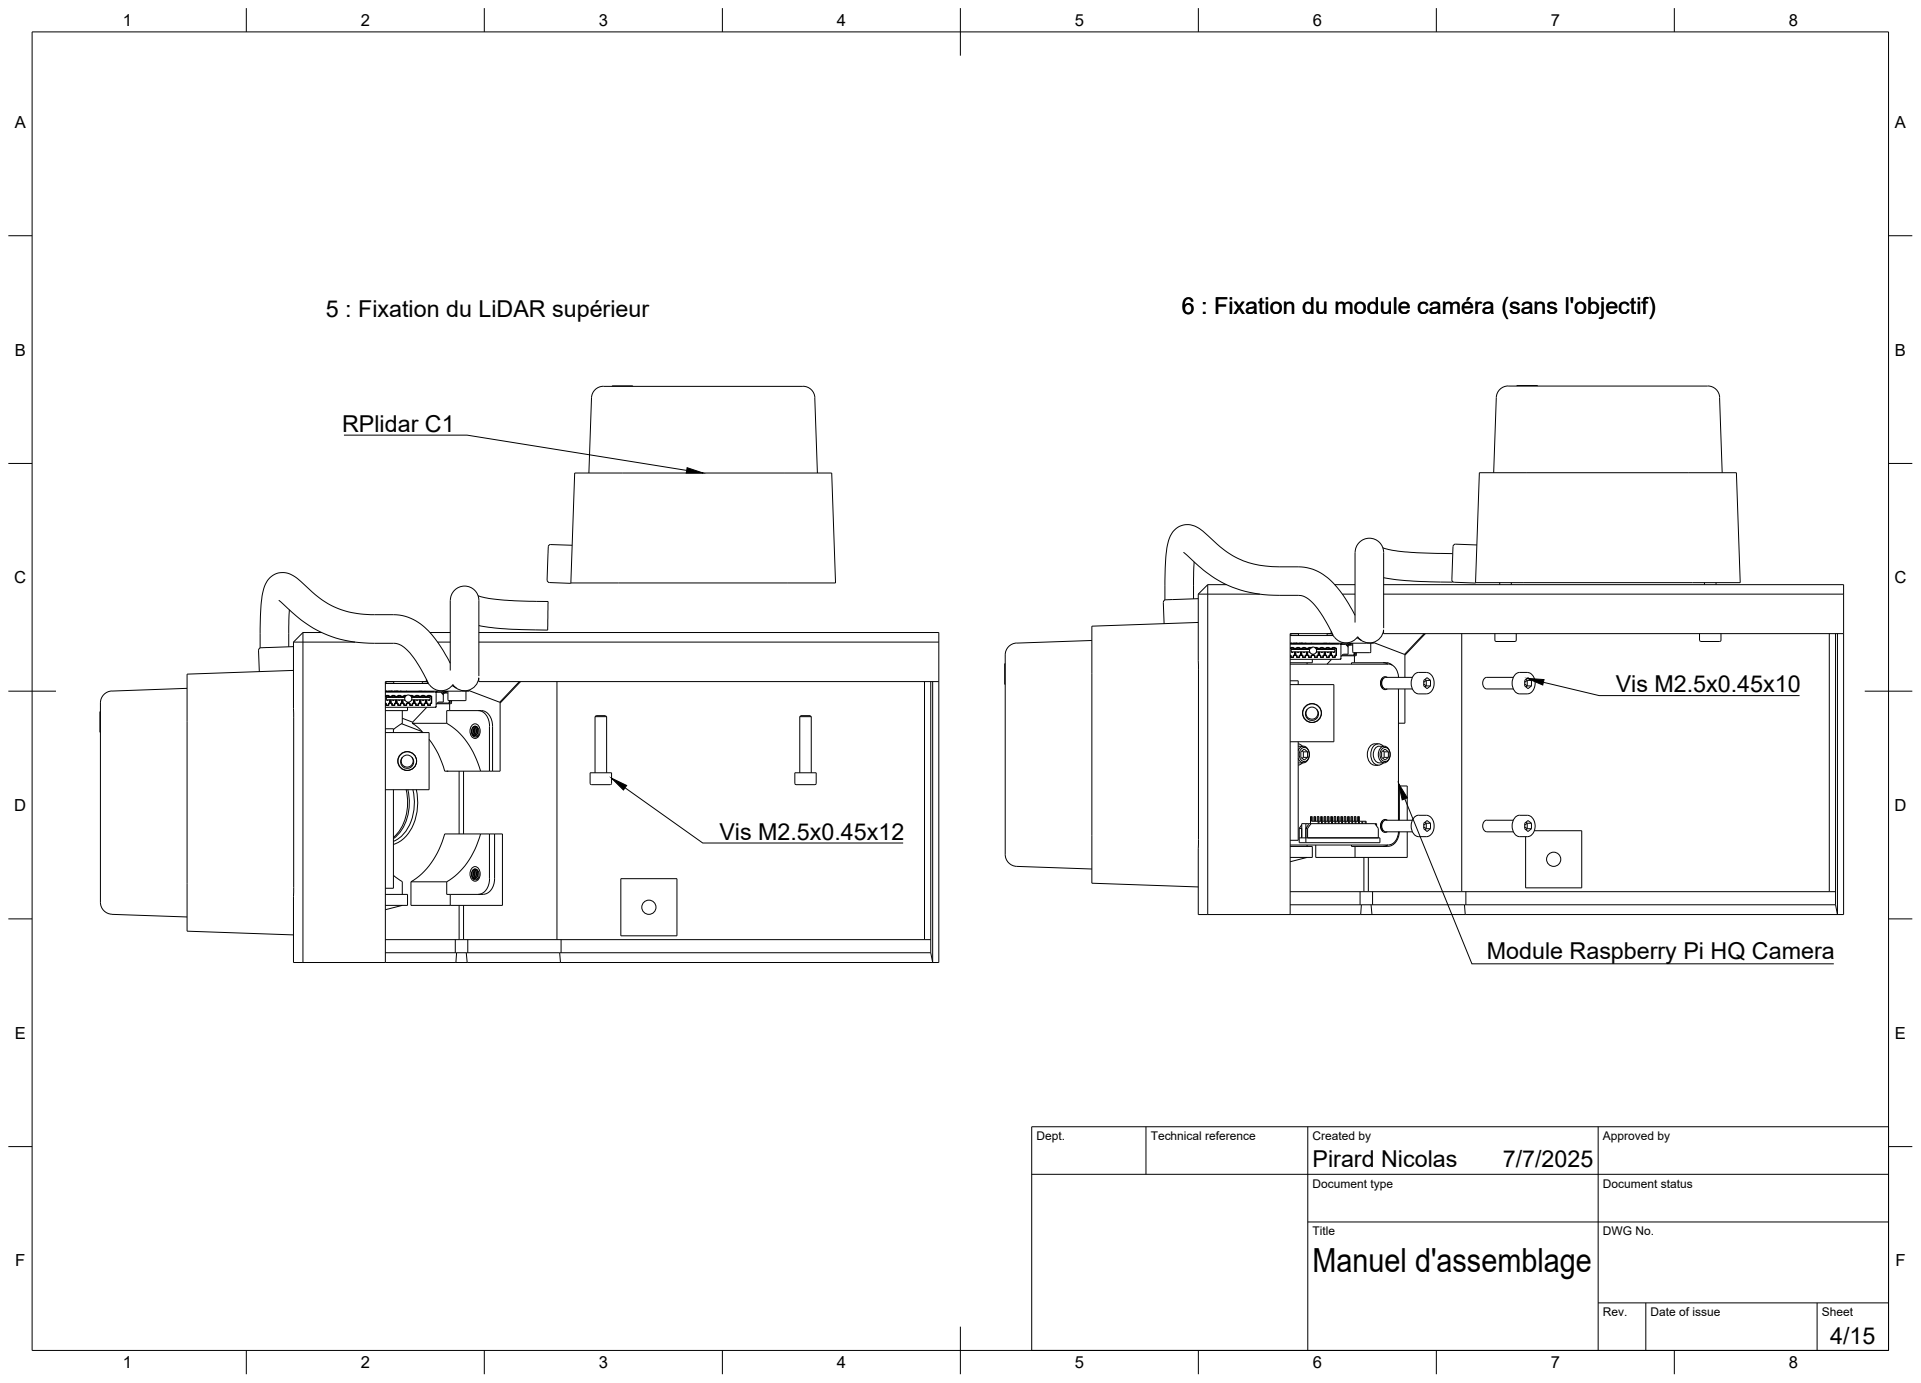
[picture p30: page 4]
RPlidar C1; Vis M2.5x0.45x12; Vis M2.5x0.45x10

6 : Fixation du module caméra (sans l'objectif)

5 : Fixation du LiDAR supérieur

Module Raspberry Pi HQ Camera

Dept. | Technical reference | Created by Pirard Nicolas 7/7/2025 | Approved by

Document type | Document status

Title Manuel d'assemblage | DWG No.

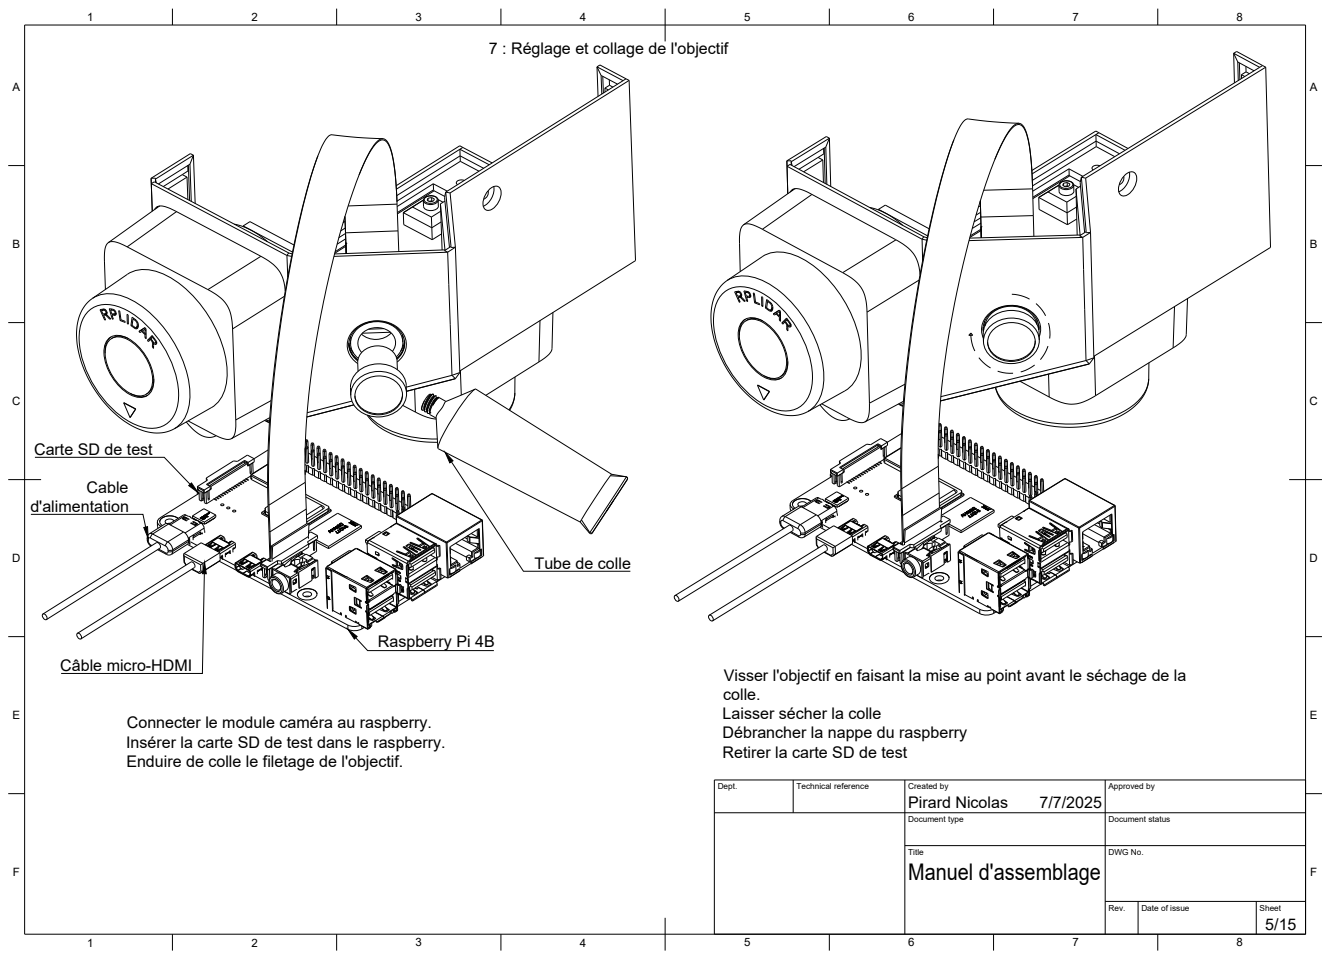
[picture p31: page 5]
Dept.; Technical reference; Created by; Approved by; Document type; Document status; Title; DWG No.; Manuel d'assemblage; Pirard Nicolas; Raspberry Pi 4B

7 : Réglage et collage de l'objectif

Carte SD de test

Tube de colle

Câble micro-HDMI

Visser l'objectif en faisant la mise au point avant le séchage de la
colle.
Laisser sécher la colle
Débrancher la nappe du raspberry
Retirer la carte SD de test

Connecter le module caméra au raspberry.
Insérer la carte SD de test dans le raspberry.
Enduire de colle le filetage de l'objectif.

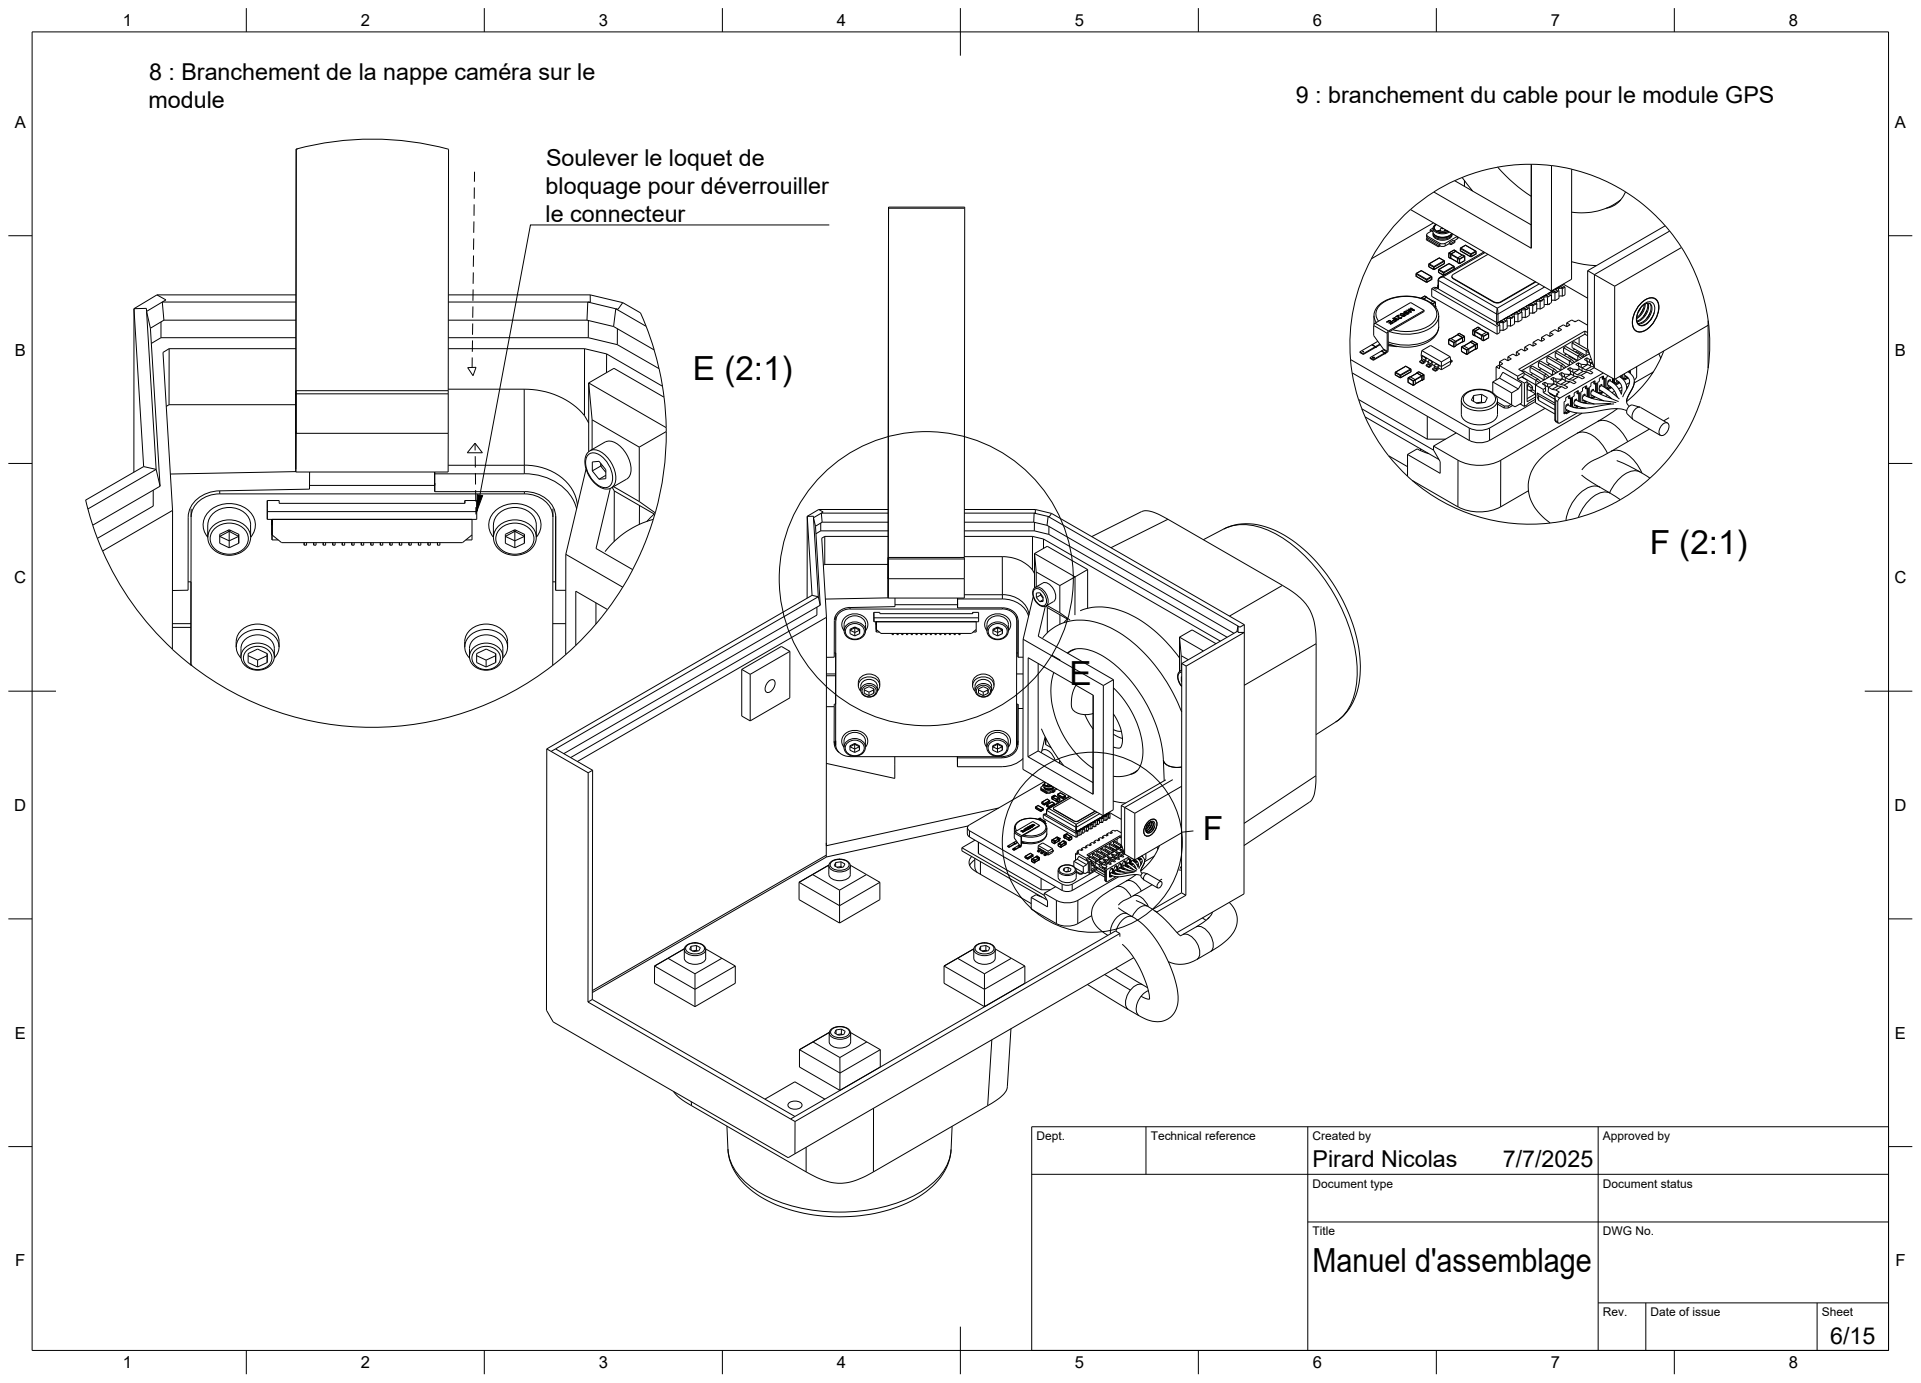
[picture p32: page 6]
module; 9 : branchement du cable pour le module GPS

8 : Branchement de la nappe caméra sur le

Soulever le loquet de
bloquage pour déverrouiller
le connecteur

Dept. | Technical reference | Created by Pirard Nicolas 7/7/2025 | Approved by

Document type | Document status

Title Manuel d'assemblage | DWG No.

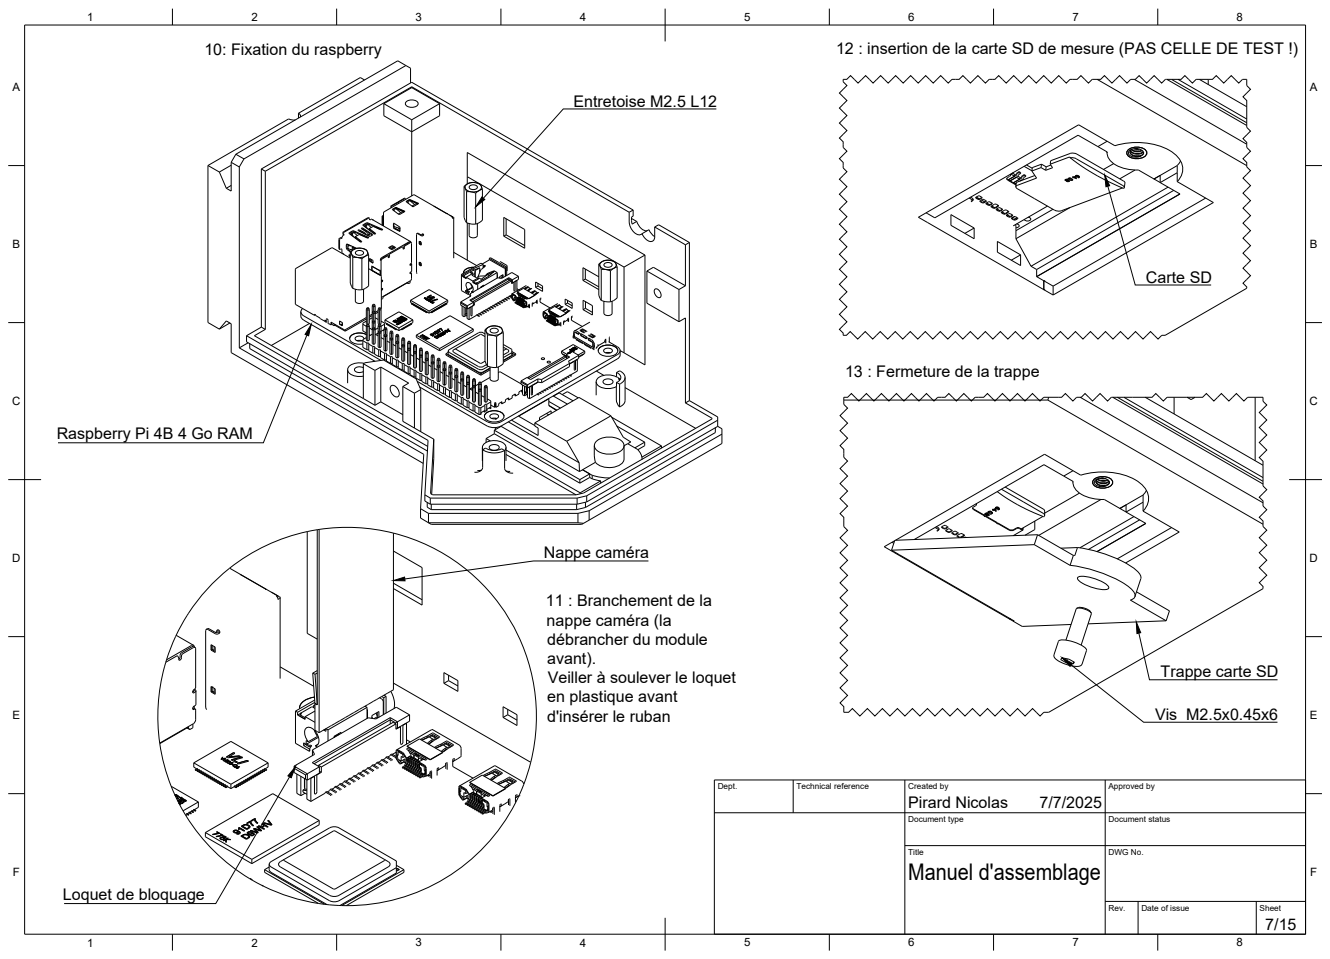
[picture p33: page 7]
Dept.; Technical reference; Created by; Approved by; Document type; Document status; Title; DWG No.; Manuel d'assemblage; Pirard Nicolas; 10: Fixation du raspberry; 12 : insertion de la carte SD de mesure (PAS CELLE DE TEST !); Entretoise M2.5 L12; Carte SD; Vis M2.5x0.45x6; Nappe caméra

13 : Fermeture de la trappe

Raspberry Pi 4B 4 Go RAM

11 : Branchement de la
nappe caméra (la
débrancher du module
avant).
Veiller à soulever le loquet
en plastique avant
d'insérer le ruban

Trappe carte SD

Loquet de bloquage

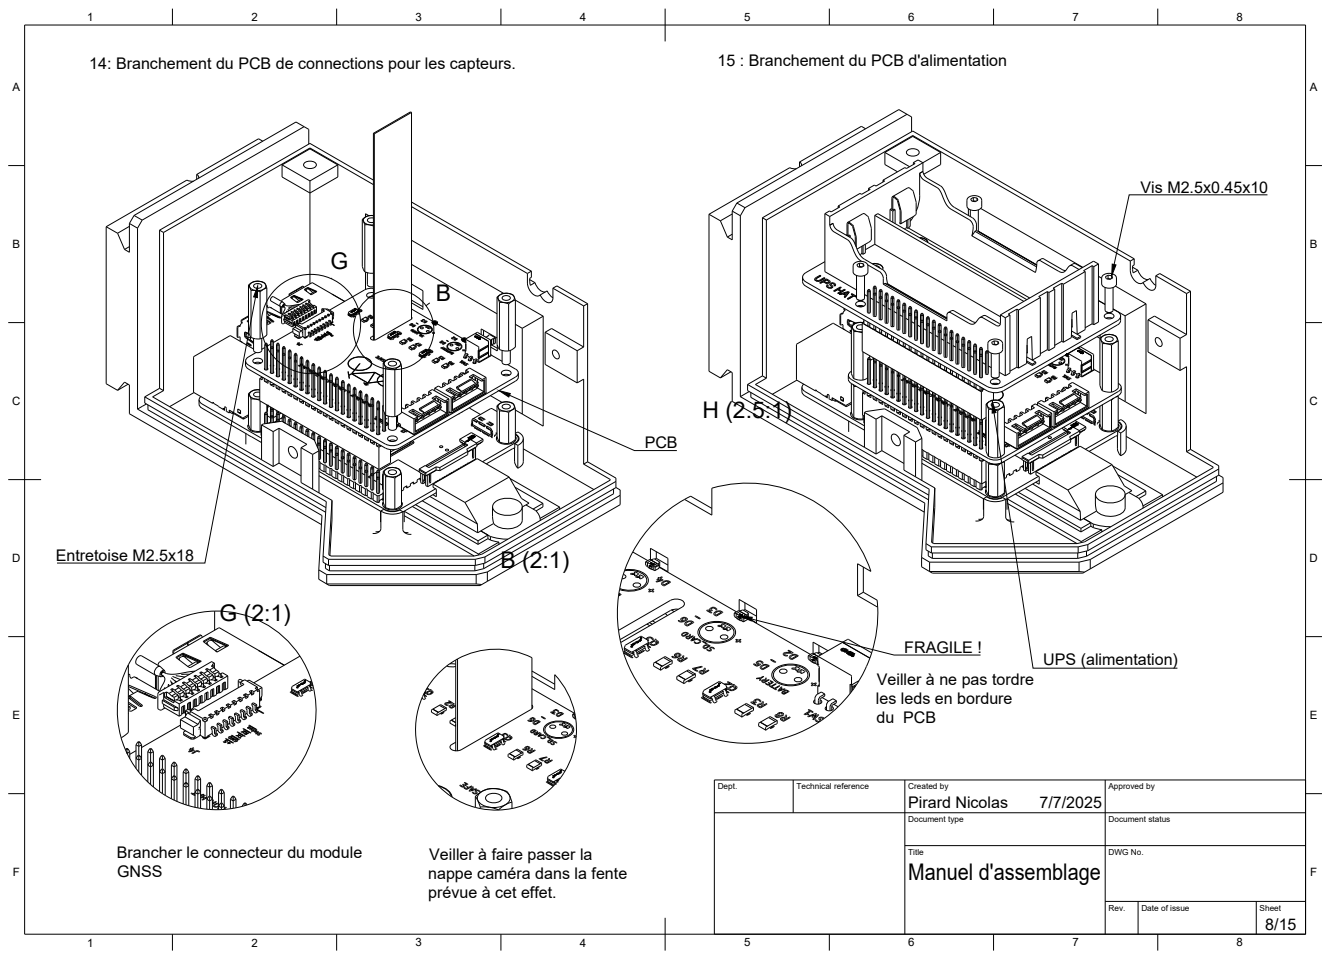
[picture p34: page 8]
Dept.; Technical reference; Created by; Approved by; Document type; Document status; Title; DWG No.; Manuel d'assemblage; Pirard Nicolas; 14: Branchement du PCB de connections pour les capteurs.; 15 : Branchement du PCB d'alimentation; Entretoise M2.5x18; UPS (alimentation); Vis M2.5x0.45x10; FRAGILE !

Veiller à ne pas tordre
les leds en bordure
du PCB

Brancher le connecteur du module
GNSS

Veiller à faire passer la
nappe caméra dans la fente
prévue à cet effet.

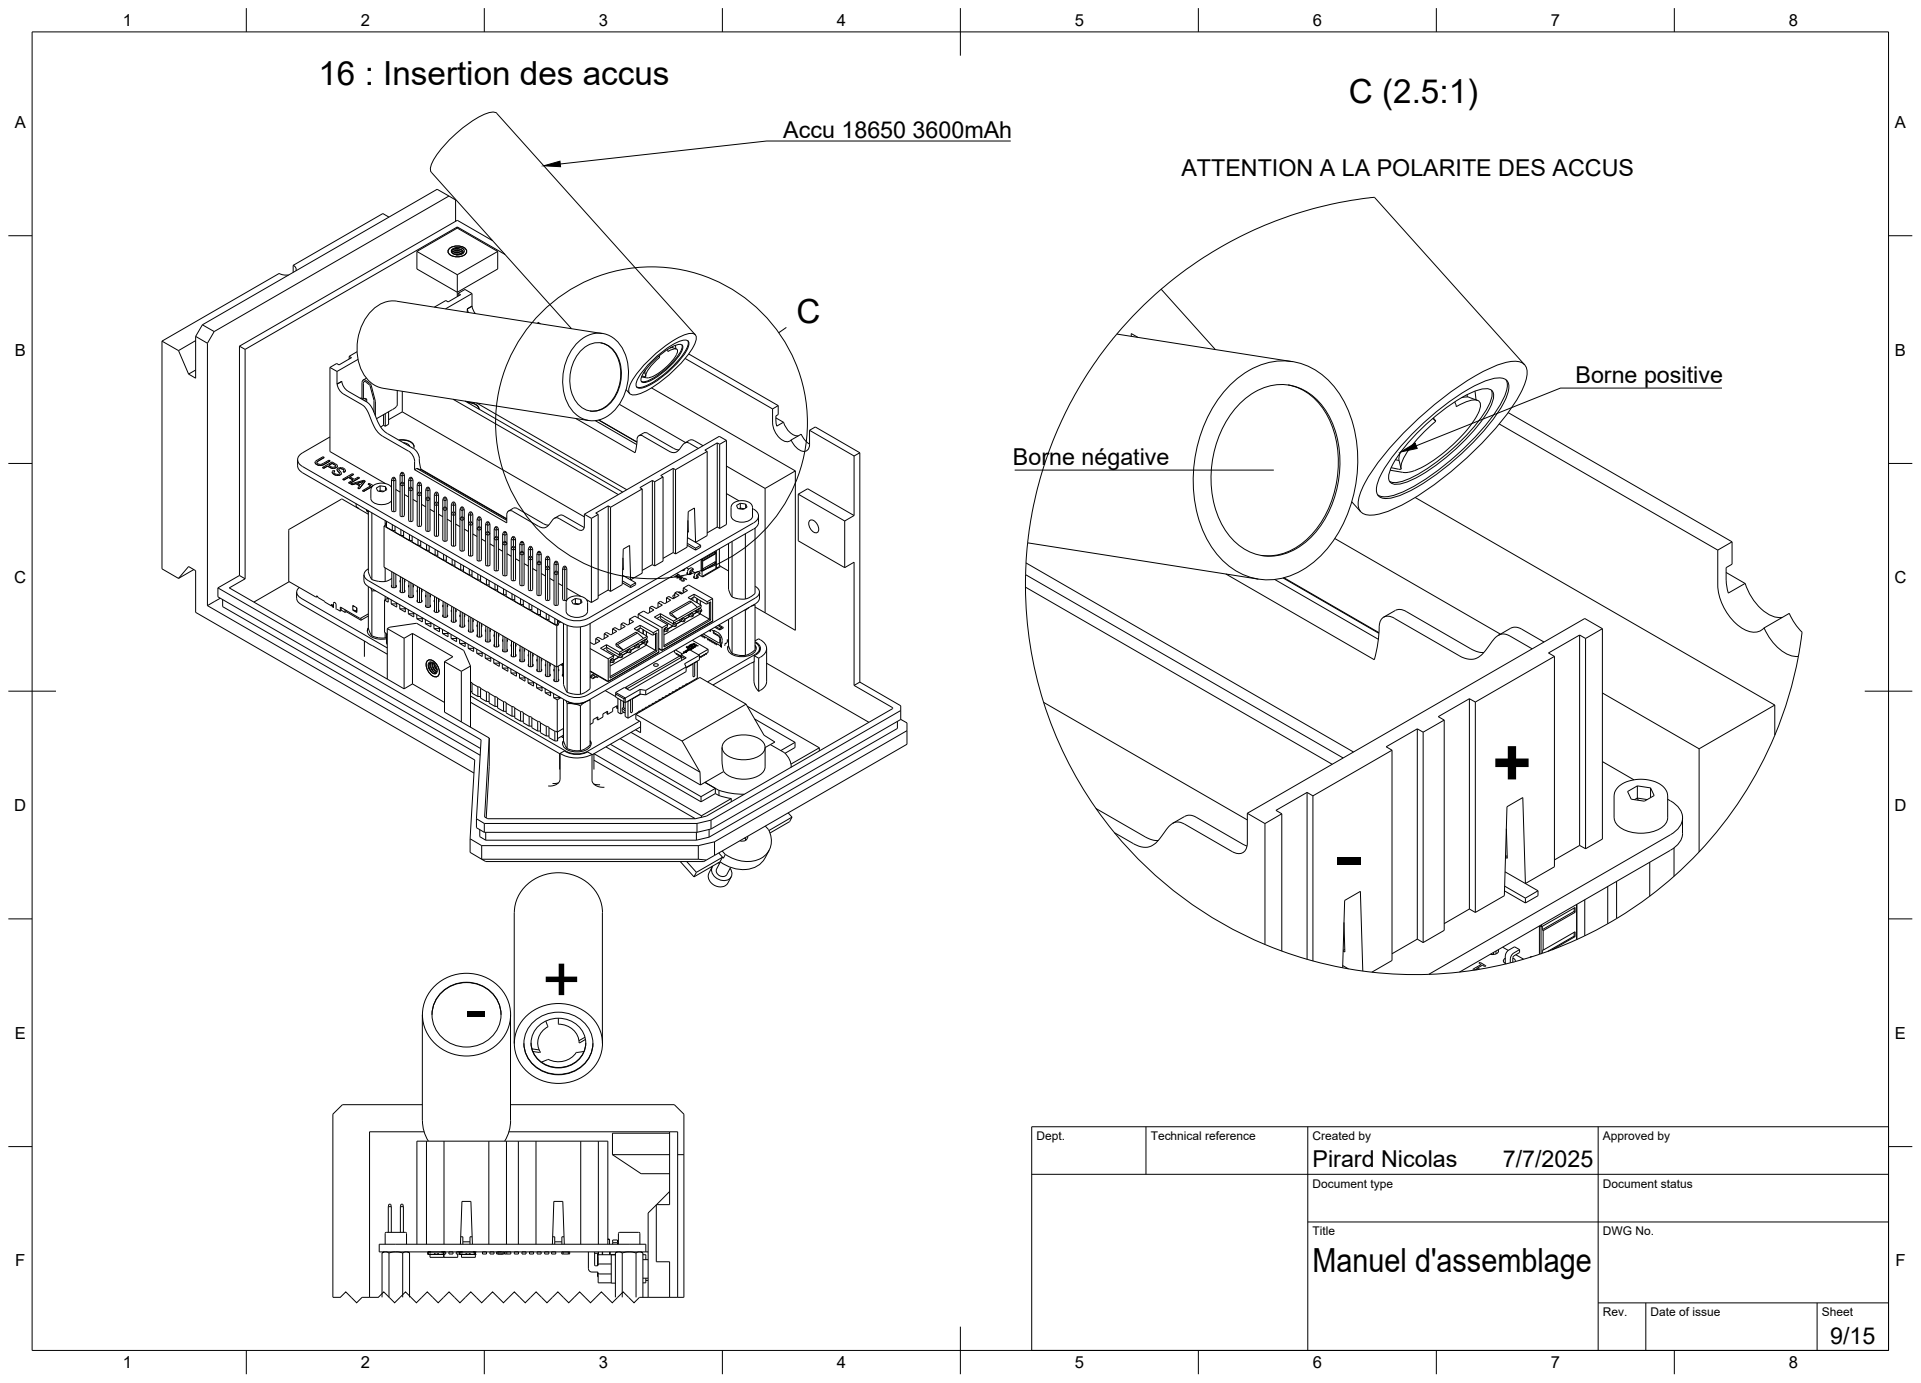
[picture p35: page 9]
Borne négative; Borne positive; Accu 18650 3600mAh

16 : Insertion des accus

ATTENTION A LA POLARITE DES ACCUS

Dept. | Technical reference | Created by Pirard Nicolas 7/7/2025 | Approved by

Document type | Document status

Title Manuel d'assemblage | DWG No.

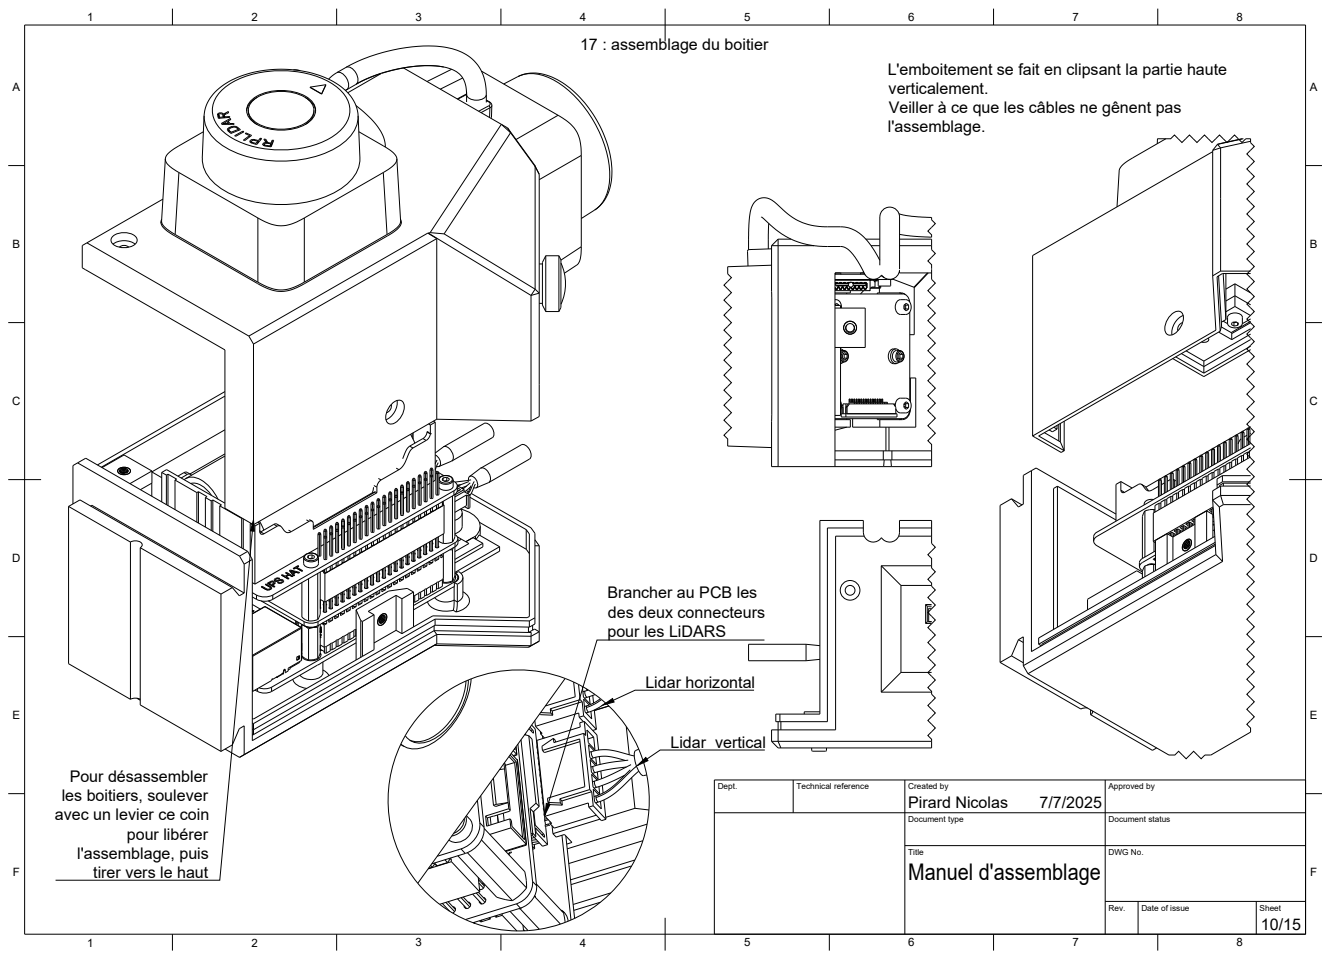
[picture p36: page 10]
pour libérer; Lidar vertical; Lidar horizontal

17 : assemblage du boitier

L'emboitement se fait en clipsant la partie haute
verticalement.
Veiller à ce que les câbles ne gênent pas
l'assemblage.

Brancher au PCB les
des deux connecteurs
pour les LiDARS

Pour désassembler
les boitiers, soulever
avec un levier ce coin

Dept. | Technical reference | Created by Pirard Nicolas 7/7/2025 | Approved by

Document type | Document status

l'assemblage, puis
tirer vers le haut

Title Manuel d'assemblage | DWG No.

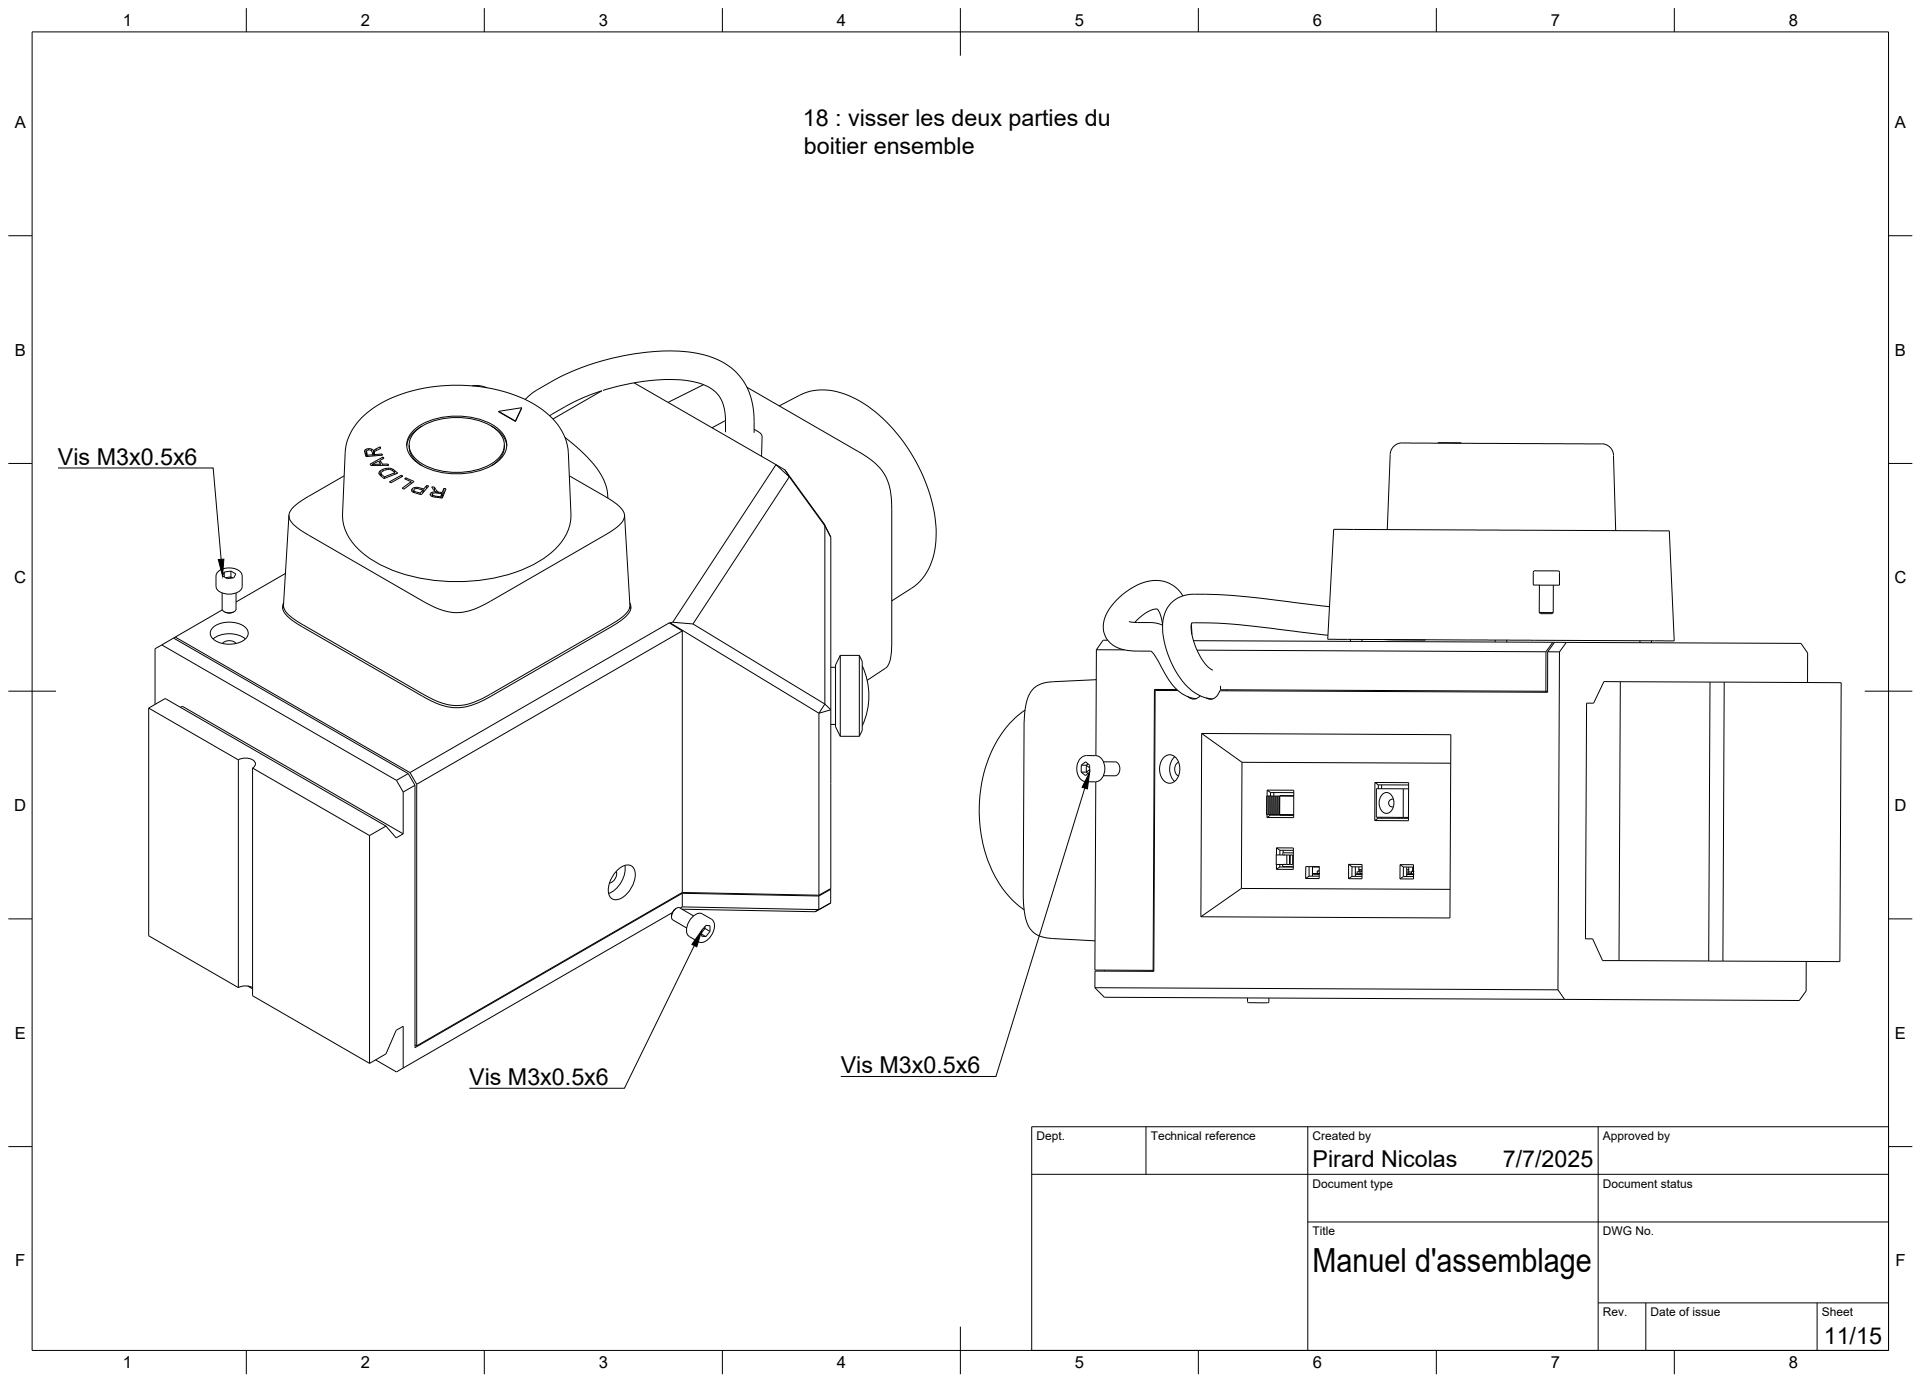
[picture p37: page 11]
Vis M3x0.5x6

18 : visser les deux parties du
boitier ensemble

Dept. | Technical reference | Created by Pirard Nicolas 7/7/2025 | Approved by

Document type | Document status

Title Manuel d'assemblage | DWG No.

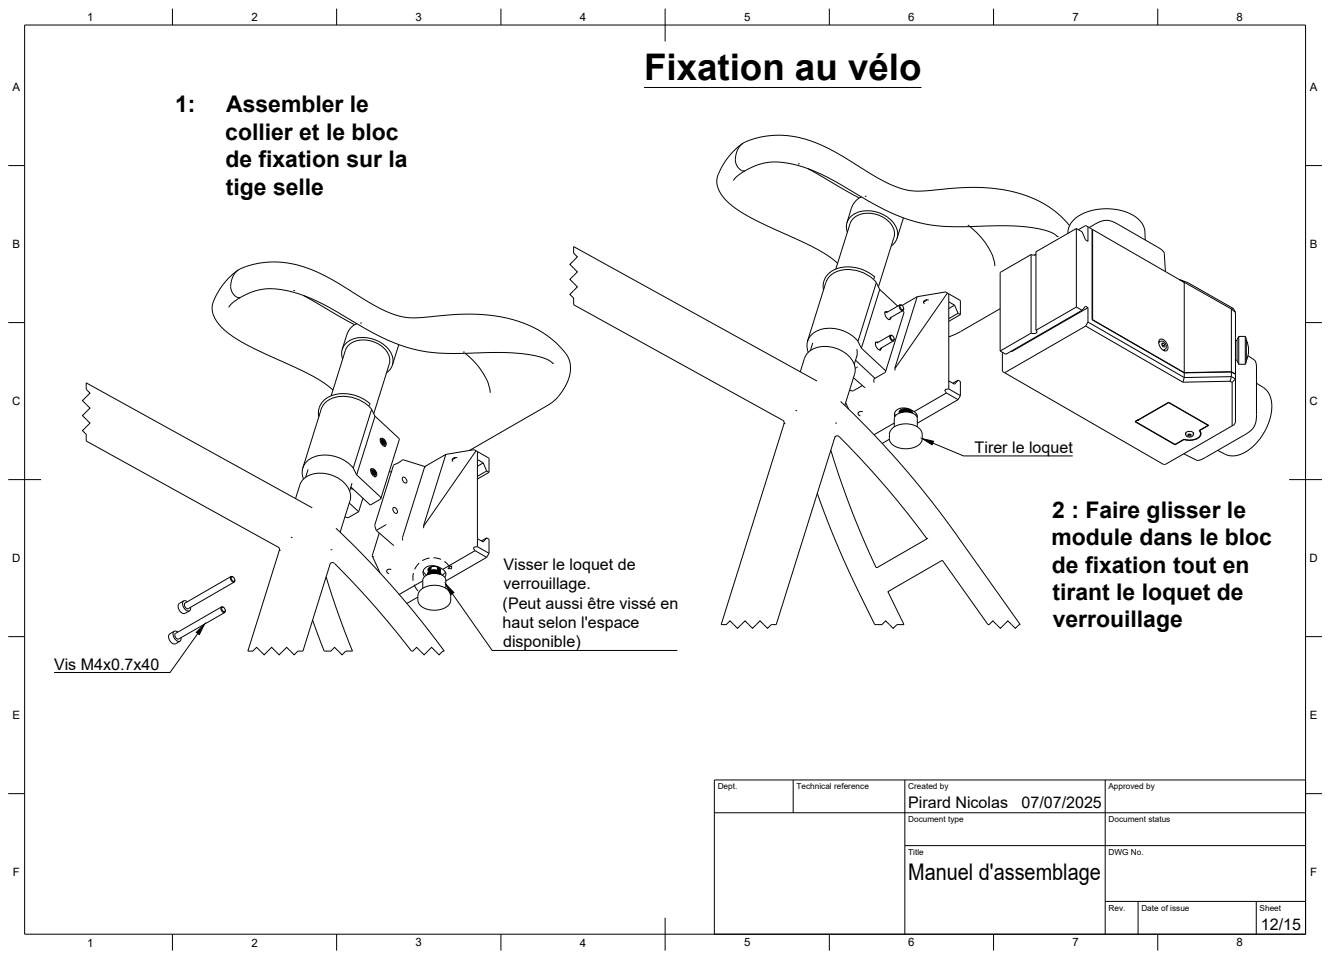
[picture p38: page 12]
Assembler le; Vis M4x0.7x40

Fixation au vélo

collier et le bloc
de fixation sur la
tige selle

Tirer le loquet

2 : Faire glisser le
module dans le bloc
de fixation tout en
tirant le loquet de
verrouillage
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

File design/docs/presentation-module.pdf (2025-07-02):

Title; DWG No.; Rev.; Date of issue; Sheet; LiDAR arrière; LiDAR supérieur

Trappe de la carte SD

Dept. IGN | Technical reference | Created by Pirard Nicolas 7/1/2025 | Approved by

Document type | Document status

Cyclosafe
Module de mesure

Title; DWG No.; Rondelle+écrou M4

Liste des pièces

Quantité | Nom | Matière
1 | Collier de fixation tige selle | PTEG
1 | Assemblage femelle | PTEG
1 | Pin de verrouillage | PTEG
1 | Ficelle de maintien du pin de verrouillage | Synthétique

2 | Vis M4xL40 | Acier
1 | Vis M3xL40 | Acier
1 | Insert M4x8x6 | Laiton

Passage pour une ficelle

Pin de verrouillage

Insert en laiton M4x8x6

Dept. IGN | Technical reference | Created by Pirard Nicolas 7/1/2025 | Approved by

Document type | Document status

Collier de fixation sur la tige selle

Cyclosafe
Fixation tige selle

Title; DWG No.

Switch d'alimentation On/Off

Port d'alimentation pour la recharge

Voyant état (jaune)
Avec clignotement : mesures en cours
Sans clignotement : démarrage/arrêt en cours

Voyant carte SD (bleu)
Si allumé : carte SD pleine

Bouton poussoir d'extinction

Dept. IGN | Technical reference | Created by Pirard Nicolas 01/07/2025 | Approved by

Voyant batterie (rouge)

Si allumé : moins de 20% restant

Document type | Document status

Title; DWG No.; Vis M3xL6; Acier

Dept. IGN | Technical reference | Created by Pirard Nicolas 7/1/2025 | Approved by

Document type | Document status

Cyclosafe
Assemblage des boitiers

Title; DWG No.; Boitier supérieur; L76G GNSS module; M2xL8 (insert M2x5x3.5); M2.5xL12 (pas d'insert); M2.5xL10 (insert M2.5x5x3.5); Insert M3x3x4.5

1 | Boitier haut | PTEG
2 | Slamtec lidar C1 | Plastique
1 | L76G GNSS module | Mixte
8 | Vis M2.5xL12 | Acier
4 | Vis M2.5xL10 | Acier
2 | Vis M2xL8 | Acier
1 | Raspberry HQ Camera | Acier
1 | Insert M3x3x4.5 | Laiton
4 | Insert M2.5x5x3.5 | Laiton
2 | Insert M2x5x3.5 | Laiton

Dept. IGN | Technical reference | Created by Pirard Nicolas 7/1/2025 | Approved by

Document type | Document status

Dept.; Technical reference; Created by; Approved by; Document type; Document status; Title; DWG No.; Boitier inférieur; IGN; Pirard Nicolas; Boitier bas; PTEG; Couvercle trappe carte SD; Raspberry Pi 4B; Mixte; Custom cyclosafe PCB; Waveshare UPS hat; Accu 18650 3600mAh; Vis M2.5xL10; Acier; Entretoise M2.5xL12; Entretoise M2.5xL15; Insert M2.5x4x3.5; Laiton; Insert M3x3x4.5; Insert M3x4x4.5; Insert M2.5x5x3.5; PCB custom; Accu 18650; Vis M2.5xL6

Waveshare UPS hat

Couvercle trappe carte SD

Trappe carte SD

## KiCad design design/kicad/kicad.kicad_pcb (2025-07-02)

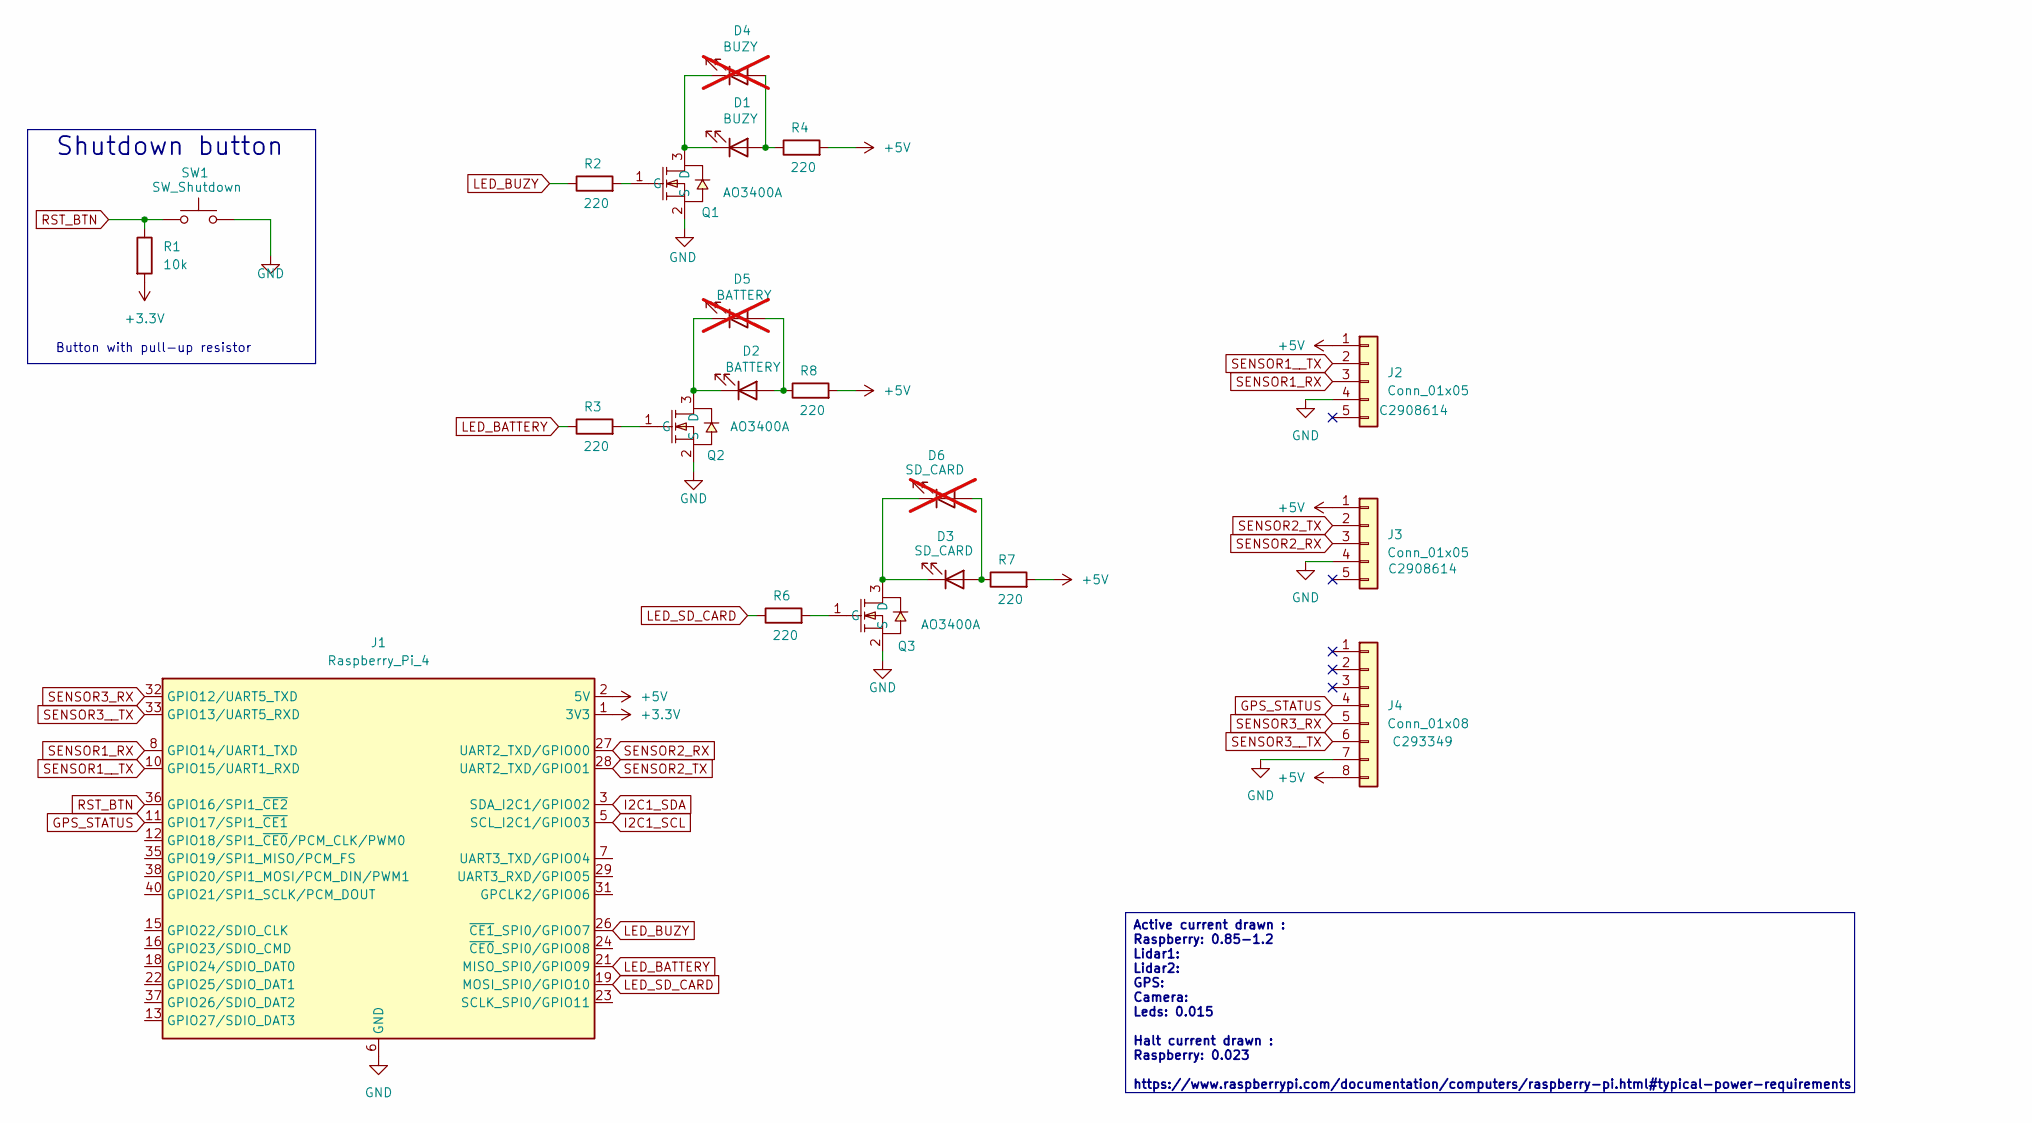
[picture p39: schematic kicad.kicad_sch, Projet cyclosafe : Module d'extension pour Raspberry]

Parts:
D1: BUZY; LED-SMD_L1.7-W0.6-RD-custom; LCSC Part C133119
D2: BATTERY; LED-SMD_L1.7-W0.6-RD-custom; LCSC Part C125114
D3: SD_CARD; LED-SMD_L1.7-W0.6-RD-custom; LCSC Part C125115
D4: BUZY; LED-TH_BD3.9-P2.54-FD; LCSC Part C133119; not fitted
D5: BATTERY; LED-TH_BD3.9-P2.54-FD; LCSC Part C125114; not fitted
D6: SD_CARD; LED-TH_BD3.9-P2.54-FD; LCSC Part C125115; not fitted
J1: Raspberry_Pi_4; HDR-TH_40P-P2.54-V-F-R2-C20-S2.54-2-reveresed; LCSC Part C35165
J2, J3: Conn_01x05; CONN-TH_WAFER-HA254WZ-5A; LCSC Part C2908614
J4: Conn_01x08; Molex_PicoBlade_53261-0871_1x08-1MP_P1.25mm_Horizontal; LCSC Part C293349
Q1, Q2, Q3: AO3400A; SOT-23-3_L2.9-W1.3-P1.90-LS2.4-BR; LCSC Part C20917
R1: 10k; R_0805_2012Metric; LCSC Part C17414
R2, R3, R4, R6, R7, R8: 220; R_0805_2012Metric; LCSC Part C17557
SW1: SW_Shutdown; SW-TH_TK-6580B-2; LCSC Part C2689830

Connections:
+3.3V: J1.1 (3V3), J1.17 (3V3), R1.2
+5V: J1.2 (5V), J1.4 (5V), J2.1, J3.1, J4.8, R4.2, R7.2, R8.2
GND: J1.6 (GND), J1.9 (GND), J1.14 (GND), J1.20 (GND), J1.25 (GND), J1.30 (GND), J1.34 (GND), J1.39 (GND), J2.4, J3.4, J4.7, Q1.2 (S), Q2.2 (S), Q3.2 (S), SW1.2
GPS_STATUS: J1.11 (GPIO17/SPI1_~CE1), J4.4
I2C1_SCL: J1.5 (SCL_I2C1/GPIO03)
I2C1_SDA: J1.3 (SDA_I2C1/GPIO02)
LED_BATTERY: J1.21 (MISO_SPI0/GPIO09), R3.1
LED_BUZY: J1.26 (~CE1_SPI0/GPIO07), R2.1
LED_SD_CARD: J1.19 (MOSI_SPI0/GPIO10), R6.1
unnamed: D1.2 (A), D4.2 (A), R4.1
unnamed: D1.1 (K), D4.1 (K), Q1.3 (D)
unnamed: D2.2 (A), D5.2 (A), R8.1
unnamed: D2.1 (K), D5.1 (K), Q2.3 (D)
unnamed: D3.2 (A), D6.2 (A), R7.1
unnamed: D3.1 (K), D6.1 (K), Q3.3 (D)
unnamed: Q1.1 (G), R2.2
unnamed: Q2.1 (G), R3.2
unnamed: Q3.1 (G), R6.2
RST_BTN: J1.36 (GPIO16/SPI1_~CE2), R1.1, SW1.1
SENSOR1_RX: J1.8 (GPIO14/UART1_TXD), J2.3
SENSOR1__TX: J1.10 (GPIO15/UART1_RXD), J2.2
SENSOR2_RX: J1.27 (UART2_TXD/GPIO00), J3.3
SENSOR2_TX: J1.28 (UART2_TXD/GPIO01), J3.2
SENSOR3_RX: J1.32 (GPIO12/UART5_TXD), J4.5
SENSOR3__TX: J1.33 (GPIO13/UART5_RXD), J4.6

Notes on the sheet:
Button with pull-up resistor
Shutdown button
Active current drawn : Raspberry: 0.85-1.2 Lidar1: Lidar2: GPS: Camera: Leds: 0.015 Halt current drawn : Raspberry: 0.023 https://www.raspberrypi.com/documentation/computers/raspberry-pi.html#typical-power-requirements

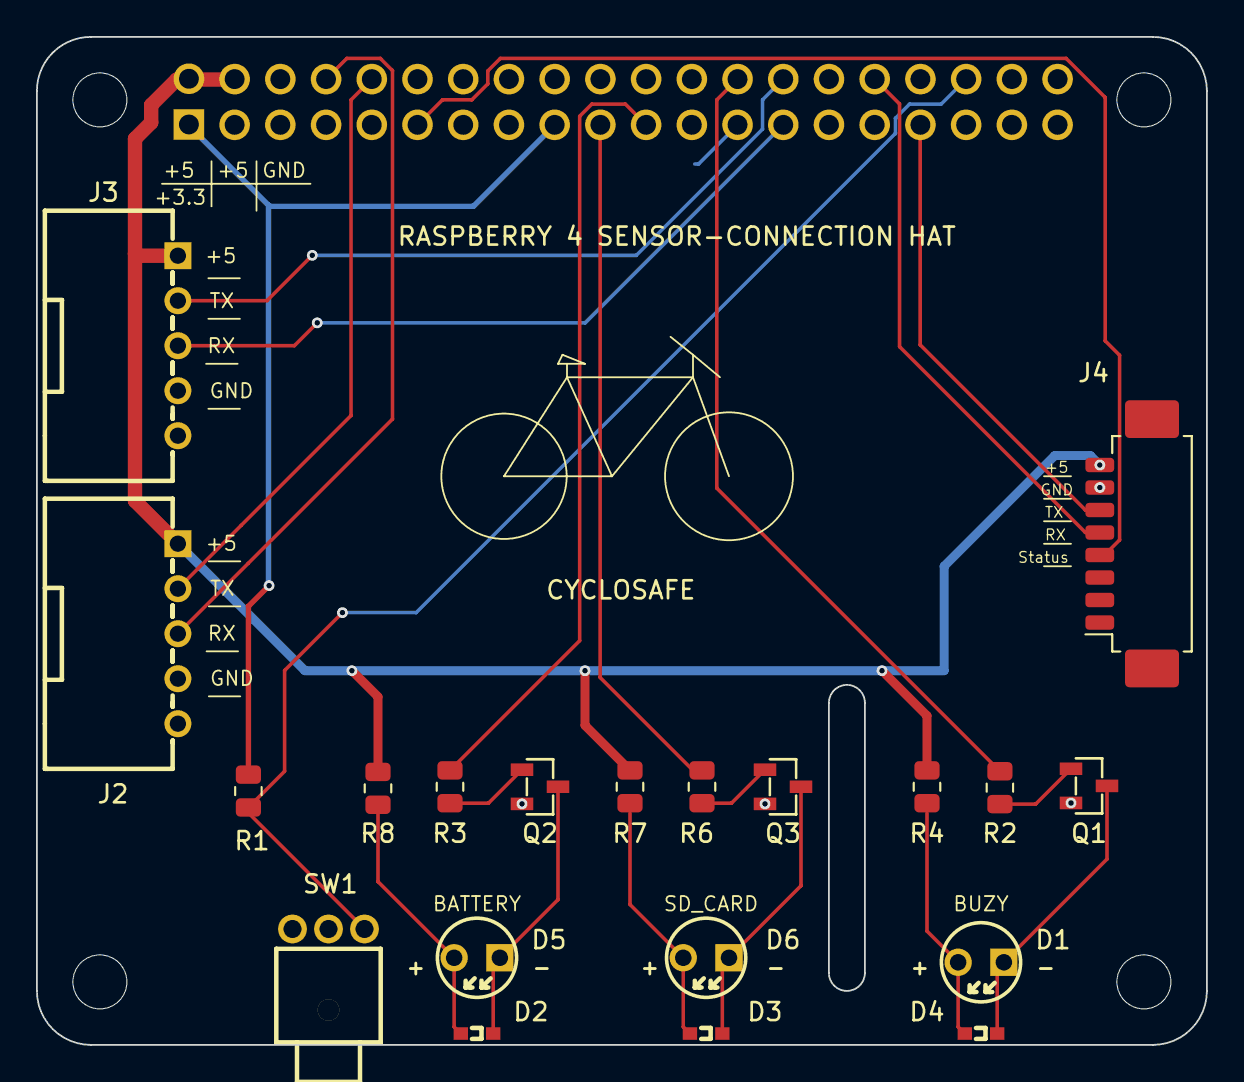
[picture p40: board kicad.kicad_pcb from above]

Board: 2 copper layers, 65.0 x 56.0 mm, 21 parts (1 on the bottom side), 23 nets.

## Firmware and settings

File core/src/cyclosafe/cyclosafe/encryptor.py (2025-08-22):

#!/usr/bin/env python3
# Created on Tue Aug 19 2025
# Updated on Tue Aug 19 2025
#
# This file is part of Cyclosafe
# Copyright (c) 2025 Nicolas Pirard @Anvently
#
# This software is governed by the CeCILL license under French law and
# abiding by the rules of distribution of free software. You can use,
# modify and/or redistribute the software under the terms of the CeCILL
# license as circulated by CEA, CNRS and INRIA at:
# https://cecill.info/licences/Licence_CeCILL-B_V1-en.html

import os
import time
from pathlib import Path
from watchdog.observers import Observer
from watchdog.events import FileSystemEventHandler
from cryptography.hazmat.primitives import hashes, serialization
from cryptography.hazmat.primitives.asymmetric import padding
from cryptography.hazmat.primitives.ciphers import Cipher, algorithms, modes
import secrets
import json
import zstandard as zstd
import rclpy
from rclpy.node import Node
from rclpy.executors import ExternalShutdownException
import threading

"""
Simplified ROS2 node: monitors a directory and encrypts/compresses new bag files.
- Removed all publishers, services, and diagnostics
- Keeps graceful shutdown with final processing
"""


class ROSBagCryptoHandler(FileSystemEventHandler):
	"""Event handler to monitor and encrypt ROS bag files"""

	def __init__(self, public_key_path: str, watch_dir: str, ros_node: Node):
		self.ros_node = ros_node  # set first; used by _load_public_key
		self.public_key = self._load_public_key(public_key_path)
		self.watch_dir = Path(watch_dir)

		# File types to watch
		self.bag_extensions = {'.db3', '.bag', '.mcap'}

		# Track files currently being processed (to avoid duplicates)
		self.processing_files = set()

		# Shutdown flag
		self.shutdown_requested = False

		# Stats (internal only)
		self.stats = {
			'files_encrypted': 0,
			'files_failed': 0,
			'total_bytes_processed': 0,
			'start_time': time.time(),
		}

	def request_shutdown(self):
		self.shutdown_requested = True
		self.ros_node.get_logger().info("Shutdown requested, will process remaining files…")

	def _load_public_key(self, public_key_path: str):
		try:
			with open(public_key_path, 'rb') as key_file:
				public_key = serialization.load_pem_public_key(key_file.read())
			self.ros_node.get_logger().info("Public key successfully loaded")
			return public_key
		except Exception as e:
			self.ros_node.get_logger().error(f"Error while loading public key: {e}")
			raise

	def _is_bag_file(self, file_path: str) -> bool:
		return Path(file_path).suffix.lower() in self.bag_extensions

	def _is_file_complete(self, file_path: str, stability_time: float = 15) -> bool:
		"""Check if file size is stable for `stability_time` seconds."""
		try:
			size1 = os.path.getsize(file_path)
			time.sleep(stability_time)
			size2 = os.path.getsize(file_path)
			return size1 == size2 and size1 > 0
		except (OSError, FileNotFoundError):
			return False

	def _wait_for_file_stability(self, file_path: Path, max_wait_time: float = 30) -> bool:
		self.ros_node.get_logger().info(f"Waiting for file stability: {file_path}")
		start_time = time.time()
		while time.time() - start_time < max_wait_time:
			if self._is_file_complete(str(file_path), stability_time=3):
				self.ros_node.get_logger().info(f"File is stable: {file_path}")
				return True
			time.sleep(1)
		self.ros_node.get_logger().warning(f"File did not stabilize within {max_wait_time}s: {file_path}")
		return False

	def _find_unencrypted_bags(self):
		unencrypted_bags = []
		for file_path in self.watch_dir.rglob('*'):
			if (
				file_path.is_file()
				and self._is_bag_file(str(file_path))
				and not file_path.name.endswith('.enc')
			):
				unencrypted_bags.append(file_path)
		return unencrypted_bags

	def _secure_delete(self, file_path: Path) -> bool:
		try:
			os.remove(file_path)
			return True
		except Exception as e:
			self.ros_node.get_logger().warning(f"Unable to delete file: {e}")
			return False

	def _encrypt_file(self, file_path: str):
		"""Encrypt a file with hybrid RSA (OAEP) + AES-256-CBC with Zstandard compression."""
		file_path = Path(file_path)

		if file_path in self.processing_files:
			return
		self.processing_files.add(file_path)

		try:
			self.ros_node.get_logger().info(f"Starting encryption of: {file_path}")

			# Generate random AES key and IV
			aes_key = secrets.token_bytes(32)  # AES-256
			iv = secrets.token_bytes(16)

			# Encrypt AES key with RSA public key
			encrypted_aes_key = self.public_key.encrypt(
				aes_key,
				padding.OAEP(
					mgf=padding.MGF1(algorithm=hashes.SHA256()),
					algorithm=hashes.SHA256(),
					label=None,
				),
			)

			# Read and compress file
			with open(file_path, 'rb') as infile:
				data = infile.read()

			original_size = len(data)
			self.stats['total_bytes_processed'] += original_size

			cctx = zstd.ZstdCompressor(level=3)
			data = cctx.compress(data)
			self.ros_node.get_logger().info(
				f"File compressed: {len(data)} bytes (was {original_size} bytes)"
			)

			# AES-CBC encrypt with PKCS#7 padding
			cipher = Cipher(algorithms.AES(aes_key), modes.CBC(iv))
			encryptor = cipher.encryptor()
			pad_length = 16 - (len(data) % 16)
			padded_data = data + bytes([pad_length] * pad_length)
			encrypted_data = encryptor.update(padded_data) + encryptor.finalize()

			# Output file alongside input
			output_file = self.watch_dir / f"{file_path.name}.enc"

			metadata = {
				'original_name': file_path.name,
				'compression_method': 'zstd',
				'encryption_method': 'RSA-OAEP + AES-256-CBC',
				'key_length': len(encrypted_aes_key),
				'iv_length': len(iv),
				'timestamp': time.time(),
				'original_size': original_size,
				'compressed_size': len(data),
			}
			metadata_json = json.dumps(metadata).encode('utf-8')
			metadata_length = len(metadata_json).to_bytes(4, 'big')

			with open(output_file, 'wb') as outfile:
				outfile.write(metadata_length)
				outfile.write(metadata_json)
				outfile.write(encrypted_aes_key)
				outfile.write(iv)
				outfile.write(encrypted_data)

			self.ros_node.get_logger().info(f"Encrypted file saved: {output_file}")

			# Optionally delete the original file
			if self._secure_delete(file_path):
				self.ros_node.get_logger().info(f"Original file deleted: {file_path}")

			self.stats['files_encrypted'] += 1

		except Exception as e:
			self.ros_node.get_logger().error(f"Error while encrypting {file_path}: {e}")
			self.stats['files_failed'] += 1
		finally:
			self.processing_files.discard(file_path)

	# Watchdog hooks
	def on_created(self, event):
		if self.shutdown_requested:
			return
		if not event.is_directory and self._is_bag_file(event.src_path):
			self.ros_node.get_logger().info(f"New bag file detected: {event.src_path}")
			if self._is_file_complete(event.src_path):
				if self.shutdown_requested:
					return
				self._encrypt_file(event.src_path)

	def on_modified(self, event):
		if self.shutdown_requested:
			return
		if not event.is_directory and self._is_bag_file(event.src_path):
			if self._is_file_complete(event.src_path):
				if self.shutdown_requested:
					return
				self._encrypt_file(event.src_path)

	def wait_for_metadata(self):
		self.ros_node.get_logger().info("Waiting for metadata file...")
		while True:
			if os.path.exists(os.path.join(self.watch_dir, 'metadata.yaml')):
				self.ros_node.get_logger().info("Metadata found")
				return
			time.sleep(0.01)

	# Final pass on shutdown
	def process_final_files(self):
		self.ros_node.get_logger().info(
			f"Processing final files"
		)

		unencrypted_bags = self._find_unencrypted_bags()
		if not unencrypted_bags:
			self.ros_node.get_logger().info("No unencrypted bag files found")
			return

		self.ros_node.get_logger().info(
			f"Found {len(unencrypted_bags)} unencrypted bag file(s)"
		)
		self.wait_for_metadata()
		for bag_file in unencrypted_bags:
			self._encrypt_file(str(bag_file))


class BagCryptoNode(Node):
	"""Minimal ROS2 node for bag file encryption"""

	def __init__(self):
		super().__init__('bag_crypto_node')

		# Parameters
		self.declare_parameter('watch_dir', '')
		self.declare_parameter('public_key_path', '')

		self.watch_dir = self.get_parameter('watch_dir').get_parameter_value().string_value
		self.public_key_path = self.get_parameter('public_key_path').get_parameter_value().string_value

		# Fallback to env var for public key
		if not self.public_key_path:
			self.public_key_path = os.getenv('PUBLIC_KEY_PATH', '')
			if not self.public_key_path:
				self.get_logger().error(
					'Error: missing public_key_path parameter and env var PUBLIC_KEY_PATH not set.'
				)
				raise ValueError('Missing public key path')

		if not self.watch_dir:
			self.get_logger().error('Error: watch_dir parameter is required')
			raise ValueError('Missing watch directory')

		if not os.path.exists(self.public_key_path):
			self.get_logger().error(f'Error: Public key not found: {self.public_key_path}')
			raise FileNotFoundError(f'Public key not found: {self.public_key_path}')

		self.get_logger().info('Bag Crypto Node initialized')
		self.get_logger().info(f'Watch directory: {self.watch_dir}')
		self.get_logger().info(f'Public key: {self.public_key_path}')

		self.event_handler = None
		self.observer = None
		self.is_running = False

		# Auto-start
		self.start_monitoring()

	def start_monitoring(self) -> bool:
		if self.is_running:
			self.get_logger().warning('Service is already running')
			return False
		try:
			self.event_handler = ROSBagCryptoHandler(
				self.public_key_path, self.watch_dir, self
			)
			self.observer = Observer()
			self.observer.schedule(self.event_handler, self.watch_dir, recursive=True)
			self.observer.start()
			self.is_running = True
			self.get_logger().info('Bag encryption monitoring started')
			return True
		except Exception as e:
			self.get_logger().error(f'Failed to start monitoring: {e}')
			return False

	def stop_monitoring(self) -> bool:
		if not self.is_running:
			return False
		
		def async_stop():
			"""Asynchronous observer stop"""
			try:
				if self.observer:
					self.observer.stop()
					# Join avec timeout très court
					self.observer.join(0.1)
			except Exception as e:
				self.get_logger().warning(f"Observer stop exception: {e}")
		
		try:
			if self.event_handler:
				self.event_handler.request_shutdown()
			
			stop_thread = threading.Thread(target=async_stop, daemon=True)
			stop_thread.start()
			
			self.is_running = False
			self.get_logger().info('Bag encryption monitoring stopped (async)')
			return True
		except Exception as e:
			self.get_logger().error(f'Error stopping monitoring: {e}')
			return False

	def destroy_node(self):
		self.get_logger().info('Shutting down bag crypto node…')
		if self.is_running:
			self.stop_monitoring()
			if self.event_handler:
				self.event_handler.process_final_files()
		super().destroy_node()


def main(args=None):
	rclpy.init(args=args)

	node = BagCryptoNode()

	try:
		rclpy.spin(node)
	except (KeyboardInterrupt, ExternalShutdownException):
		node.get_logger().info(f"Received signal, shutting down gracefully…")
		node.destroy_node()
	except Exception as e:
		print(f"Error: {e}")
		if 'node' in locals():
			node.destroy_node()


if __name__ == '__main__':
	main()

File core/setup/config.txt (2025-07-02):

#Cyclosafe specific

dtoverlay=disable-bt
enable_uart=1

dtoverlay=uart1
dtoverlay=uart2
dtoverlay=uart3
dtoverlay=uart5

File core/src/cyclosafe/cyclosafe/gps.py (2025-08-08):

# Created on Tue Aug 05 2025
# Updated on Tue Aug 05 2025
#
#  This file is part of Cyclosafe
# Copyright (c) 2025 Nicolas Pirard @Anvently
#
# This software is governed by the CeCILL license under French law and
# abiding by the rules of distribution of free software. You can use,
# modify and/or redistribute the software under the terms of the CeCILL
# license as circulated by CEA, CNRS and INRIA at:
# https://cecill.info/licences/Licence_CeCILL-B_V1-en.html


import rclpy
from rclpy.node import Node
from rclpy.executors import ExternalShutdownException
from cyclosafe_interfaces.msg import NavSatInfo
from cyclosafe.src.ASerialSensor import ASerialPublisher
from sensor_msgs.msg import NavSatStatus
import math

"""
$GNGLL,4850.45401,N,00235.23105,E,111859.00,A,A*7E                              GPS+GLONASS, geographic position, latitude/longitude
$GNRMC,111900.00,A,4850.45398,N,00235.23110,E,0.139,,180325,,,A*6F              | recommended minimum specific GPS data
$GNVTG,,T,,M,0.139,N,0.258,K,A*39                                               | course over ground and ground speed
$GNGGA,111900.00,4850.45398,N,00235.23110,E,1,10,1.20,88.2,M,46.2,M,,*75        | gps fixed data
$GNGSA,A,3,18,31,28,25,04,16,,,,,,,2.14,1.20,1.77*1C                            | gnss dop and active satellite
$GNGSA,A,3,86,75,76,67,,,,,,,,,2.14,1.20,1.77*15                                | gnss dop and active satellite
$GPGSV,3,1,12,04,11,317,12,05,15,078,,09,02,345,15,16,20,293,24*72              GPS gnss satellites in view
$GPGSV,3,2,12,18,44,163,29,20,13,043,16,25,32,114,24,26,47,296,20*71            | 
$GPGSV,3,3,12,28,50,212,19,29,64,059,,31,57,255,19,49,34,177,*78                |
$GLGSV,3,1,10,66,00,281,,67,11,328,19,68,07,014,,74,13,133,*61                  GLONASS
$GLGSV,3,2,10,75,65,125,30,76,48,319,30,77,04,316,,84,24,034,*69                |
$GLGSV,3,3,10,85,76,068,14,86,38,200,32*65                                      |

4, 5, 9, 16
18, 20, 25, 26
28, 29, 31, 49
66, 67, 68, 74
75, 76, 77, 84
85, 86

GLL => geographic position, latitude/longitude
RMC => recommended minimum specific GPS data
VTG => course over ground and ground speed
GGA => gps fixed data
GSA => gnss dop and active satellites
GSV => gnss satellites in view
Ex: 
 3,1,10,66,00,281,,67,11,328,19,68,07,014,,74,13,133,*61       
 3, 1 => message 1/3
 10 => total nbr of satellite in view
 66 => PRV of satellite (ID)
 00, 281, ?, 67 => élévation, azimut, SNR

- on veut :
	- latitude/longitude => GLL
	- hdop => GSA
	

"""


class GPSPublisher(ASerialPublisher):
	
	def __init__(self):
		super().__init__('gps', NavSatInfo, 'gps', '/dev/ttyACM0', 115200)
		self.latitude = float('NaN')
		self.longitude = float('NaN')
		self.hdop = float('NaN')
		self.pdop = float('NaN')
		self.ground_speed = float('NaN') # km/h
		self.active_sat = 0
		self.current_active = None
		self.altitude = float('NaN')
		self.status = NavSatStatus(status=NavSatStatus.STATUS_UNKNOWN)

	def parse(self) -> bool:
		"""Update stored values from GPS input. Return true if one or more value were updated"""
		update: bool = False
		lines = self.buffer.split(b'\n')
		update = False
		for line in lines[0:-1]: #Do not parse last line because it could be partial
			# TODO Check if the last line is complete or not
			words = line.decode("utf-8").split(',')
			message_type = words[0][3:]
			if (message_type == "GLL"):
				self.latitude = GPSPublisher.nmea_to_decimal(float(words[1])) if words[1] != '' else float('NaN')
				self.longitude = GPSPublisher.nmea_to_decimal(float(words[3])) if words[3] != '' else float('NaN')
				
				update = True
			elif (message_type == "GSA"):
				self.hdop = float(words[16]) if words[16] != '' else float('NaN')
				self.pdop = float(words[15]) if words[15] != '' else float('NaN')
				if self.current_active == None:
					self.current_active = sum(1 if word != "" else 0 for word in words[3:14])
				else:
					self.current_active += sum(1 if word != "" else 0 for word in words[3:14])
				update = True
			elif (message_type == "GGA"):
				self.altitude = float(words[9]) if words[9] != '' else float('NaN')
				update = True
			elif (message_type == "RMC"):
				#RMC is used as a reset marker for active satellites
				self.active_sat = self.current_active or 0
				self.current_active = None
				self.status.service = 0
				self.ground_speed = (float(words[7]) * 1.852) if words[7] != '' else float('NaN')
				update = True
			elif (message_type == "VTG"):
				self.ground_speed = float(words[7]) if words[7] != '' else float('NaN')
				update = True
			service = words[0][1:3]
			if (service == "GN"):
				self.status.service |= NavSatStatus.SERVICE_GPS | NavSatStatus.SERVICE_GLONASS
			elif (service == "GP"):
				self.status.service |= NavSatStatus.SERVICE_GPS
			elif (service == "GL"):
				self.status.service |= NavSatStatus.SERVICE_GLONASS
			elif (service == "GA"):
				self.status.service |= NavSatStatus.SERVICE_GALILEO
		if len(lines) > 1:
			self.buffer = b'\n'.join(lines[:-1])
		if not math.isnan(self.longitude) and not math.isnan(self.latitude):
			self.status.status = NavSatStatus.STATUS_FIX
		else:
			self.status.status = NavSatStatus.STATUS_NO_FIX
		return update
	
	def publish(self, data: NavSatInfo):
		"""
			TODO: Use timestamp sent by device instead of current
		"""
		msg = NavSatInfo(
			latitude=self.latitude, longitude = self.longitude, altitude = self.altitude,
			hdop = self.hdop, pdop = self.pdop,
			ground_speed = self.ground_speed, actives_sat = self.active_sat, status = self.status
		)
		msg.header.stamp = self.get_clock().now().to_msg()
		self.get_logger().debug(
			f"lat={msg.latitude},\
lon={msg.longitude},\
alt={self.altitude},\
speed={self.ground_speed},\
actives={self.active_sat},\
hdop={self.hdop},\
pdop={self.pdop}")
		self.pub.publish(msg)

	
	def nmea_to_decimal(nmea_coord):
		""" Convertit une coordonnée du format NMEA (DDMM.MMMMM) au format décimal.
		Args:
			nmea_coord (float): Coordonnée au format NMEA
		Returns:
			float: Coordonnée en format décimal
		"""
		nmea_str = str(nmea_coord)
		words = nmea_str.split('.')
		degres = 0
		if len(words[0]) <= 2:
			minutes = float(words[0] + '.' + words[1])
		else:
			degres = float(words[0][0:-2])
			minutes = float(words[0][-2:] + '.' + words[1])
		value = degres + (minutes / 60.0)
		return value


def main(args=None):
	try:
		rclpy.init(args=args)
		sensor_publisher = GPSPublisher()
		rclpy.spin(sensor_publisher)
	
	except (KeyboardInterrupt, ExternalShutdownException):
		pass


if __name__ == '__main__':
	main()

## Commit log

2025-03-12 sensor node
2025-03-12 added launch file with parameterized sensor node
2025-03-12 aded camera node (not tested)
2025-03-12 added camera_cv node
2025-03-13 camera node working - need to implement image queue
2025-03-14 added abstract serial sensor node and updated sensor example, added gps publisher base code
2025-03-17 fixed wheel
2025-03-18 fix exception handler for parsing serial node
    [gps.py]
2025-03-19 added cpp lidar node
2025-03-20 cpp lidar node: serial class implemented, some issue with line parsing and non printable character
2025-03-20 fixed lidar cpp
2025-03-21 fixed camera_webcam node. Start to work on aggregator node in cpp instead of python (renamed it hub_node)
    [camera_webcam.py]
2025-03-24 hub timestamps fixed and working. TODO: Need the camera node to use ms timestamp synchronized with the hub. Need something else (forgot)
    [gps.py]
2025-03-28 added port name resolution + changed camera frquency
2025-03-28 optimize camera node
2025-03-28 fixed camera
2025-03-28 added debug print
2025-04-03 4 sonar config + rplidar on uart
2025-04-03 tag update sonar
2025-04-03 removed camera preview
2025-04-03 camera adjust
2025-04-04 updated sonar visualizations
2025-04-04 update sonar frequency
2025-04-04 sonar tests
2025-04-04 fixed camera colors
2025-04-09 debugging sonar error flow
2025-04-09 added sonar5
2025-04-09 debugging sonar
2025-04-09 fixed sonar debug
2025-04-11 implemented depassement/croisement custom form, highlight current peaks
2025-04-16 modif launch config to work with 2 rs232 sonars
2025-04-16 added unit parameter for serial sensor, added sonar_rs232 node
2025-04-17 implemented sonar_sr04 node removed the ability to update parameter after the node start for ASerialSensor (too much issue with CPU load and seems useless)
2025-04-23 - added node to use LV10X0 sonar with pulse width
2025-04-23 - added ldlidar node submodule - removed sonar from launch config - redone package structure - added ldlidar launch description into cyclosafe.launch.py
    [LD19.stl]
2025-04-24 gps parsing updated to be more resilient with other service - fixed active sat counting - TODO: gps L80-m39 sometime raises serial exception repetively
    [gps.py]
2025-04-24 added battery monitor script + killswitch in gpio script
2025-04-24 Cyclosafe lidar cpp package: - implemented new methods on Serial - implemented abstract driver class for all 3 benewake lidar
2025-04-25 cyclosafe lidar node and driver done and compiled without warning. Not tested
2025-04-25 deleted ldlidar submodule for stl-19 (it was the wrong reference
2025-04-25 added ldlidar stl27l submodule + added node to launch config + added rplidar to launch config (2x360° lidar)
2025-04-29 ldlidar is now a forked repo fixed pull up config for button
    [gpio.py]
2025-04-30 debugging tof lidar
2025-04-30 - refacto both launch files including a central config module - fixed lidar undefined frame_id - tof lidar working - sonar_lv_pw very instable - WORKING ON: tf-mini-plus, not working: some issues wit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
2025-05-05 driver not working yet, some issue with serial configuration
2025-05-06 benewake lidar driver tested and working in both free running and trigger mode (for tf-mini-plus and tf-02)
2025-05-06 - added benewake lidars to launch config - expanded port resolution to node parameter (matching any 'port' or 'serial_port' parameter)
2025-05-06 both benewake lidar share the same config rplidar is now vertical at the back
2025-05-07 - lidar node are now locking serial port for themselves
2025-05-07 enable file splitting on bag record re-enabled camera node
2025-05-12 - added python script to import bag via scp and decompress + convert them into single bag - fixed tof_lidar + benewake_lidar : invalid strength result as a published nan - range_circle_transform : de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
2025-05-14 enabled stl27 lidar
2025-05-15 - viewer launch configuration now use urdf model (with 3d models) to transform everything to world frame - battery monitor script updated to use a different ina219 library - added rviz_satellite plug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
    [rplidar_c1.stl, tf-02.stl, tf-mini-plus.stl]
2025-05-16 import_recordings.py: implemented bag reparation, gps_exporter.py: script to export gps topic to gpx trace
2025-05-16 script finished but not tested, rplidar and ldlidar are not submodule anymore
    [LD19.stl, config.txt, rplidar_c1.stl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]
2025-05-19 lots of readme added
    [LD19.stl, rplidar_c1.stl, tf-02.stl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]
2025-05-20 few fixes and readme improved
    [camera_pi.py, camera_webcam.py]
2025-05-20 made battery_monitor script executable
2025-05-21 moved viewer packages to viewer/src
    [LD19.stl, rplidar_c1.stl, tf-02.stl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]
2025-05-23 rm video file, video is now a user attachment
2025-06-30 prod update
    [kicad.kicad_pcb, kicad.kicad_sch]
2025-06-30 cleaning non-used nodes and packages, implemented some CONSTANT variables for gpio.py as env variables + added disk storage monitoring
    [config.txt]
2025-06-30 edited library path for kicad symbol
    [kicad.kicad_pcb, kicad.kicad_sch]
2025-06-30 added design folder in prod branch
    [kicad.kicad_pcb, kicad.kicad_sch, ups-unit.kicad_sch]
2025-07-02 added design files
    [assemblage-F.stl, boitier-bas.stl, boitier-haut.stl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]
2025-07-02 added bom file
    [bom.csv]
2025-07-02 ajout de visuels
2025-07-02 ajout de visuels pour le boitier coupe en deux
2025-07-16 - changed camera config to consume less storage - fix on scripts - doc updated
    [gpio.py, gps.py]
2025-08-04 fixed gps_time script (month were treated as octal numbers), updated LICENCE and added NOTICE + licence section in readme, add manuel, readded gpx_exporter.py, removed extra files, commented independ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
    [LD19.stl, module.obj, rplidar_c1.stl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]
2025-08-05 added feature in cyclosafe_player to visualize lidar data as curve, sampling range of points defined with min_angle and max_angle
2025-08-07 cyclosafe_player: visualize gps trace on map widget + live position + added gps data curve and live output
2025-08-07 updated cyclosafe_player image preview, changed shutdown button max latency from 0.5s to 0.25s
2025-08-11 ajout des 3 fichiers script csv converter + contributions added
2025-08-13 missing import in gpio.py
    [gpio.py]
2025-08-14 added schematic, implemented invert_lidar argument
2025-08-20 encryption base setup replaced all csv_conversion with single bag_converter.py
    [encryptor.py]
2025-08-21 fix: observer thread join not blocking anymore, number of expected node is checked twice, fix warning command to check if module is shutdown while cyclosafed.service still active
    [encryptor.py]
2025-08-21 reduced delay for encryptor stability from 3 to 2s, and increased systemd stop timeout from 10s to 13s
    [encryptor.py]
2025-08-22 VERSION 1.2 encryptor: process_final_files now check for metadata.yaml existence instead of checking file stability gpio.py : use gpiozero instead of pigpio removed pigpiod service
    [encryptor.py, gpio.py]
2025-08-22 added no_compression parameter for camera node
2025-08-28 updated stl files + small opti in bag_converter + new manual version
    [assemblage-F.stl, assemblage-femelle.stl, boitier-bas.stl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]
